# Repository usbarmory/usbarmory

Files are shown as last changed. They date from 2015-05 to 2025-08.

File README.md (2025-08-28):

Introduction
============

The USB armory is an open source hardware design, implementing a compact secure
computer.

This repository is aimed towards developers, if you wish to purchase a USB
armory board please see the [ordering information](https://github.com/usbarmory/usbarmory/wiki/Ordering-information).

Authors
=======

Andrea Barisani  
andrea@inversepath.com  

Andrej Rosano  
andrej@inversepath.com  

Daniele Bianco  
daniele@inversepath.com  

Documentation
=============

The main documentation can be found on the
[project wiki](https://github.com/usbarmory/usbarmory/wiki).

Board models
============

* [USB armory Mk II LAN](https://github.com/usbarmory/usbarmory/wiki/Mk-II-LAN)

Mk II LAN Top
Mk II LAN PoE

* [USB armory Mk II](https://github.com/usbarmory/usbarmory/wiki/Mk-II-Introduction)

Mk II Top
Mk II Bottom

* USB armory Mk I

USB armory Mk I

License
=======

USB armory | https://github.com/usbarmory/usbarmory  
Copyright (c) The USB armory authors

This is an open hardware design licensed under the terms of the CERN Open
Hardware Licence, see board revisions for applicable versions.

This source is distributed WITHOUT ANY EXPRESS OR IMPLIED WARRANTY, INCLUDING
OF MERCHANTABILITY, SATISFACTORY QUALITY AND FITNESS FOR A PARTICULAR PURPOSE.

Please see LICENSE files in each source subdirectory for applicable conditions.

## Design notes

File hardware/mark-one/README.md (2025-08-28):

Introduction
============

The USB armory is an open source hardware design, implementing a flash drive
sized computer.

This repository is aimed towards developers, if you wish to purchase a USB
armory board please see the [ordering information](https://github.com/usbarmory/usbarmory/wiki/Ordering-information).

Authors
=======

Andrea Barisani  
andrea@inversepath.com  

Andrej Rosano  
andrej@inversepath.com  

Daniele Bianco  
daniele@inversepath.com  

Revision information
====================

This directory contains the hardware design for the USB armory board, first
revision (Mark I).

Current schematics and layout files have been designed in KiCad (`release
2014-01-25 - 0.201403191418+4754~10~ubuntu12.04.1`)

PCB information
===============

Mk I Top
Mk I Bottom

6 layers, 2.00mm thickness  
Outer layers 0.5 oz base copper foil  
Inner layers   1 oz base copper foil  
width (X) 65.6 mm, height (Y) 19.5 mm  
Electroless Nickel Immersion Gold (ENIG) surface finish  
Selective hard gold (min 0.75um) plating for J2 (USB)  
Black resist, white component legend

Layers
------

Order and type of copper layers:  
  TOP:         signal, front components  
  SIGNAL 1:    signal  
  GND POWER 1: ground and power plane  
  GND POWER 2: ground and power plane  
  SIGNAL 2:    signal  
  BOTTOM:      signal, back components  

| Layer | Description |  Thickness (in um)  |
|:-----:|---|:---:|
| | LPI mask | 15 |
| | ENIG plating | 18 |
| 1 | copper | 17 |
| | prepreg, 3 x PP 1080 |  240 -> 220 |
| 2 | copper | 35 |
| | core, FR4  35/35 |  300 |
| 3 | copper | 35 |
| | prepreg, 4 x PP 7628 |  760 -> 720 |
| 4 | copper | 35 |
| | core, FR4  35/35 |  300 |
| 5 | copper | 35 |
| | prepreg, 3 x PP 1080 |  240 -> 220 |
| 6 | copper | 17 |
| | ENIG plating | 18 |
| | LPI mask | 15 |

Material: Isola PCL370-HR
Total thickness: 2.0 mm

DRC information
---------------

Minimum track width:            0.127 mm  
Minimum via diameter:           0.406 mm  
Outer layer track width:        0.127 mm  
Outer layer isolation distance: 0.127 mm  
Outer layer annular ring:       0.075 mm  
Inner layer track width:        0.127 mm  
Inner layer isolation distance: 0.127 mm  
Inner layer annular ring:       0.075 mm  
Smallest final hole (plated):   0.150 mm

Regulatory compliance & handling
================================

The USB armory board is intended for use as a development platform for hardware
or software. The board is an open system design, which does not include a
shielded enclosure. This may cause interference to other electrical or
electronic devices in close proximity. In a domestic environment, this product
may cause radio interference in which case the user may be required to take
adequate measures. In addition, this board should not be used near any medical
equipment or RF devices.

The board is sensitive to ESD. Hold the board only by its edges. After removing
the board from its box, place it on a grounded, static-free surface.

The board can become hot, like any fan-less design, during continuous high CPU
loads, mind its temperature while handling it.

License
=======

USB armory | https://github.com/usbarmory/usbarmory  
Copyright (c) The USB armory authors

This is an open hardware design licensed under the terms of the CERN Open
Hardware Licence (OHL) v1.2.

You may redistribute and modify this documentation under the terms of the CERN
OHL v.1.2 (http://ohwr.org/cernohl). This documentation is distributed WITHOUT
ANY EXPRESS OR IMPLIED WARRANTY, INCLUDING OF MERCHANTABILITY, SATISFACTORY
QUALITY AND FITNESS FOR A PARTICULAR PURPOSE. Please see the CERN OHL v.1.2 for
applicable conditions.

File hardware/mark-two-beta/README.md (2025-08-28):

Introduction
============

The USB armory is an open source hardware design, implementing a flash drive
sized computer.

This repository is aimed towards developers, if you wish to purchase a USB
armory board please see the [ordering information](https://github.com/usbarmory/usbarmory/wiki/Ordering-information).

Authors
=======

Andrea Barisani  
andrea@inversepath.com  

Andrej Rosano  
andrej@inversepath.com  

Daniele Bianco  
daniele@inversepath.com  

Documentation
=============

The main documentation can be found on the
[project wiki](https://github.com/usbarmory/usbarmory/wiki).

Revision information
====================

This directory contains the hardware design for the USB armory Mk II rev. β.

Current schematics and layout files have been designed in KiCad 5.1.4.

PCB Information
===============

Mk II Top
Mk II Bottom

6 layers, 0.8mm thickness  
Outer layers 0.5 oz base copper foil  
Inner layers   1 oz base copper foil  
width (X) 65.6 mm, height (Y) 19.5 mm  
Electroless Nickel Immersion Gold (ENIG) surface finish  
Black resist, white component legend

Layers
------

Order and type of copper layers:  
  TOP:         signal, front components  
  SIGNAL 1:    signal  
  GND POWER 1: ground and power plane  
  GND POWER 2: ground and power plane  
  SIGNAL 2:    signal  
  BOTTOM:      signal, back components  

| Layer | Description |  Thickness (in um)  |
|:-----:|---|:---:|
| | LPI mask | 15 |
| | ENIG plating | 18 |
| 1 | copper | 30 |
| | prepreg, 2 x PP 106 |  121 |
| 2 | copper | 17 |
| | core, FR4 17/17 |  125 |
| 3 | copper | 17 |
| | prepreg, 2 x PP 106 |  116 |
| 4 | copper | 17 |
| | core, FR4 17/17 |  125 |
| 5 | copper | 17 |
| | prepreg, 2 x PP 106 |  121 |
| 6 | copper | 30 |
| | ENIG plating | 18 |
| | LPI mask | 15 |

Material: Isola PCL370-HR
Total thickness: 0.8 mm

DRC information
---------------

Minimum track width:            0.100 mm  
Minimum via diameter:           0.406 mm  
Outer layer track width:        0.100 mm  
Outer layer isolation distance: 0.100 mm  
Outer layer annular ring:       0.075 mm  
Inner layer track width:        0.100 mm  
Inner layer isolation distance: 0.100 mm  
Inner layer annular ring:       0.075 mm  
Smallest final hole (plated):   0.150 mm

Regulatory compliance & handling
================================

The USB armory board is an open system design, which does not include a
shielded enclosure. This may cause interference to other electrical or
electronic devices in close proximity. In a domestic environment, this product
may cause radio interference in which case the user may be required to take
adequate measures. In addition, this board should not be used near any medical
equipment or RF devices.

The board is sensitive to Electrostatic discharge (ESD). Hold the board only by
its edges. After removing the board from its box, place it on a grounded,
static-free surface.

The board can become hot, like any fan-less design, during continuous high CPU
loads, mind its temperature while handling it.

* [Compliance information](https://github.com/usbarmory/usbarmory/wiki/Compliance-information)

License
=======

USB armory | https://github.com/usbarmory/usbarmory  
Copyright (c) The USB armory authors

This is an open hardware design licensed under the terms of the CERN Open
Hardware Licence (OHL) v1.2.

You may redistribute and modify this documentation under the terms of the CERN
OHL v.1.2 (http://ohwr.org/cernohl). This documentation is distributed WITHOUT
ANY EXPRESS OR IMPLIED WARRANTY, INCLUDING OF MERCHANTABILITY, SATISFACTORY
QUALITY AND FITNESS FOR A PARTICULAR PURPOSE. Please see the CERN OHL v.1.2 for
applicable conditions.

The following exceptions apply:

- `../lib.snapeda`: all files in this directory are imported or modified
  from SnapEDA symbols and footprints, therefore the license at
  https://www.snapeda.com/about/FAQ/#license applies.

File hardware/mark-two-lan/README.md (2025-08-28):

Introduction
============

The USB armory is an open source hardware design, implementing a compact secure
computer.

This repository is aimed towards developers, if you wish to purchase a USB
armory board please see the [ordering information](https://github.com/usbarmory/usbarmory/wiki/Ordering-information).

Authors
=======

Andrea Barisani  
andrea@inversepath.com  

Andrej Rosano  
andrej@inversepath.com  

Daniele Bianco  
daniele@inversepath.com  

Documentation
=============

The main documentation can be found on the
[project wiki](https://github.com/usbarmory/usbarmory/wiki).

Revision information
====================

This directory contains the hardware design for the USB armory Mk II LAN rev. β.

Current schematics and layout files have been designed in KiCad 7.0.3.

PCB Information
===============

 

6 layers, 0.8mm thickness  
Outer layers 0.5 oz base copper foil  
Inner layers   1 oz base copper foil  
width (X) 65.6 mm, height (Y) 19.5 mm  
Electroless Nickel Immersion Gold (ENIG) surface finish  
Black resist, white component legend

Layers
------

Order and type of copper layers:  
  TOP:         signal, front components  
  SIGNAL 1:    signal  
  GND POWER 1: ground and power plane  
  GND POWER 2: ground and power plane  
  SIGNAL 2:    signal  
  BOTTOM:      signal, back components  

| Layer | Description |  Thickness (in um)  |
|:-----:|---|:---:|
| | LPI mask | 15 |
| | ENIG plating | 18 |
| 1 | copper | 30 |
| | prepreg, 2 x PP 106 |  121 |
| 2 | copper | 17 |
| | core, FR4 17/17 |  125 |
| 3 | copper | 17 |
| | prepreg, 2 x PP 106 |  116 |
| 4 | copper | 17 |
| | core, FR4 17/17 |  125 |
| 5 | copper | 17 |
| | prepreg, 2 x PP 106 |  121 |
| 6 | copper | 30 |
| | ENIG plating | 18 |
| | LPI mask | 15 |

Material: Isola PCL370-HR
Total thickness: 0.8 mm

DRC information
---------------

Minimum track width:            0.100 mm  
Minimum via diameter:           0.406 mm  
Outer layer track width:        0.100 mm  
Outer layer isolation distance: 0.100 mm  
Outer layer annular ring:       0.050 mm  
Inner layer track width:        0.100 mm  
Inner layer isolation distance: 0.100 mm  
Inner layer annular ring:       0.050 mm  
Smallest final hole (plated):   0.127 mm

Regulatory compliance & handling
================================

The USB armory board is an open system design, which does not include a
shielded enclosure. This may cause interference to other electrical or
electronic devices in close proximity. In a domestic environment, this product
may cause radio interference in which case the user may be required to take
adequate measures. In addition, this board should not be used near any medical
equipment or RF devices.

The board is sensitive to Electrostatic discharge (ESD). Hold the board only by
its edges. After removing the board from its box, place it on a grounded,
static-free surface.

The board can become hot, like any fan-less design, during continuous high CPU
loads, mind its temperature while handling it.

* [Compliance information](https://github.com/usbarmory/usbarmory/wiki/Compliance-information)

License
=======

USB armory | https://github.com/usbarmory/usbarmory  
Copyright (c) The USB armory authors

This source describes Open Hardware and is licensed under the CERN-OHL-S v2.

You may redistribute and modify this source and make products using it under
the terms of the CERN-OHL-S v2 (https://ohwr.org/cern_ohl_s_v2.txt).

This source is distributed WITHOUT ANY EXPRESS OR IMPLIED WARRANTY, INCLUDING
OF MERCHANTABILITY, SATISFACTORY QUALITY AND FITNESS FOR A PARTICULAR PURPOSE.
Please see the CERN-OHL-S v2 for applicable conditions.

As per CERN-OHL-S v2 section 4, should You produce hardware based on this
source, You must where practicable maintain the Source Location visible on the
external case of the USB armory or other products you make using this source.

The following exceptions apply:

- `../lib.snapeda`: all files in this directory are imported or modified
  from SnapEDA symbols and footprints, therefore the license at
  https://www.snapeda.com/about/FAQ/#license applies.

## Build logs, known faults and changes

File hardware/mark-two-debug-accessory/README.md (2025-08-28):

USB armory Mk II debug accessory
================================

The USB armory is an open source hardware design, implementing a flash drive
sized computer.

The USB armory Mk II exposes a USB Type-C receptacle, which allows through the
so called USB-C 'debug accessory mode' to route analog/debug signals over its
connector, the USB armory Mk II design leverages on this to break out UART,
SPI, I²C, CAN (pre-transceiver), GPIOs connections to/from its application
processor.

The debug accessory board allows to access UART and GPIO signals through USB,
without requiring probes, through an FTDI FT4232H. This allows, for example,
access to the USB armory Mk II serial console without wires or probes, natively
using only USB cables. All other interfaces can be accessed through dedicated
breakout through holes.

This repository is aimed towards developers, if you wish to purchase a USB
armory board please see the [USB armory documentation](https://github.com/usbarmory/usbarmory/wiki).

Mk II debug accessory

PCB Information
===============

Mk II debug accessory

2 layers, 0.80mm thickness, top only components  
Outer layers 0.5 oz base copper foil  
Inner layers   1 oz base copper foil  
width (X) 45.65 mm, height (Y) 25.90 mm  
Red soldermask, white component legend

[Bill of materials](https://usbarmory.github.io/BOM/usbarmory-mark-two-debug-accessory.html)

DRC information
---------------

Minimum track width:            0.127 mm  
Minimum via diameter:           0.450 mm  
Outer layer track width:        0.127 mm  
Outer layer isolation distance: 0.127 mm  
Outer layer annular ring:       0.100 mm  
Smallest final hole (plated):   0.150 mm

Errata
------

The silkscreen labels for `3.3V` and `5V` are inverted on all rev v1 PCBs, see
this [issue](https://github.com/usbarmory/usbarmory/issues/68).

USB armory Mk II debug I/Os
===========================

*NOTE*: the connection between the debug accessory and the target is supported
only with the same orientation for both top layers (side with components for
the accessory, side with LEDs for the USB armory).

The following table summarizes the available configurations on the USB armory
Mk II through debug accessory mode, which are exposed on its Type-C receptacle
port.

|  USB-C pin | MUX mode ALT0 | MUX mode ALT8 | MUX mode ALT2 | MUX mode ALT5 |
|:---|---|---|---|---|
| SSTXp1 (A2)  | UART2_TX | ECSPI3_SSO¹ | I2C4_SCL¹ | GPIO1_IO20 |
| SSTXn1 (A3)  | UART2_RX | ECSPI3_SCLK¹  | I2C4_SDA¹ | GPIO1_IO21 |
| SSRXp1 (B11) | UART2_RTS_B | ECSPI3_MISO¹  | FLEXCAN2_RX¹  | GPIO1_IO23 |
| SSRXn1 (B10) | UART2_CTS_B | ECSPI3_MOSI¹  | FLEXCAN2_TX¹  | GPIO1_IO22 |
| SSRXp2 (A11) | UART4_TX | ECSPI2_SCLK | I2C1_SCL | GPIO1_IO28 |
| SSTXn2 (B3)  | UART4_RX | ECSPI2_SSO | I2C1_SDA | GPIO1_IO29 |
| SSRXn2 (A10) | UART5_TX~ | ECSPI2_MOSI | I2C2_SCL | GPIO1_IO30 |
| SSTXp2 (B2)  | UART5_RX~ | ECSPI2_MISO | I2C2_SDA | GPIO1_IO31 |

¹ Only on USB armory Mk II boards mounting i.MX6UL SoC, not available on
  versions mounting the i.MX6ULZ.

Serial console
--------------

When running the [USB armory Debian base image](https://github.com/usbarmory/usbarmory-debian-base_image/releases)
the serial console (UART2) can be accessed, with the debug accessory jumper set to UART
position, as follows (example on Linux host with picocom):

```
picocom -b 115200 -eb /dev/ttyUSB2 --imap lfcrlf
```

Debug accessory jumper settings
===============================

Power source
------------

The debug accessory always acts as a power source and is meant to be connected
exclusively to the USB armory Mk II Type-C receptacle port. The USB armory Mk
II Type-C can be safely plugged on a different receptacle as the board can
handle two power sources simultaneously.

It is not recommended to connect the debug accessory to anything other than the
USB armory Mk II, however in case this happens compliant Type-C receptacles
should handle the situation gracefully¹ without concerns.

¹ USB Type-C Cable and Connector Specification (1.3, 2017-07-14):
  "Legacy hosts/chargers that by default source VBUS when connected using any
  legacy USB connector (Standard-A, Micro-B, etc.) to USB Type-C cable or adapter
  are exempted from these two requirements."

I/O mode
--------

The GPIO and UART functions can be used directly using the FTDI FT4232H USB
interface accessible on the Micro USB Type-B connector, all other modes can be
accessed using the exposed breakout through holes.

The following table illustrates the required jumper positions and interfaces
for each available I/O mode.

| Mode  | GPIO¹ | Interface
|:---|---|---|
| GPIO  |  GPIO | FTDI MPSSE mode on [A,B]DBUS[4-7] |
| UART2 | !GPIO | FTDI RS232 mode on CDBUS[0-3] |
| UART4 | !GPIO | FTDI RS232 mode on BDBUS[0-1] |
| UART5 | !GPIO | FTDI RS232 mode on ADBUS[0-1] |
| SPI2  |  N/A² | through holes: A11, B3, A10, B2 |
| SPI3  |  N/A² | through holes: A2,  A3, B11, B10  |
| I2C1  |  N/A² | through holes: A11, B3 |
| I2C2  |  N/A² | through holes: A10, B2 |
| I2C4  |  N/A² | through holes: A2,  A3 |
| CAN2  |  N/A² | through holes: B11, B10 |

¹ The GPIO header position refers to termination either of the two pins facing
  the "GPIO" label (GPIO position, pins towards positions 3 and 2) or the
  opposite position (!GPIO position, pins towards positions 2 and 1).

² Any position can be used as the FTDI is not used in such mode.

Pin assignment: GPIO
====================

|  USB-C pin | i.MX6UL pin | FTDI pin | FTDI MPSSE |
|:---|---|---|---|
| SSTXp1 (A2)  | GPIO1_IO20  | BDBUS6 | #B GPIOL2  |
| SSTXn1 (A3)  | GPIO1_IO21  | BDBUS7 | #B GPIOL3  |
| SSRXp1 (B11) | GPIO1_IO23  | BDBUS5 | #B GPIOL1  |
| SSRXn1 (B10) | GPIO1_IO22  | BDBUS4 | #B GPIOL0  |
| SSRXp2 (A11) | GPIO1_IO28  | ADBUS4 | #A GPIOL0  |
| SSTXn2 (B3)  | GPIO1_IO29  | ADBUS7 | #A GPIOL3  |
| SSRXn2 (A10) | GPIO1_IO30  | ADBUS5 | #A GPIOL1  |
| SSTXp2 (B2)  | GPIO1_IO31  | ADBUS6 | #A GPIOL2  |

Pin assignment: UART2
=====================

|  USB-C pin | i.MX6UL pin  | FTDI pin | FTDI MPSSE |
|:---|---|---|---|
| SSTXp1 (A2)  | UART2_TX | CDBUS1 | #C RXD |
| SSTXn1 (A3)  | UART2_RX | CDBUS0 | #C TXD |
| SSRXp1 (B11) | UART2_RTS_B¹ | CDBUS3 | #C CTS |
| SSRXn1 (B10) | UART2_CTS_B¹ | CDBUS2 | #C RTS |

¹ On USB armory Mk II rev. β see the [related errata](https://github.com/usbarmory/usbarmory/wiki/Errata-(Mk-II)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).

Pin assignment: UART4
=====================

|  USB-C pin | i.MX6UL pin | FTDI pin | FTDI MPSSE |
|:---|---|---|---|
| SSRXp2 (A11) | UART4_TX | BDBUS1 | #B RXD |
| SSTXn2 (B3)  | UART4_RX | BDBUS0 | #B TXD |

Pin assignment: UART5
=====================

|  USB-C pin | i.MX6UL pin | FTDI pin | FTDI MPSSE |
|:---|---|---|---|
| SSRXn2 (A10) | UART5_TX | ADBUS1 | #A RXD |
| SSTXp2 (B2)  | UART5_RX | ADBUS0 | #A TXD |

Physical access: UART2
======================

When no debug accessory is available, the serial console (UART2) can be also
accessed with a USB-C plug breakout and a USB to 3.3 TTL serial cable with the
following configuration.

|  PIN | Config |
|:---|---|
| A4, A5 | 56 kOhm |
| B4, B5 | 56 kOhm |
| A2, A3 | 3.3V UART TX/RX |
| A4 | 5V |
| A1 | GND |

License
=======

USB armory | https://github.com/usbarmory/usbarmory  
Copyright (c) The USB armory authors

This is an open hardware design licensed under the terms of the CERN Open
Hardware Licence (OHL) v1.2.

You may redistribute and modify this documentation under the terms of the CERN
OHL v.1.2 (http://ohwr.org/cernohl). This documentation is distributed WITHOUT
ANY EXPRESS OR IMPLIED WARRANTY, INCLUDING OF MERCHANTABILITY, SATISFACTORY
QUALITY AND FITNESS FOR A PARTICULAR PURPOSE. Please see the CERN OHL v.1.2 for
applicable conditions.

The following exceptions apply:

- `../lib.snapeda`: all files in this directory are imported or modified
  from SnapEDA symbols and footprints, therefore the license at
  https://www.snapeda.com/about/FAQ/#license applies.

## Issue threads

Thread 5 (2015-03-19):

IP in your example images

pmpbar, 2015-03-19:
Hello,
Love the product. However, using the default IP that the device is hosted at causes problems when the external network passes out IP's in a weird fashion at my University(extended network with lots of routers). 10.0.0.1 is a hidden IP so when I connect (with internet sharing on) two either the internet or the armory then the other system the ssh connection hoses. If you changed the IP of the device to something other than a gateway address this might solve the problem. Maybe this is just a special case. I'm on a Macbook Pro using your mk1 board. Let me know if I am doing something wrong or if this is just a special case.

danbia, 2015-03-19:
Conflicts in IP addresses might always happen no matter which one we select, the right course of action is not for us to change the IP address on the default image, but rather for you to change it to something that suits your network environment.

Please connect to the USB armory, become administrator and change the default configuration in /etc/network/interfaces to an IP address compatible with your environment.

pmpbar, 2015-03-19:
Sounds good! Just thought I would bring it to your attention

pmpbar, 2015-03-19:
After testing on a different network, this is not because of the IP. It is because osx is switching the requests to a different interface I think. I cannot login as long as the computer is connected to a network. Even if I am ssh'd in, after I connect to a network the connection hoses

abarisani, 2015-03-19:
This still indicates some conflict in your network configuration, if the subnet of your Internet/LAN connection and the USB armory one are different then there is no conflict and you can use both connections at the same time.

In fact if you assign an IP address between the range 192.168.2.2-192.168.2.254 to the armory interface, and use 192.168.2.1 as default gateway, you can even share your Internet connection with the USB armory on MAC OS X.

Closed 2015-03-19.

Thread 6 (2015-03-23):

Getting Started page

rkt88edmo, 2015-03-23:
"MPORTANT: please note that the microSD slot is with "hinge" type insertion and not a pull-push slot. In order to open it gently ****lift**** the closed metal hinge towards the opposite direction of the little arrow engraved on it, a small "click" indicates successful opening."

Using "lift" is confusing, you need to "slide" the metal tab to unlock it prior to lifting.  Just a wording suggestion.

abarisani, 2015-03-23:
Fixed. Thanks.

Closed 2015-03-23.

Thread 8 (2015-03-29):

Connecting

darakian, 2015-03-29:
Hi guys. I downloaded the default image and dd'd it to my sdcard as the instructions state here
http://dev.inversepath.com/download/usbarmory/
When I connect my armory to my laptop (fedora 21) I get a new network device (enp0s26u1u2), but I sshing to 10.0.0.1 fails. I have no route to that address and I'm wondering if I need to set up the route manually. Any thoughts?

Edit:
Tried to add a route via
route add -net 10.0.0.0 netmask 255.255.255.0 gw 10.0.0.2 dev enp0s26u1u2
and I get back
SIOCADDRT: Network is unreachable

andrejro, 2015-03-29:
Hi,
did you assign the address to the network interface?

ifconfig enp0s26u1u2 10.0.0.2 netmask 255.255.255.0

darakian, 2015-03-30:
I had not. That got a response, but now ssh doesn't seem to connect. I get the key exchange, I accept the key, and then nothing. Web interface is also non-responsive.The SSH key comes up as ECDSA, is this maybe not supported by the fedora config of openssh?

abarisani, 2015-03-30:
On Sun, Mar 29, 2015 at 05:28:33PM -0700, Jon Moroney wrote:
> I had not. That got a response, but now ssh doesn't seem to connect. I get the key exchange, I accept the key, and then nothing. Web interface is also non-responsive.The SSH key comes up as ECDSA, is this maybe not supported by the fedora config of openssh?
>

Could you please cut & paste the output of the ssh exchange (including the
ssh command used) as well as the one from the following commands (executed
as root or with sudo):

ip addr
ip route

darakian, 2015-03-31:
@abarisani The issue was resolved. It turns out that network manager was overwriting the ip info that I had given to the interface. Adding the IP info via network manager solved this.

abarisani, 2015-03-31:
Excellent, thanks for the update.

Closed 2015-03-31.

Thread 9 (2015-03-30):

Some commentary on preparing bootable sd cards

ckuethe, 2015-03-30:
It is not necessary to install ia32 libraries on recent versions of ubuntu (and probably debian too) if the cross-compilers are new enough.

Ubuntu 15.04 development releases work as a cross-development platform.

In the instructions for preparing debian images you should add "fake-hwclock" to the list of packages to install. This will store a timestamp in the filesystem at reasonable intervals and restore it at boot, so that time isn't reset to the epoch at power loss... https://packages.debian.org/wheezy/admin/fake-hwclock

Additionally, it may be worth mentioning "mg" for people who like emacs... https://packages.debian.org/wheezy/editors/mg

Also, it would be more portable to use "printf" rather than "echo -e" in the instructions.

abarisani, 2015-04-01:
Installing ia32 doesn't hurt and ensures little more compatibility, I'd rather keep that.

I changed the FAQ to include fake-hwclock and I also added it to the preparation instructions.

Regarding "mg" I don't want to enter the rabbit hole of adding a lot of default packages, I think people that require some would be expert enough to add them during the installation procedure or afterwards ;).

As "printf" behaves different than "echo -e", and considering that the instructions are meant for Debian or Ubuntu anyway, meaning there would be other portability issues, I'd rather keep it as it is.

Thanks!

Closed 2015-04-01.

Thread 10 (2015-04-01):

Instructions to connect via serial

keichi, 2015-04-01:
Could you provide me instructions on how to connect to the USB Armory via serial over USB? I read [this](https://github.com/inversepath/usbarmory/wiki/Host-communication) wiki page, but it does not mention about USB serial.

abarisani, 2015-04-01:
The Arch Linux USB armory images uses serial + ethernet emulated over USB, this is accomplished using the g_cdc module instead of g_ether. When switching to g_cdc just remember that the use_eem option is not available and that it is untested if the driver would be correctly detected by Linux/OSX hosts as well.

If you just want serial then the module g_serial should work.

abarisani, 2015-04-01:
I think such questions are better suited for the discussion group (https://groups.google.com/d/forum/usbarmory) rather than issues. If you have further troubles kindly follow up there. Thanks!

Closed 2015-04-01.

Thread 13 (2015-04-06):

Modprobing cpufreq-dt crashes machine

bgamari, 2015-04-06:
I built a 3.19 kernel using the defconfig provided in the repository hoping to enable CPU frequency modulation to reduce the idle temperature of the device. The resulting kernel booted perfectly but `modprobe cpufreq-dt` caused the device to reboot, I believe due to the watchdog timer. I haven't yet had an opportunity to check for output on the serial console.

abarisani, 2015-04-06:
I think the dtb might not be configured correctly for this, we'll take a look and get back to you.

abarisani, 2015-04-08:
I just compiled kernel 3.19.3 using the configuration at https://github.com/inversepath/usbarmory/blob/master/software/kernel_conf/usbarmory_linux-3.19.config and by adding CONFIG_PM_DEVFREQ=y (which I am not sure it makes a difference).

The module cpufreq-dt loads fine, I do see the following error message:

cpu cpu0: dev_pm_opp_get_opp_count: device OPP not found (-19)

which according to http://lists.infradead.org/pipermail/linux-arm-kernel/2014-June/266751.html seems harmless, however I am currently investigating this.

abarisani, 2015-04-08:
Sorry the OPP error was due to me not updating the dtb. Not only I have cpufreq-dt running just fine but, since it sets maximum clock at 1.2 GHz, now I also get better performance.

Here's what happens with cpufreq-dt and governor_powersave loaded:

Idle:
# cat /sys/devices/system/cpu/cpu0/cpufreq/cpuinfo_cur_freq
166665

During 'openssl speed -elapsed -evp aes-128-cbc':
# cat /sys/devices/system/cpu/cpu0/cpufreq/cpuinfo_cur_freq
1200000

abarisani, 2015-04-08:
We are currently testing if 1.2 GHz is safe with the specific i.MX53 model that we mount on the USB armory (probably not), we will cap it to 1.0 GHz were necessary.

abarisani, 2015-04-08:
The default Linux dts allows for 1.2 GHz frequency on all i.MX53 models, this is not a safe speed for the SoC part number mounted on the USB armory and in fact it leads to segmentation faults while compiling.

1.0 GHz is possible on the specific model mounted in the USB armory production batch (in fact I have been using 1.0 GHz speed set by u-boot for several months without any issue), however this frequency is not the one officially advertised by Freescale for the part number.

(The clock without cpufreq-dt is forced to 800 MHz so currently these are not issues that apply)

While the maximum allowed frequency can be set via sysfs commands there is always a time window, between cpufreq-dt loading and sysfs configuration, where on heavy load the clock might hit 1.2 GHz and cause issues. For this reason we will modify the default dts with 800 MHz as the maximum operating clock to be used when cpufreq-dt is loaded.

We are going to update our default base images with the dts and updated kernel configuration and include the "ondemand" governor active by default. I will close the issue once the image is up.

abarisani, 2015-04-09:
Our updated image has been uploaded and is available at http://dev.inversepath.com/download/usbarmory.

It includes working cpufreq-dt as described.

Cheers

Closed 2015-04-09.

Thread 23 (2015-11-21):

can not connect over ssh

jmartiuk5, 2015-11-21:
O.k so I'm running ubuntu 15.10 I just obtained my mk 1 today I flashed the base image myself I did not order one with it. I currently have a kernel heartbeat. Here is my dmesg output.

cdc_ether 2-2:1.0 enx1a5589a26942: unregister 'cdc_ether' usb-0000:00:1d.7-2, CDC Ethernet Device
[90108.136127] usb 2-2: new high-speed USB device number 6 using ehci-pci
[90108.283163] usb 2-2: New USB device found, idVendor=0525, idProduct=a4a2
[90108.283170] usb 2-2: New USB device strings: Mfr=1, Product=2, SerialNumber=0
[90108.283175] usb 2-2: Product: RNDIS/Ethernet Gadget
[90108.283179] usb 2-2: Manufacturer: Linux 4.2.1 with 53f80000.usb
[90108.298210] cdc_ether 2-2:1.0 usb0: register 'cdc_ether' at usb-0000:00:1d.7-2, CDC Ethernet Device, 1a:55:89:a2:69:42
[90108.333967] cdc_ether 2-2:1.0 enx1a5589a26942: renamed from usb0
[90108.412743] IPv6: ADDRCONF(NETDEV_UP): enx1a5589a26942: link is not ready
[90108.412995] cdc_ether 2-2:1.0 enx1a5589a26942: kevent 12 may have been dropped
[90108.427031] IPv6: ADDRCONF(NETDEV_UP): enx1a5589a26942: link is not ready
[90111.650316] IPv6: ADDRCONF(NETDEV_CHANGE): enx1a5589a26942: link becomes ready
[90111.650334] cdc_ether 2-2:1.0 enx1a5589a26942: kevent 12 may have been dropped
[90157.041116] cdc_ether 2-2:1.0 enx1a5589a26942: kevent 12 may have been dropped
[90157.041126] cdc_ether 2-2:1.0 enx1a5589a26942: kevent 12 may have been dropped
[90157.041629] cdc_ether 2-2:1.0 enx1a5589a26942: kevent 12 may have been dropped

ubuntu also does not name this usb0 as you can see. I followed all steps.
I couldn't find an incident like mine listed. Thank you in advance for any help.

jmartiuk5, 2015-11-21:
Ok so I officially confused, ok so I shut down my network-manager followed the steps once again and then restarted my network manager, after that I tried to ssh into 10.0.0.2 and it still did not work. I then for reasons unknown try to ssh into 10.0.0.1 and was successful and with an ifconfig command it clearly shows it as 10.0.0.2. I am confused but I'm in either way. Thanks again for this great product.

abarisani, 2015-11-21:
Glad you sorted it out, also keep in mind that you can prevent renaming via udev rules, usually with something like this in /etc/udev/rules.d/10-network.rules:

SUBSYSTEM=="net", ACTION=="add", ATTR{address}=="aa:bb:cc:dd:ee:ff", NAME="usb0"

Where "aa:bb:cc:dd:ee:ff" must be changed with your USB armory MAC address, if using the default Debian image the MAC is 1a:55:89:a2:69:42.

Cheers

jmartiuk5, 2015-11-21:
Thanks for that I'm obviously not a linux ninja yet. That actually helps a lot I couldn't stand to type or paste that name again.

-James

Closed 2015-11-21.

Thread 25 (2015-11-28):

Typo in wiki "brigthness"

luke-jr, 2015-11-28:
https://github.com/inversepath/usbarmory/wiki/GPIOs#led-control seems to misspell brightness?

abarisani, 2015-11-29:
Thanks for spotting this! Fixed now.

Closed 2015-11-29.

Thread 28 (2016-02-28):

usbarmory bill of materials

limpkin, 2016-02-28:
Hello everyone,

It seems the BoM can't be found anywhere?

andrejro, 2016-02-28:
You can export the BoM directly from the KiCad project.
From Eeschema: Tools-> Generate Bill of Materials

Closed 2016-02-28.

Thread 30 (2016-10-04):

usb gadget g_ether on windows 10 (kali-linux)

wolfff, 2016-10-04:
Windows 10 tends to detect the g_ether as remote NDIS device with some serial driver.
As a workaround, instead of using g_ether in /etc/modules, use the script
[ev3-usb.sh]( https://raw.githubusercontent.com/ev3dev/ev3-systemd/ev3dev-jessie/scripts/ev3-usb.sh )
and change the first lines into:

```
g=/sys/kernel/config/usb_gadget/g1
device="ci_hdrc.0"
```

and than call this script from e.g. rc.local as
```
# Load USB Ethernet Gadget
/usr/local/sbin/usb-gadget_eth up
```

before starting dhcpd or doing other (nasty?) things...

Maybe this could be added to your wiki.

Cheers,

Florian.

wolfff, 2016-10-07:
You are right, the referred script needs a cleanup. If I'll find some time, I might provide an update.
However on some systems, the usage of g_ether lead to usbser.sys (as usbser.inf binds a very generic USB\Class_02&SubClass_02), which is obviously wrong. Installing the mentioned driver from Acer helps, but in some use cases manual installation of additional drivers is not appropriate/possible.

abarisani, 2016-10-10:
Thanks!

I am closing this issue for now, please re-open if/when you have a script to test.

Closed 2016-10-10.

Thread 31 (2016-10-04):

Preparing a bootable microSD image - chroot commands dont work

jgriffiths, 2016-10-04:
Hi,

Building an image on Sid here.

The chroot commands listed don't work due to the ABI difference between host and chroot. Perhaps something is missing from the instructions: the command `sudo rm ${TARGET_MNT}/usr/bin/qemu-arm-static` does nothing as that file doesn't exist. Were the chroot commands meant to run under emulation? Regardless, the commands aren't needed as they can be done from the host:

`sudo chroot $TARGET_MNT systemctl mask getty-static.service` etc can be replaced with `ln -sf` of the service files to `/dev/null`, although all services were already masked in my case.

`sudo chroot $TARGET_MNT /usr/sbin/useradd -s /bin/bash -p $(sudo chroot $TARGET_MNT mkpasswd -m sha-512 usbarmory) -m usbarmory` can be replaced with the hosts useradd command by passing `-R $TARGET_MNT` to alter files in the chroot.

andrejro, 2016-10-05:
Hi,
yes, the chroot is run under emulation and that is why the "/usr/bin/qemu-arm-static" should be present
in the target root file system and removed only when everything is set up. It should be created by
qemu-bootstrap command, I wonder why you do not have it. I just tested the procedure with no troubles under Debian/sid.

Can you please retry?
Thanks

Closed 2016-10-14.

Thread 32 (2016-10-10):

Connecting to the device on OSX

dhruvasagar, 2016-10-10:
Hi,

I am observing a strange problem where, every time I connect the device I need to reconfigure the network settings (as per https://github.com/inversepath/usbarmory/wiki/Host-communication).

It works the first time I set it up, but if I reboot the device / remove and insert the device in the usb again it stops working, the only solution I have found so far is to switch the network configuration to DHCP once and then back to manual and apply the settings. But I am having to do this everytime I insert the device into my usb and it's annoying.

Anybody else faced this issue ? Any permanent fix for this ? How can I troubleshoot / identify the source of the problem ?

Edit: I am running Kali Linux on the device.

abarisani, 2016-10-10:
We don't provide support for Kali, but one possibility could be that it is configured to generate a random MAC address each time.

Please ensure that Kali loads the Ethernet emulation driver by forcing a specific MAC address each time.

You can check this on your OS X with 'sudo ifconfig -a'.

We set a fixed MAC in our Debian image with the following line in /etc/modprobe.d/usbarmory.conf (Kali related file location might differ):

options g_ether use_eem=0 dev_addr=1a:55:89:a2:69:41 host_addr=1a:55:89:a2:69:42

dhruvasagar, 2016-10-10:
Sadly I am not able to connect to the device after I added the above mentioned changes.

dhruvasagar, 2016-10-10:
Is it possible to mount the usb armory as a usb device and read the sd card directly ?

abarisani, 2016-10-10:
Which change did you make? Did you verify Kali Linux existing configuration to understand if they were already forcing a MAC?

Looking at https://github.com/offensive-security/kali-arm-build-scripts/blob/master/usbarmory.sh suggests that they were doing so already.

You can easily mount the microSD card partition on a Linux box (with an SD card reader) and revert your changes or you can re-image your microSD card.

I'd recommend using our default Debian image and see if the behavior is identical on your OS X install.

dhruvasagar, 2016-10-10:
I hadn't looked at that, thanks for the link.

I will fix the sd card later at home, right now I don't have the card reader handy.
Although it isn't still clear as to why I had to reconfigure network configuration everytime.

abarisani, 2016-10-10:
Please test with Debian, if it happens as well email directly our support email (you can find it in our wiki default page).

Thanks

dhruvasagar, 2016-10-10:
Ok.

Closed 2016-10-10.

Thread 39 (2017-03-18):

CDC Ethernet and host modes simultaneously?

anatoli26, 2017-03-18:
Hi,

Is it possible to run Armory in CDC Ethernet and host modes _simultaneously_?

My use-case ("firewall/router") would be to make Armory appear to an attached notebook as a USB modem (CDC Ethernet) via which the notebook would connect to internet, and Armory at the same time having some USB WiFi or USB 3G/4G modems connected to have access to internet, so all traffic goes via Armory, no way for the notebook to connect to internet directly.

Is it possible with the current configuration? If I understand it correctly, Armory can work in either mode separately. Could the GPIOs be somehow used to connect the host USB adapter? If not, do you have plans on manufacturing an Armory version that could be used in both modes simultaneously (i.e. connect it to a notebook and attach to it a USB modem)?

andrejro, 2017-03-20:
No, it is not possible.
There is only one USB interface on the USB armory, which can act either as USB host or USB device. There are no USB interfaces exposed on the GPIO header.
There are no plans for now for a new USB armory version.

Closed 2017-03-20.

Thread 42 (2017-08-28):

I can't find the RNDIS adapter in windows

johnreese2017, 2017-08-28:

johnreese2017, 2017-08-28:
In windows 10 the usb armory is always reading as a COM4 AND CAN NOT INSTALL THE RNDIS DRIVER

abarisani, 2017-08-28:
Please follow instructions at:

https://github.com/inversepath/usbarmory/wiki/Host-communication#setup--connection-sharing-windows-7-8-10

Another guide here:

https://docs.google.com/document/d/1tmpF_vVfgff41xGpI9LbVjaIdsEKqzNjau78SuSiIxc/edit

In general such questions are not appropriate for github issues, please use the discussion forum or email our support address directly.

Thanks

szwesleyzhao, 2017-08-29:
Nice to meet you,
Are you outsourcing your CM for project to tooling and production ?
We have been help many projects cutdown production cost and ship on time.
HW is a professional PCB Assembly & EMS factory located in Shenzhen.
We could offer one stop turnkey service

Closed 2017-08-28.

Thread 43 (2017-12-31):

Cannot seem to forward internet on Ubuntu 16.04

onetwopunch, 2017-12-31:
Specs:

- Armory ISO: `usbarmory-debian_jessie-base_image-20170518.raw`
- Host OS: Ubuntu 16.04 using NetworkManager

<hr>

I've been having no end of troubles getting the USB armory to access the internet via my iptables masquerade and wifi. I can ssh into the device just fine, but cannot seem to do things like install tor from apt while connected to the device.

I think my problem is with NetworkManager on the host, so I found [this issue](https://github.com/inversepath/usbarmory/issues/23) and tried to replicate the steps here with NetworkManager stopped then restarted afterward:

```
# bring the USB virtual Ethernet interface up
/sbin/ip link set usb0 up

# set the host IP address
/sbin/ip addr add 10.0.0.2/24 dev usb0

# enable masquerading for outgoing connections towards wireless interface
/sbin/iptables -t nat -A POSTROUTING -s 10.0.0.1/32 -o wlan0 -j MASQUERADE

# enable IP forwarding
echo 1 > /proc/sys/net/ipv4/ip_forward
```
And no luck. I've also tried doing internet sharing directly in the NetworkManager GUI per [this post](https://askubuntu.com/questions/169473/sharing-connection-to-other-pcs-via-wired-ethernet) but also no luck there. I've validated that I can get a ping response from the gateway but nothing else on the device. Any help getting internet forwarding to work would be helpful.

abarisani, 2018-01-08:
Do you maybe have other iptables rules that can prevent this configuration from working?

Can you try disabling any existing firewall rules?

onetwopunch, 2018-01-09:
No I don’t have any other rules in the nat table that would conflict with it. I think it might have something to do with NetworkManager overriding some up forwarding functionality but I have no idea where to look

abarisani, 2018-01-09:
I suggest we take this over email, please email me the output of `iptables -L -n -v -t nat` and `iptables -L -n -v` as well as `ip route` and `ip addr` once the USB armory is connected. Thanks.

elenaf9, 2020-12-11:
@onetwopunch @abarisani
Did you resolve this issue?
I ran into the same problem on Ubuntu 20.04 with the `usbarmory-mark-two-usd-debian_buster-base_image-20201211` image, SSH works but I don't get any internet access.
I tried using the Network Manager GUI as well as the steps described above, but neither worked for me.

elenaf9, 2020-12-13:
Ok so in my case, the Ubuntu firewall was blocking it, I managed to solve it with running the [host-communication instructions](https://github.com/f-secure-foundry/usbarmory/wiki/Host-communication) and then allowing that traffic:
```
iptables -A FORWARD -s 10.0.0.1 -j ACCEPT
```
and restarting the network-manager:
```
service network-manager restart
```

Closed 2018-01-09.

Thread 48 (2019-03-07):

Use of i2c

Yalman, 2019-03-07:
Hi,

if i link "imx53-usbarmory-i2c-4.14.97-0.dtb" instead "imx53-usbarmory.dtb -> imx53-usbarmory-default-4.14.97-0.dtb" the usbarmory wont boot.

With default dtb i try:
root@usbarmory:/home/usbarmory# modprobe i2c-dev
root@usbarmory:/home/usbarmory# i2cdetect -y 0

,-------
|      0  1  2  3  4  5  6  7  8  9  a  b  c  d  e  f
| 00:          -- -- -- -- -- -- -- -- -- -- -- -- --
| 10: -- -- -- -- -- -- -- -- -- -- -- -- -- -- -- --
| 20: -- -- -- -- -- -- -- -- -- -- -- -- -- -- -- --
| 30: -- -- -- -- UU -- -- -- -- -- -- -- -- -- -- --
| 40: -- -- -- -- -- -- -- -- -- -- -- -- -- -- -- --
| 50: -- -- -- -- -- -- -- -- -- -- -- -- -- -- -- --
| 60: -- -- -- -- -- -- -- -- -- -- -- -- -- -- -- --
| 70: -- -- -- -- -- -- -- --
`-------
root@usbarmory:/home/usbarmory# ls -l /dev/i2c*

,-------
| crw-rw---- 1 root i2c 89, 0 Mar  7 17:32 /dev/i2c-0
`-------
root@usbarmory:/home/usbarmory# dmesg

,-------
| [    5.151631] i2c i2c-0: IMX I2C adapter registered
| [    5.155055] i2c i2c-0: can't use DMA, using PIO instead.
| ...
| [  269.543762] i2c /dev entries driver
`-------
root@usbarmory:/home/usbarmory# i2cdetect -l

,-------
| i2c-0	i2c       	63fc8000.i2c                    	I2C adapter
`-------

please help

Regards

andrejro, 2019-03-19:
Please try the updated release containing the fixed I2C dtb:
https://github.com/inversepath/usbarmory-debian-base_image/releases/tag/20190319

The I2C interface was not tested though, so let us now if the issue is solved.

Thanks!

Yalman, 2019-03-19:
nope it does not work

ls -l /boot/imx53-usbarmory.dtb
,-------
| lrwxrwxrwx 1 root root 34 Mar 19 20:57 /boot/imx53-usbarmory.dtb -> imx53-usbarmory-i2c-4.14.107-0.dtb
`-------
modprobe i2c-dev
ls -l /dev/i2c*
,-------
| ls: cannot access '/dev/i2c*': No such file or directory
`-------
dmesg | grep i2c
,-------
| [    3.634941] imx-i2c: probe of 63fc8000.i2c failed with error -22
| [   51.296261] i2c /dev entries driver
| [  173.087100] i2c /dev entries driver
`-------
cat /proc/interrupts
,-------
|            CPU0
|  17:       5009      tzic   1 Edge      mmc0
|  22:          0         tzic   6 Edge      sdma
|  34:       4223      tzic  18 Edge      53f80000.usb
|  55:      10124     tzic  39 Edge      i.MX Timer Tick
|  74:          0         tzic  58 Edge      53f98000.wdog
| Err:          0
`-------
tail /proc/device-tree/aliases/i2c*
,-------
| ==> /proc/device-tree/aliases/i2c0 <==
| /soc/aips@60000000/i2c@63fc8000
| ==> /proc/device-tree/aliases/i2c1 <==
| /soc/aips@60000000/i2c@63fc4000
| ==> /proc/device-tree/aliases/i2c2 <==
`-------

Yalman, 2019-04-02:
bump

andrejro, 2019-04-03:
Fixed and tested in the last release: 20190403.

Closed 2019-04-12.

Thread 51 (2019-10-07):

Wiki: Mk I / Host adapter: Fix link to example device tree source file (dts)

eduncan911, 2019-10-07:
On this wiki page:

https://github.com/inversepath/usbarmory/wiki/Host-adapter

There's a broken link for the example device tree source file (dts):

> The official USB armory repository provides an example here.

The correct link should be:

https://github.com/inversepath/usbarmory/blob/master/software/kernel_conf/mark-one/imx53-usbarmory-host.dts

andrejro, 2019-10-07:
Fixed. Thanks!

Closed 2019-10-07.

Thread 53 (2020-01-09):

Armory MK I not booting up after switching to g_multi

ioncodes, 2020-01-09:
I was trying to switch to g_multi mode, I did so by replacing g_ether with this line:

```
g_multi use_eem=0 dev_addr=1a:55:89:a2:69:41 host_addr=1a:55:89:a2:69:42 file=/dev/mmcblk0p2
```

I made sure the device actually exists, I formatted it as FAT32 beforehand as well. Any idea why this is not working? I can see the LED blinking but neither the network connection works nor is a mass storage device recognized.

On another note: How would I go about changing vendor ID and product ID? I read in the wiki that you can set idVendor and idProduct, but previous tests showed me that this didn't work. Additionally, is there a way to set the manufacturer name as well?

abarisani, 2020-01-10:
The LED blinking means that the USB armory is booting correctly, to change the vendorID and productID you need to use [configfs](https://www.kernel.org/doc/Documentation/usb/gadget_configfs.txt).

This is taken from an example to enable the second RNIDS (usb1) on the USB armory Mk II:

```
#!/bin/sh
cd /tmp
mkdir cfg
mount -t configfs none cfg
cd cfg
cd usb_gadget
mkdir g
cd g
echo 0x0525 > idVendor
echo 0xa4a2 > idProduct
echo 0x0419 > bcdDevice
echo 0x0200 > bcdUSB
echo 0x02 > bDeviceClass
mkdir -p strings/0x409
echo "Linux 4.19.50 with 2184200.usb" > strings/0x409/manufacturer
echo "RNDIS/Ethernet Gadget"          > strings/0x409/product
mkdir -p functions/rndis.usb1
mkdir -p configs/c.1
echo 250 > configs/c.1/MaxPower
ln -s functions/rndis.usb1 configs/c.1
echo ci_hdrc.1 > UDC
ip addr add 10.1.0.1/24 dev usb1
ip link set usb1 up
```

The `g_multi` driver is known to have issues with certain hosts, please [search the google group](https://groups.google.com/forum/#!searchin/usbarmory/g_multi%7Csort:date) for some related discussion.

As this is not a USB armory specific issue, but rather a generic Linux gadgetfs configuration question, I am closing this issue for now.

Thanks!

Yalman, 2021-11-24:
Hello,
excuse me for reopening the thread. However, I have a quick question.
is there a known solution in which g_multi works for the USBArmory MK1?
Regards

abarisani, 2021-11-24:
We don't have a recipe for the Mk I and `g_multi`, as mentioned in the previous comment this is not something specific to the armory but rather a generic Linux gadgetfs configuration question. I cannot provide more information than my earlier comment.

lizeren, 2024-10-20:
when I tried to assign the USB gadget to UDC I had the following issue:
usbarmory@usbarmory:/tmp/cfg/usb_gadget/g$ echo "ci_hdrc.1" | sudo tee UDC
UDC core: g: couldn't find an available UDC or it's busy
ci_hdrc.1
tee: UDC: Device or resource busy

Closed 2020-01-10.

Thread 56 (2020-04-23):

Add GlobaLeaks to the list of user contributed images

evilaliv3, 2020-04-23:
As [GlobaLeaks](https://github.com/globaleaks/GlobaLeaks) we just released a first image for the USBArmory MKII where we have packaged our latest software version (4.0.16) on top of the Debian Buster: [release 4.0.16-20200423](https://github.com/globaleaks/globaleaks-usbarmory-image/releases/tag/4.0.16-20200423)

The experimentation has been performed thanks to the support by @abarisani that offered us the possibility to test it on the MKII board.

We created a [fork repository](https://github.com/globaleaks/globaleaks-usbarmory-image) to keep track of any development and improvement, and as well implemented a release procedure in the same fashion your official Debian image release procedure.

We issued a first beta release that is actually fully functional making it possible to run Globaleaks exposing it publicly via a Tor Onion Service; the image is currently declared as beta for obvious security precaution.

This ticket is for asking for the possibility to add GlobaLeaks to the list of the user contributed images that we consider important for both the USBArmory and GlobaLeaks as users may learn how to package a software for the USBArmory  board with very minimal work and with a procedure well experimented. In fact we have been able to implement it all with very minimal changes documented in a very minimal self-contained commit: https://github.com/globaleaks/globaleaks-usbarmory-image/commit/48b9ead5eca72188d86adda5e719483a9ba045ff

We will further send you minimal patches that we suggest to apply to make this process even more straightforward.

Thank you!

abarisani, 2020-04-23:
This has been now added to the following pages:

* https://github.com/f-secure-foundry/usbarmory/wiki/Available-images

* https://github.com/f-secure-foundry/usbarmory/wiki/External-resources#projects

evilaliv3, 2020-04-24:
Thank you @abarisani ! We are really happy of this.

Closed 2020-04-23.

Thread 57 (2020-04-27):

Driver developer documentation

DemiMarie-parity, 2020-04-27:
Where can I find documentation for interacting with the hardware onboard the USB Armory Mark II?

abarisani, 2020-04-27:
I'd advise the following resources:

* SoC reference manual, linked early in [this page](https://github.com/f-secure-foundry/usbarmory/wiki/External-resources) (they unfortunately require registration)

* Our own [armoryctl tool](https://github.com/f-secure-foundry/armoryctl) provides interfacing with some of its peripherals, this might be a good start as well.

* Our Go bare metal framework [TamaGo](https://github.com/f-secure-foundry/tamago) includes several drivers written in a high level language and the source code base contains pointers to the relevant manuals and specifications. I think this is possibly the best resource.

If this helps please close the issue.

Cheers

DemiMarie-parity, 2020-04-28:
Are there peripheral description files that can be used?

abarisani, 2020-04-29:
There are some SVD files for i.MX6 series [published in this NXP thread](https://community.nxp.com/thread/306995), however they don't match our P/N (though some peripherals are identical).

Are you interested in a specific peripheral?

DemiMarie-parity, 2020-04-29:
I would up using different hardware for my project, but thanks!

Closed 2020-04-29.

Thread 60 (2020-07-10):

Can't boot from emmc

bazuchan, 2020-07-10:
Documentation doesn't cover how to boot from emmc. I tried to flash raw disk image to emmc, but it still boots from sdcard with both positions of the switch.

andrejro, 2020-07-10:
What image is flashed on eMMC?
Does it boot from eMMC when microSD is removed?

bazuchan, 2020-07-10:
What I did:
1. Flashed usbarmory-mark-two-debian_buster-base_image-20200505.raw to sdcard, resized partition, copied usbarmory-mark-two-debian_buster-base_image-20200505.raw to scard.
2. Boot from sdcard and run ```dd if=/usbarmory-mark-two-debian_buster-base_image-20200505.raw of=/dev/mmcblk1 bs=1M```
3. Shutdown. Remove sdcard. Replug usbarmory.

Now blue and white leds constantly on and usbarmory not detected on usb. If I put sdcard back, it will boot from sdcard.

andrejro, 2020-07-10:
In 3. you should also move the boot switch to eMMC boot mode.

bazuchan, 2020-07-10:
I have tried both positions of switch

andrejro, 2020-07-10:
The pre-build `usbarmory-mark-two-debian_buster-base_image-20200505.raw` is meant to be flashed on microSD only.
There are no pre-build images for eMMC. You can built an eMMC image by following the instruction on:
https://github.com/f-secure-foundry/usbarmory-debian-base_image#building

andrejro, 2020-07-10:
In the next release we will provide the binary version for both, microSD and eMMC.

bazuchan, 2020-07-12:
I have build image with ```make all V=mark-two IMX=imx6ulz BOOT=eMMC```. Flashed it. Still can't boot from emmc, but now it detected as empty freeascale device (SE Blank 6ULL) on usb.

bazuchan, 2020-07-13:
Had no luck with image that was build by usbarmory-debian-base_image. But finally was able to boot from emmc with following steps:
1. Flash usbarmory-mark-two-debian_buster-base_image-20200505.raw
2. Compile u-boot with flags to boot from emmc (just like in image makefile). Run ```dd if=u-boot-dtb.imx of=/dev/mmcblk1 bs=512 seek=2 conv=fsync conv=notrunc```
3. Run ```mmc bootpart enable 0 0 /dev/mmcblk1```.

andrejro, 2020-07-14:
Re-closing the issue as we have just confirmed that compiling the USB armory Debian image with
`make all V=mark-two IMX=imx6ulz BOOT=eMMC` and flashing to the eMMC with `sudo dd if=usbarmory-*-debian_buster-base_image-YYYYMMDD.raw of=/dev/mmcblk1 bs=1M conv=fsync` works as expected.

andrejro, 2020-07-15:
The following release contains the binary images for both, uSD and [eMMC.]
https://github.com/f-secure-foundry/usbarmory-debian-base_image/releases/tag/20200714

Closed 2020-07-14.

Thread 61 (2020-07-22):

[Suggestion]: Hardware Rev. Ɣ / Add NFC antenna

nekrondev, 2020-07-22:
The ANNA-B112 supports NFC tag TX which can be used as an additional outbound communication instead of BLE.
However there are no patch antennas for NFC found on the board so reading tags via NFC does not work currently.

Would it be possible to include a patch antenna in the next hardware revision?

abarisani, 2020-07-22:
Unfortunately we are not interested in allowing NFC use and it would be also difficult to find room for an antenna given the size of the board. Sorry.

Closed 2020-07-22.

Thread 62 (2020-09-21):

Flash bootable image to eMMC

huntergregal, 2020-09-21:
As the title suggests -

How do I flash a bootable image to the eMMC (no SDCARD). As far as I can tell the docs do not say how to flash the eMMC without first using an sdcard to boot and copy/ ssh into the device.

I'd assume it would be over the USB/Serial protocol like the imx images -- but the documentation does not address bootable images like the debian pre-built.

Perhaps I am just missing the instructions>

Thanks!

abarisani, 2020-09-21:
Please see [this page](https://github.com/f-secure-foundry/usbarmory/wiki/Boot-Modes-(Mk-II)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).

Specifically this section:

"The USB armory Mk II itself can be used as a microSD/eMMC reader using [armory-ums](https://github.com/f-secure-foundry/armory-ums)."

Some instructions in [this thread](https://groups.google.com/g/usbarmory/c/Wt_YXTQkI_Q/m/HGTsFPLZAwAJ).

huntergregal, 2020-09-21:
@abarisani  -- perfect. thanks for the prompt response. those instructions are exactly what i was looking for -- cheers

Closed 2020-09-21.

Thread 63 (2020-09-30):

OSX Cable Unplugged

vonProteus, 2020-09-30:
i have similar issue to #32
but with Mk II and debian image

1. i write debian image to my µSD
2. i put µSD in usbarmory (µSD boot mode)
3. i plug usbarmory to my mac (10.15.7)
4. i get new network adapter

```
RNDIS/Ethernet Gadget:

  Product ID:	0xa4a2
  Vendor ID:	0x0525  (PLX Technology, Inc.)
  Version:	5.04
  Speed:	Up to 480 Mb/s
  Manufacturer:	Linux 5.4.66-0 with 2184000.usb
  Location ID:	0x14700000 / 20
  Current Available (mA):	500
  Current Required (mA):	500
  Extra Operating Current (mA):	0
```

white light is flashing
but i dont get connected status

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

when i try it on ubuntu it works fine

maybe not so similar

andrejro, 2020-10-05:
Probably you have the Internet sharing enabled for the RNDIS interface.
Check: https://groups.google.com/g/usbarmory/c/zyRECP54-qQ/m/T_EyxaohCAAJ

abarisani, 2020-10-05:
Our instructions have been [updated accordingly](https://github.com/f-secure-foundry/usbarmory/wiki/Host-communication#setup--connection-sharing-macos). Please close the issue if this resolves the problem.

vonProteus, 2020-10-09:
thank you for your patience
i don't know what i did but it is working now
for sure i didn't have enabled internet sharing on mac

vonProteus, 2020-10-10:
my close was premature
i don't have enable internet sharing
and the problem is in system preferences i have status cable unplugged
```
$ ifconfig en5
en5: flags=8822<BROADCAST,SMART,SIMPLEX,MULTICAST> mtu 1500
        options=6407<RXCSUM,TXCSUM,VLAN_MTU,CHANNEL_IO,PARTIAL_CSUM,ZEROINVERT_CSUM>
        ether 1a:55:89:a2:69:42
        media: autoselect (none)
        status: inactive
```
regardless of whether I set ip address manually or via dhcp, the same effect

abarisani, 2020-10-12:
Assuming you have the vanilla Debian image configuration on the USB armory, can you try to manually set it up from the command line with something like:

```
sudo ifconfig set en5 down
sudo ipconfig set en5 MANUAL 10.0.0.2 255.255.255.0
sudo ifconfig set en5 up
```

And see if this allow you to SSH to 10.0.0.1 ?

vonProteus, 2020-10-13:
again i did nothing and it seems to work
and eilier i tried to set ip address in system preferences to 10.0.0.2/24 and it didn't help
i'm on mac to be cleare
this is how it looks when it is working
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

abarisani, 2020-10-13:
Please re-open if necessary, if it happens again please try to apply the instructions in my earlier message to see if it makes a difference (e.g. changing the IP address not from system preferences but from the command line).

Thanks

vonProteus, 2020-10-18:
ok so i connected USBArmory to my mac
```
$ ifconfig en5
en5: flags=8822<BROADCAST,SMART,SIMPLEX,MULTICAST> mtu 1500
	options=6407<RXCSUM,TXCSUM,VLAN_MTU,CHANNEL_IO,PARTIAL_CSUM,ZEROINVERT_CSUM>
	ether 1a:55:89:a2:69:42
	media: autoselect (none)
	status: inactive
```

then i did
```
$ sudo ifconfig en5 down
$ sudo ipconfig set en5 MANUAL 10.0.0.2 255.255.255.0
$ sudo ifconfig en5 up
```

and get
```
$ ifconfig en5
en5: flags=8863<UP,BROADCAST,SMART,RUNNING,SIMPLEX,MULTICAST> mtu 1500
	options=6407<RXCSUM,TXCSUM,VLAN_MTU,CHANNEL_IO,PARTIAL_CSUM,ZEROINVERT_CSUM>
	ether 1a:55:89:a2:69:42
	inet6 fe80::4e3:54a1:1a7:889d%en5 prefixlen 64 secured scopeid 0x12
	nd6 options=201<PERFORMNUD,DAD>
	media: autoselect (100baseTX <full-duplex>)
	status: active
```

and in system preferences status is not connected

abarisani, 2020-10-18:
@andrejro can you check if my IP address setting command is correct? It seems that the interface is up just fine but the address was not assigned.

When configuring the interface manually it's expected for system preferences status not to be in sync. What I am trying to understand is if manual configuration works in your case.

In the past I noted some odd quirks with macOS in relation to interface caching, you might also want to try changing the USB armory MAC address as that might give you a fresh start on the macOS side.

You can do so by replacing values in `/etc/modprobe.d/usbarmory.conf` on the USB armory installation, for instance try changing both `1a:55` with `1b:55` and see what happens. That might just solve some invalid state that got triggered on your macOS.

We are able to always successfully connect on macOS and, given that with a Linux host it works fine for you, I'd exclude any hardware issue.

abarisani, 2020-10-21:
In case it helps, here's a corrected version of my earlier command:

```
sudo ifconfig en5 down
sudo ifconfig en5 10.0.0.2 netmask 255.255.255.0
sudo ifconfig en5 up
```

Closed 2020-10-13.

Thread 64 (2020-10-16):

Secure Boot (HAB) vulnerability seemingly never fixed

willbicks, 2020-10-16:
In reviewing the details of the USB Armory I discovered the previously disclosed vulnerability in NXP's implementation of their secure boot system called HAB, which was [announced by them in 2017.](https://community.nxp.com/t5/i-MX-Processors-Knowledge-Base/i-MX-Vybrid-Security-Vulnerability-Errata-ERR010872-ERR010873/ta-p/1120527) In summary, even when secure boot was enabled, it is possible to load untrusted code, which for those hoping to make use of the secure boot functionality essentially renders it completely ineffective.

F-Secure detailed this issue and how it applies to USB Armory devices in [this advisory,](https://github.com/f-secure-foundry/usbarmory/blob/master/software/secure_boot/Security_Advisory-Ref_QBVR2017-0001.txt) which states:

> However the USB armory Mk II is produced with i.MX6UL parts with Silicon Revision 1.2 or greater, implemented on Part Numbers (P/N) with revision "AB" or greater, which address both issues.

The issue I see is that the materials on NXP's website seem to suggest the i.MX6UL parts used in the Mark II have not been patched for this vulnerability, and none of the changes that occurred with silicon revision 1.2 affected such functionality.

[The most recent chip errata published by NXP](https://www.nxp.com/docs/en/errata/IMX6ULCE.pdf) outlines all the revisions that have been made to the i.MX6UL, including the fixes that were made in revision 1.1 and revision 1.2. However, none of them address the security issues with HAB or Secure Boot, which are tracked as [ERR010872 and ERR010873](https://community.nxp.com/t5/i-MX-Processors-Knowledge-Base/i-MX-Vybrid-Security-Vulnerability-Errata-ERR010872-ERR010873/ta-p/1120527)

It's entirely possible I'm missing something, but it seems as if according to NXP the MKII is still vulnerable to the above mentioned attacks, and F-Secure's documentation should likely be updated according.

mark-stopka, 2020-10-17:
Interesting, I kind a hope that f-secure is right, anyway, can't wait for some more performant open-source RISC-V chips that could help us mitigate these risks in the future...

andrejro, 2020-10-17:
The information you are missing were specified in [AN4581](https://www.nxp.com/docs/en/application-note/AN4581.pdf) under Appendix A "HAB Versions and differences". Unfortunately, this section was redacted in revision 4, as you can see from the Revision history section.

The revision 2 of such document can be found [here](https://pdfslide.net/documents/secure-boot-on-imx-50-imx-53-imx-6-and-imx-7-trusted-and-authentic-code-srk.html). Check the table and the second note in Appendix A.

Thank you for spotting out that the official NXP documentation does not contain such information anymore.

abarisani, 2020-10-17:
I can also confirm that the P/N we are using underwent internal as well as third party auditing (which F-Secure commissioned) to ensure that the errata have been addressed successfully as well as understanding if more issues were present.

This review is what lead to CVE-2018-18439 and CVE-2018-18439 in the first place, and the reason we now don't rely on U-Boot, but rather [armory-boot](https://github.com/f-secure-foundry/armory-boot) to maintain the chain of trust.

A while ago we complained with NXP about not giving enough exposure on ERR010872 and ERR010873 which as of today still do not appear in the affected P/Ns relevant errata documents.

It's disappointing to see that not only things are not improving, but worsening. But rest assured that we have been on top of this.

Thanks!

willbicks, 2020-10-17:
I'm very glad to be wrong! Thanks for your thoughtful response.
I too am frustrated by NXPs redaction of their fixes, but greatly appreciate the effort you put into ensuring things are secure!

Closed 2020-10-17.

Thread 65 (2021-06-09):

Best practices for secure boot key generation?

t-anon, 2021-06-09:
In the instructions for enabling Secure Boot, the wiki [says](https://github.com/f-secure-foundry/usbarmory/wiki/Secure-boot-(Mk-II)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):

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

and proceeds to detail how to create these six public/private key pairs.

I understand that anchoring trust is a difficult problem that permeates every aspect of the cybersecurity universe, but I was wondering if you had any thoughts on best practices.

In the past, when I've had to generate such key pairs I've had my YubiKey generate them, but in this case, the private key itself must be exported for use with `habtool`, so that doesn't seem to be an option, as YubiKeys prohibit such exports.  Is integration with YubiKeys even possible here? I've been looking at:
- https://developers.yubico.com/yubico-piv-tool/Actions/key_generation.html
- https://developers.yubico.com/yubico-piv-tool/Actions/signing.html

It seems like using a YubiKey to generate those six key pairs would be possible, but changes to `habtool` would be in order?

I must admit I've had thoughts revolving around using a [Precursor](https://www.crowdsupply.com/sutajio-kosagi/precursor) to create these keys and anchor trust. But, using a $600 unreleased device is not accessible to most people.

TL;DR: What are some hardware/software stacks recommended to create a secure environment to securely create these six key pairs and sign bootloader images?

abarisani, 2021-06-09:
The USB armory could potentially be used (with an extension to [GoKey](https://github.com/f-secure-foundry/GoKey)) for this purpose, however this would be a classic "chicken and the egg" problem as that units itself would require to be secure booted.

Additionally it is important to differentiate the technologies and make USB armory secure boot key management not depending on its same tech, therefore I think this would be a useful feature.

I think it might be possible and definitely worth exploring, we have some Yubikeys around so I will do some testing and see if I can patch habtool and its libraries accordingly.

abarisani, 2024-02-23:
As an update to this Google Cloud support for CloudHSM storage is now available in our signing tool: https://github.com/usbarmory/crucible?tab=readme-ov-file#google-cloud-support

abarisani, 2024-11-08:
This blog post covers [i.MX Code Signing using a YubiHSM](https://www.thegoodpenguin.co.uk/blog/i-mx-code-signing-using-a-yubihsm-2-hardware-token-from-yubico/).

And [GoKey](https://github.com/usbarmory/GoKey) now supports [PKCS#11 interface for signing](https://github.com/usbarmory/GoKey?tab=readme-ov-file#pkcs11-token).

I think the combination of all such options can provide ways to implement hardware backed practices for secure boot key generation and signing.

Closed 2024-11-08.

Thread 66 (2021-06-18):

Wireguard on USB Armory with Tamago unikernel?

t-anon, 2021-06-18:
Is it possible to run wireguard-go on the USB Armory on the Tamago unikernel? Or, would it be possible, with some minor changes to the Wireguard project? I think this might be promising for usage as a particularly secure VPN.

abarisani, 2021-06-21:
Because of [this](https://twitter.com/hugelgupf/status/1349837585342894081?s=20) I think it might be possible.

It would basically be an effort to bridge our [network driver](https://github.com/f-secure-foundry/imx-usbnet) (which uses gVisor) with it.

We have no current plans of doing this but I think it could be feasible.

Please note that [imx-usbnet](https://github.com/f-secure-foundry/imx-usbnet) is currently only supported on Linux hosts, so that is a limitation.

Cheers

Closed 2021-06-21.

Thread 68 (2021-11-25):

Power headers silkscreen is inverted

gsora, 2021-11-25:
While poking at the power headers on the debug accessory, I noticed that while the silkscreen labels 3.3V and 5V, the resulting voltages are inverted.

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

This is also reflected on the PCB schema:

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

abarisani, 2021-11-26:
Thanks for spotting this.

I added an errata [here](https://github.com/f-secure-foundry/usbarmory/wiki/Errata-(Mk-II)#errata-incorrect-silkscreen-labels) as well as [here](https://github.com/f-secure-foundry/usbarmory/tree/master/hardware/mark-two-debug-accessory#errata).

I've also bumped the PCB version to 1.1 with the silkscreen fix in [this commit](https://github.com/f-secure-foundry/usbarmory/commit/6653674982c8120f59a49e8f7c9ea5695207171a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).

We've also warned the current adapter manufacturer to pick up the new PCB revision for next production batches.

Closed 2021-11-26.

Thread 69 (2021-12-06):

Can not boot from SD Card (Mk II)

xjaztek, 2021-12-06:
We can not get the MKII to boot from the SD card. Have installed Kali on the SD have Debian on the eMMC and can finally get it to boot into the eMMc. But even switching the manual switch to primary boot to the SD card it does nothing for the boot sequence and will not boot. How an we get it to boot to the SD?

abarisani, 2021-12-07:
Unfortunately we don't provide support for Kali, you would have to ask to their support resources.

We can only support our Debian image [release](https://github.com/f-secure-foundry/usbarmory-debian-base_image/releases/tag/20211129), so I can suggest to try that on an SD card. When doing so please keep a note of the `dd` command you will use so that, in case it doesn't boot, we can debug what went wrong.

xjaztek, 2021-12-07:
We don't think it is a distro issue , we literally can not get it to attempt boot from the SD card. If the switch is turned to SD primary boot. What issues are there that might prevent the SD reader to fail? Are there limit sizes on the SD card size?

The SD card loaded with Kali will boot from a regular USB card reader on F12 boot on a laptop or desktop using the USB/SD card boot. What could be causing conflict from booting from the SD on the Mrk I?

abarisani, 2021-12-07:
A Kali image booted from a regular USB card reader on a laptop is an entirely different OS from the one supported on the USB armory given that they are completely separate architecture.

Without knowing the exact image and procedure used to image the SD card we cannot rule out errors in the image itself or imaging procedure.

Please follow the instructions to flash our Debian image release on an SD card and try that so that we can rule out hardware issues.

You  mention Mk II in the first comment but "Mrk I" in the second one, please also confirm which version we are talking about.

Thanks.

xjaztek, 2021-12-07:
I am talking about the Mrk II. I corrected the typo. We will see if we can load the Debian image and try and get it ti boot! Thanks!

abarisani, 2021-12-14:
Closing for now, re-open if necessary.

Closed 2021-12-14.

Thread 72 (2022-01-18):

External I2C slaves over debug accessory

gsora, 2022-01-18:
Hi,
I'm trying to gain access to external I2C slaves over the debug accessory on a Armory Mk.II device, with Tamago - in particular, I'm interested in using `I2C2`.

Following [docs](https://github.com/f-secure-foundry/usbarmory/tree/master/hardware/mark-two-debug-accessory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) on the debug accessory page, `I2C2` is accessible over A10 and B2.

I wrote the following function to configure the IOMUX according to the i.MX6UL reference manual:

```go
const (
	MUX_I2C2_SCL = 0x020e00BC
	PAD_I2C2_SCL = 0x020e0348

	MUX_I2C2_SDA = 0x020E00C0
	PAD_I2C2_SDA = 0x020E034C
)

func setupI2C() *imx6.I2C {
	p, err := imx6.NewPad(MUX_I2C2_SCL, PAD_I2C2_SCL, 0)
	if err != nil {
		panic(err)
	}

	p.Mode(2)
	p.SoftwareInput(true)
	p.Ctl(0x4001b8b0)

	p, err = imx6.NewPad(MUX_I2C2_SDA, PAD_I2C2_SDA, 0)
	if err != nil {
		panic(err)
	}

	p.Mode(2)
	p.Ctl(0x4001b8b0)
	p.SoftwareInput(true)

	imx6.I2C2.Init()

	return imx6.I2C2
}
```

The CTL value has been taken from the Armory Mk.II Linux [device tree](https://github.com/f-secure-foundry/usbarmory/blob/master/software/kernel_conf/mark-two/imx6ulz-usbarmory.dts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).

`p.SoftwareInput` is because the reference manual says (page 832):

```
Inputs of I2Cn_SCL and I2Cn_SDA also need to be manually enabled by setting the
SION bit in the IOMUX after the corresponding PADs are selected as I2C function.
```

No `panic()` or fatal error encountered up until this point.

When I try to read/write to a device address, the following errors pop up:

```
read: [] timeout waiting bus to be busy
write: timeout waiting bus to be busy
```

Am I configuring/using the IOMUX pads/control correctly?

gsora, 2022-01-20:
Update!
Apparently I completely forgot about daisy registers.

The following function setups I2C2 work through the debug accessory.

```go
func setupI2C() *imx6.I2C {
	p, err := imx6.NewPad(MUX_I2C2_SCL, PAD_I2C2_SCL, 0x020E05AC)
	if err != nil {
		panic(err)
	}

	p.Mode(2)
	p.Select(0b10)
	p.Ctl(0x4001b8b0)
	p.SoftwareInput(true)
	p, err = imx6.NewPad(MUX_I2C2_SDA, PAD_I2C2_SDA, 0x020E05B0)
	if err != nil {
		panic(err)
	}

	p.Mode(2)
	p.Select(0b10)
	p.Ctl(0x4001b8b0)
	p.SoftwareInput(true)

	imx6.I2C2.Init()
	return imx6.I2C2
}
```

Closed 2022-01-20.

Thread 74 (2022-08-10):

No boot from SD card with Debian image

abra-mixabra, 2022-08-10:
I'm experiencing problems with booting my Armory from SD card.
I've build a Debian image using the instructions from https://github.com/usbarmory/usbarmory-debian-base_image repo.
This image has booted sucessfully several times but after that things started going south.

Using my debug accessory I've tried to get boot logs from armory.
50% of the time I get radio silence. Both blue and white leds a dimly lighted but nothing outputs in debug terminal.
50% of the time I get an initial message from booting process after which it's stuck and never continued:
``` 0
switch to partitions #0, OK
mmc0 is current device
Scanning mmc 0:1...
No EFI system partition
BootOrder not defined
EFI boot manager: Cannot load any image
7591600 bytes read in 335 ms (21.6 MiB/s)
21290 bytes read in 10 ms (2 MiB/s)
Kernel image @ 0x80800000 [ 0x000000 - 0x73d6b0 ]
## Flattened Device Tree blob at 82000000
   Booting using the fdt blob at 0x82000000
   Loading Device Tree to 9f578000, end 9f580329 ... OK

Starting kernel ...
```
Rarely (once in 20-25 tries) it successfully boots (the white led starts blinking) for a minute or so, after which the led turns off and the armory freezes.

I've also tried booting from eMMC with similar result: after several successful boots the Armory stopped working.
I've tried dd-ing the eMMC memory with zeroes after that (using armory-boot application to expose the eMMC memory to my computer) and most of the time the dd exited before reaching 16 GB limit.

Is this a bad flash memory problem?
Is this a power problem (I'm using a standard USB 3.0 port)?

Is there any way to fix this?

abra-mixabra, 2022-08-11:
Managed to get a kernel panic log from one of the boots.
This one was booted from eMMC with the same Debian sid image as before.
```
8<--- cut here ---
Unable to handle kernel paging request at virtual address 5fb74aa4
pgd = 4a7d4364
[5fb74aa4] *pgd=00000000
Internal error: Oops: 5 [#1] PREEMPT ARM
Modules linked in: nvmem_imx_ocotp mxs_dcp(O) i2c_imx imx_sdma firmware_class virt_dma leds_gpio led_class imx6q_cpufreq i2c_dev i2c_core usb_f_ecm g_ether usb_f_rndis u_ether libcomposite ci_hdrc_imx usbmisc_imx ci_hdrc ulpi ro
les udc_core ehci_hcd usbcore usb_common ledtrig_heartbeat fuse ip_tables x_tables ipv6
CPU: 0 PID: 0 Comm: swapper Tainted: G           O      5.15.59-0 #1
Hardware name: Freescale i.MX6 Ultralite (Device Tree)
PC is at __queue_work+0x13c/0x490
LR is at 0xc1800ab0
pc : [<c013c648>]    lr : [<c1800ab0>]    psr: 600001d3
sp : c0d01d38  ip : 00000000  fp : 200001d3
r10: 00000020  r9 : 00000000  r8 : ffe42240
r7 : c3c91434  r6 : c0d00000  r5 : dfbe4200  r4 : c3c91430
r3 : c3c91434  r2 : 5fb74a90  r1 : 00000000  r0 : c0d0bfe8
Flags: nZCv  IRQs off  FIQs off  Mode SVC_32  ISA ARM  Segment none
Control: 10c53c7d  Table: 83cec059  DAC: 00000051
Register r0 information: non-slab/vmalloc memory
Register r1 information: NULL pointer
Register r2 information: non-paged memory
Register r3 information: slab kmalloc-128 start c3c91400 pointer offset 52 size 128
Register r4 information: slab kmalloc-128 start c3c91400 pointer offset 48 size 128
Register r5 information: non-slab/vmalloc memory
Register r6 information: non-slab/vmalloc memory
Register r7 information: slab kmalloc-128 start c3c91400 pointer offset 52 size 128
Register r8 information: non-paged memory
Register r9 information: NULL pointer
Register r10 information: non-paged memory
Register r11 information: non-paged memory
Register r12 information: NULL pointer
Process swapper (pid: 0, stack limit = 0x2ce3f952)
Stack: (0xc0d01d38 to 0xc0d02000)
1d20:                                                       c22c8000 c054979c
1d40: a00001d3 00000001 00000022 c0d01ee0 c0d1b594 c7dc9fdf 00000016 c013c9d8
1d60: c3c91424 00000023 00000022 c01bbb14 00000000 c0d1a3e0 c7dcca31 c01bbb84
1d80: 00000000 c01bbbd4 00000000 c017c19c c0d1bec0 00000016 c7dcca31 c018d124
1da0: c0d00000 c013ca78 ffffe000 c0d1bec0 c0d1b580 c0d1b540 c0d00000 c0d1b594
1dc0: c7dc9fdf c017c5e0 c0d1a400 c0d1b540 00000002 c0d1b540 c7dc9fdf 00000016
1de0: c0d1a414 c0d1b540 c0d00000 200001d3 00000003 c7dc9fdf 200001d3 c0d1b690
1e00: c0d1b670 c017d738 c1089e00 00000000 c7dc9fdf 00000016 ffffe000 ab9a2580
1e20: 0002625a c100ab40 c0d09688 00000000 c0d01e88 00000011 c100ad00 c0d36f54
1e40: c0b28c40 c0573214 c1023980 c01612a4 40000001 c0101330 600001d3 c0b28c68
1e60: 00989680 c100ad00 c0d09688 00000057 00000000 c0d25704 c0d00000 00000001
1e80: 00000016 c016147c 00000000 ab9a2580 00000016 c100ad00 c0d09688 c01656f8
1ea0: c0d25638 00000000 00000057 c0160c30 c0d03604 c0d01ee0 e0812000 e081200c
1ec0: c0d25704 c046de94 c054a260 20000153 ffffffff c0d01f14 c0d2f768 c0100b7c
1ee0: 00000000 00000016 d5debd3e 00000022 c7ac4377 c0d092a8 00000002 00000002
1f00: c0d2f768 00000016 00000001 00000016 003e4c2a c0d01f30 c054a254 c054a260
1f20: 20000153 ffffffff 00000051 c054a228 00001ca9 c840100d c0d092a8 c0d2f768
1f40: c0d092a8 00000002 c0d032b0 c7b7ec00 00000016 10c53c7d 00000000 c054a4a0
1f60: c0d2f768 c0d00000 c0d092a8 00000002 00000000 c014ed78 00beddc0 ab9a2580
1f80: 00000000 c0d44040 00000037 c0d03240 dfbeddc0 ffffffff 00000000 c014f164
1fa0: c0d44040 c0c010d8 ffffffff ffffffff 00000000 c0c0070c 00000000 00000000
1fc0: 00000000 c0c2da54 ab9f2abb 00000000 00000000 c0c004b0 00000051 10c03c7d
1fe0: 00000000 9f578000 410fc075 10c53c7d 00000000 00000000 00000000 00000000
[<c013c648>] (__queue_work) from [<c013c9d8>] (queue_work_on+0x3c/0x48)
[<c013c9d8>] (queue_work_on) from [<c01bbb14>] (irq_work_single+0x1c/0x44)
[<c01bbb14>] (irq_work_single) from [<c01bbb84>] (irq_work_run_list+0x48/0x58)
[<c01bbb84>] (irq_work_run_list) from [<c01bbbd4>] (irq_work_tick+0x20/0x3c)
[<c01bbbd4>] (irq_work_tick) from [<c017c19c>] (update_process_times+0xb8/0xc4)
[<c017c19c>] (update_process_times) from [<c018d124>] (tick_sched_timer+0x6c/0x120)
[<c018d124>] (tick_sched_timer) from [<c017c5e0>] (__hrtimer_run_queues.constprop.0+0xa4/0x224)
[<c017c5e0>] (__hrtimer_run_queues.constprop.0) from [<c017d738>] (hrtimer_interrupt+0x114/0x2fc)
[<c017d738>] (hrtimer_interrupt) from [<c0573214>] (mxc_timer_interrupt+0x34/0x3c)
[<c0573214>] (mxc_timer_interrupt) from [<c01612a4>] (__handle_irq_event_percpu+0x50/0x13c)
[<c01612a4>] (__handle_irq_event_percpu) from [<c016147c>] (handle_irq_event+0x6c/0xfc)
[<c016147c>] (handle_irq_event) from [<c01656f8>] (handle_fasteoi_irq+0x9c/0x210)
[<c01656f8>] (handle_fasteoi_irq) from [<c0160c30>] (handle_domain_irq+0x54/0x6c)
[<c0160c30>] (handle_domain_irq) from [<c046de94>] (gic_handle_irq+0x60/0x74)
[<c046de94>] (gic_handle_irq) from [<c0100b7c>] (__irq_svc+0x5c/0x90)
Exception stack(0xc0d01ee0 to 0xc0d01f28)
1ee0: 00000000 00000016 d5debd3e 00000022 c7ac4377 c0d092a8 00000002 00000002
1f00: c0d2f768 00000016 00000001 00000016 003e4c2a c0d01f30 c054a254 c054a260
1f20: 20000153 ffffffff
[<c0100b7c>] (__irq_svc) from [<c054a260>] (cpuidle_enter_state+0x178/0x374)
[<c054a260>] (cpuidle_enter_state) from [<c054a4a0>] (cpuidle_enter+0x30/0x40)
[<c054a4a0>] (cpuidle_enter) from [<c014ed78>] (do_idle+0x1a4/0x240)
[<c014ed78>] (do_idle) from [<c014f164>] (cpu_startup_entry+0xc/0x10)
[<c014f164>] (cpu_startup_entry) from [<c0c010d8>] (start_kernel+0x5d0/0x614)
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
abra-mixabra, 2022-08-11:
Also I've noticed a strange behaviour when I try to mount eMMC memory.
I connect Armory to a computer with the switch in the uSD position and launch `./armory-boot-usb -i 20201102_armory-ums.imx`.
The two leds are still dim insteam of the blue getting bright. But I still get the normal output:
```
found device 15a2:0080 Freescale SemiConductor Inc  SE Blank 6ULL
parsing 20201102_armory-ums.imx
loading DCD at 0x00910000 (952 bytes)
loading imx to 0x8000f400 (1547264 bytes)
jumping to 0x8000f400
serial download complete
```

The needed partition isn't shown and mounted but the raw device is, so I have to mount it using `mount -o loop,offset=5242880 -t ext4 /dev/sdb /mnt/` command.

After that I can access the internal flash memory as usual, but it's stil not the intended way, is it?

abra-mixabra, 2022-08-15:
I think my device is faulty or I've broken it somehow with several reimaging attemps.
No successfull boots for several last days. The only thing I can do is mount eMMC as described in my previous comment.

Is there anything can be done here to restore the functionality?

andrejro, 2022-08-16:
The described behavior is quite strange. Can you please retry using the pre-build Debian image: https://github.com/usbarmory/usbarmory-debian-base_image/releases/tag/20220706

abra-mixabra, 2022-08-16:
Here's the recording of my attempts:
```
$ ls -1
usbarmory-mark-two-emmc-debian_bullseye-base_image-20220706.raw.xz
usbarmory-mark-two-emmc-debian_bullseye-base_image-20220706.raw.xz.sha256
usbarmory-mark-two-usd-debian_bullseye-base_image-20220706.raw.xz
usbarmory-mark-two-usd-debian_bullseye-base_image-20220706.raw.xz.sha256
$ sha256sum -c usbarmory-mark-two-emmc-debian_bullseye-base_image-20220706.raw.xz.sha256
usbarmory-mark-two-emmc-debian_bullseye-base_image-20220706.raw.xz: OK
$ sha256sum -c usbarmory-mark-two-usd-debian_bullseye-base_image-20220706.raw.xz.sha256
usbarmory-mark-two-usd-debian_bullseye-base_image-20220706.raw.xz: OK
$ lsblk
NAME                    MAJ:MIN RM    SIZE RO TYPE  MOUNTPOINTS
mmcblk0                 179:0    0    3.7G  0 disk
└─mmcblk0p1             179:1    0    3.4G  0 part
$ xzcat usbarmory-mark-two-usd-debian_bullseye-base_image-20220706.raw.xz | dd of=/dev/mmcblk0 conv=fsync conv=notrunc bs=1M status=progress
3667689472 bytes (3.7 GB, 3.4 GiB) copied, 168 s, 21.8 MB/s
0+370548 records in
0+370548 records out
3670016000 bytes (3.7 GB, 3.4 GiB) copied, 336.181 s, 10.9 MB/s

Armory switch to uSD
boot 1 w/o debug: two dim leds, nothing in dmesg
$ picocom -b 115200 -eb /dev/ttyUSB2 --imap lfcrlf
boot 2   w debug: two dim leds, nothing in dmesg, nothing in terminal
boot 3   w debug: two dim leds, nothing in dmesg, nothing in terminal
...
boot 5   w debug: two dim leds, nothing in dmesg, terminal output:    # boot failed?
 0
0�X��qX��qX�= 0xf8d94602
sp start    = 0x9f587560
Early malloc usage: 508 / 2000
...
boot 12 (debug insert first, usb insert 2nd):                         # boot started, then froze
 0
switch to partitions #0, OK
mmc0 is current device
Scanning mmc 0:1...
libfdt fdt_check_header(): FDT_ERR_BADMAGIC
Scanning disk usdhc@2190000.blk...
Scanning disk usdhc@2194000.blk...
Found 3 disks
No EFI system partition
BootOrder not defined
EFI boot manager: Cannot load any image
7603096 bytes read in 335 ms (21.6 MiB/s)
21290 bytes read in 10 ms (2 MiB/s)
Kernel image @ 0x80800000 [ 0x000000 - 0x740398 ]
## Flattened Device Tree blob at 82000000
   Booting using the fdt blob at 0x82000000
   Loading Device Tree to 9f57a000, end 9f582329 ... OK

Starting kernel ...
...

$ cd ../armory-boot/
$ ./armory-boot-usb -i 20201102_armory-ums.imx
found device 15a2:0080 Freescale SemiConductor Inc  SE Blank 6ULL
parsing 20201102_armory-ums.imx
loading DCD at 0x00910000 (952 bytes)
loading imx to 0x8000f400 (1547264 bytes)
jumping to 0x8000f400
serial download complete
$ ls -la /dev/sdb
-rw-r--r-- 1 root root 5.0M Aug 12 02:31 /dev/sdb                     # strange size!
$ xzcat usbarmory-mark-two-emmc-debian_bullseye-base_image-20220706.raw.xz | dd of=/dev/sdb conv=fsync conv=notrunc bs=1M status=progress
3606355968 bytes (3.6 GB, 3.4 GiB) copied, 18 s, 200 MB/s
0+446851 records in
0+446851 records out
3670016000 bytes (3.7 GB, 3.4 GiB) copied, 18.949 s, 194 MB/s

Armory switch to eMMC, uSD ejected
boot 1 w/o debug: two dim leds, nothing in dmesg
$ picocom -b 115200 -eb /dev/ttyUSB2 --imap lfcrlf
boot 2   w debug: two dim leds, nothing in dmesg, nothing in terminal
...
boot 20  w debug: two dim leds, nothing in dmesg, nothing in terminal
```

No successfull boots occured.

andrejro, 2022-08-18:
It looks like a hardware issue. Please contact us at usbarmory@withsecure.com.

Closed 2022-08-18.

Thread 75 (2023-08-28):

u-boot: Please update the board to use CONFIG_DM_I2C/CONFIG_DM_SERIAL before the v2022.04/v2023.04 release

iam-TJ, 2023-08-28:
Whilst building I see these messages and having reviewed `u-boot/doc/develop/driver-model/migration.rst` it seems like there has been a long lead-in to these changes. Is there a plan to modify to suit the Driver Model ?
```
===================== WARNING ======================
This board does not use CONFIG_DM_I2C (Driver Model
for I2C drivers). Please update the board to use
CONFIG_DM_I2C before the v2022.04 release. Failure to
update by the deadline may result in board removal.
See doc/develop/driver-model/migration.rst for more info.
====================================================
===================== WARNING ======================
This board does not use CONFIG_DM_SERIAL (Driver Model
for Serial drivers). Please update the board to use
CONFIG_DM_SERIAL before the v2023.04 release. Failure to
update by the deadline may result in board removal.
See doc/develop/driver-model/migration.rst for more info.
====================================================
  OFCHK   .config
  ```

abarisani, 2023-08-28:
Thanks, we'll take a look.

andrejro, 2023-09-21:
The patch has been sent upstream:
https://lists.denx.de/pipermail/u-boot/2023-September/531144.html

Closed 2023-09-21.

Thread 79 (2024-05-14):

Cannot connect to the host (macOS) internet through MkII

hoonsubin, 2024-05-14:
I'm using Kali Linux image for the MkII and macOS as the host.
I followed the instructions on the wiki, but I could not connect the MkII to the Internet through the Mac's Internet sharing feature.

Here is my config:

```
source-directory /etc/network/interfaces.d

auto lo
  iface lo inet loopback

auto usb0
iface usb0 inet static
  address 192.168.2.2
  netmask 255.255.255.0
  gateway 192.168.2.1
```

Output for `status networking.service`:
```
× networking.service - Raise network interfaces
     Loaded: loaded (/usr/lib/systemd/system/networking.service; enabled; preset: enabled)
     Active: failed (Result: exit-code) since Mon 2024-01-29 11:54:05 UTC; 21s ago
       Docs: man:interfaces(5)
    Process: 898 ExecStart=/sbin/ifup -a --read-environment (code=exited, status=1/FAILURE)
    Process: 983 ExecStopPost=/usr/bin/touch /run/network/restart-hotplug (code=exited, status=0/SUCCESS)
   Main PID: 898 (code=exited, status=1/FAILURE)
        CPU: 603ms

Jan 29 11:54:05 kali-usb-armory-mkii dhclient[933]: before submitting a bug.  These pages explain the proper
Jan 29 11:54:05 kali-usb-armory-mkii dhclient[933]: process and the information we find helpful for debugging.
Jan 29 11:54:05 kali-usb-armory-mkii dhclient[933]:
Jan 29 11:54:05 kali-usb-armory-mkii dhclient[933]: exiting.
Jan 29 11:54:05 kali-usb-armory-mkii ifup[898]: ifup: failed to bring up eth0
Jan 29 11:54:05 kali-usb-armory-mkii ifup[955]: RTNETLINK answers: File exists
Jan 29 11:54:05 kali-usb-armory-mkii ifup[898]: ifup: failed to bring up usb0
Jan 29 11:54:05 kali-usb-armory-mkii systemd[1]: networking.service: Main process exited, code=exited, status=1/FAILURE
Jan 29 11:54:05 kali-usb-armory-mkii systemd[1]: networking.service: Failed with result 'exit-code'.
Jan 29 11:54:05 kali-usb-armory-mkii systemd[1]: Failed to start networking.service - Raise network interfaces.
```
Output for `journalctl -xeu networking.service`:
```
░░ The job identifier is 1481.
Jan 29 11:55:04 kali-usb-armory-mkii dhclient[1052]: Internet Systems Consortium DHCP Client 4.4.3-P1
Jan 29 11:55:04 kali-usb-armory-mkii ifup[1052]: Internet Systems Consortium DHCP Client 4.4.3-P1
Jan 29 11:55:04 kali-usb-armory-mkii ifup[1052]: Copyright 2004-2022 Internet Systems Consortium.
Jan 29 11:55:04 kali-usb-armory-mkii ifup[1052]: All rights reserved.
Jan 29 11:55:04 kali-usb-armory-mkii ifup[1052]: For info, please visit https://www.isc.org/software/dhcp/
Jan 29 11:55:04 kali-usb-armory-mkii dhclient[1052]: Copyright 2004-2022 Internet Systems Consortium.
Jan 29 11:55:04 kali-usb-armory-mkii dhclient[1052]: All rights reserved.
Jan 29 11:55:04 kali-usb-armory-mkii dhclient[1052]: For info, please visit https://www.isc.org/software/dhcp/
Jan 29 11:55:04 kali-usb-armory-mkii dhclient[1052]:
Jan 29 11:55:04 kali-usb-armory-mkii ifup[1055]: Cannot find device "eth0"
Jan 29 11:55:04 kali-usb-armory-mkii dhclient[1052]: Failed to get interface index: No such device
Jan 29 11:55:04 kali-usb-armory-mkii ifup[1052]: Failed to get interface index: No such device
Jan 29 11:55:04 kali-usb-armory-mkii ifup[1052]: If you think you have received this message due to a bug rather
Jan 29 11:55:04 kali-usb-armory-mkii ifup[1052]: than a configuration issue please read the section on submitting
Jan 29 11:55:04 kali-usb-armory-mkii ifup[1052]: bugs on either our web page at www.isc.org or in the README file
Jan 29 11:55:04 kali-usb-armory-mkii ifup[1052]: before submitting a bug.  These pages explain the proper
Jan 29 11:55:04 kali-usb-armory-mkii ifup[1052]: process and the information we find helpful for debugging.
Jan 29 11:55:04 kali-usb-armory-mkii ifup[1052]: exiting.
Jan 29 11:55:04 kali-usb-armory-mkii dhclient[1052]:
Jan 29 11:55:04 kali-usb-armory-mkii dhclient[1052]: If you think you have received this message due to a bug rather
Jan 29 11:55:04 kali-usb-armory-mkii dhclient[1052]: than a configuration issue please read the section on submitting
Jan 29 11:55:04 kali-usb-armory-mkii dhclient[1052]: bugs on either our web page at www.isc.org or in the README file
Jan 29 11:55:04 kali-usb-armory-mkii dhclient[1052]: before submitting a bug.  These pages explain the proper
Jan 29 11:55:04 kali-usb-armory-mkii dhclient[1052]: process and the information we find helpful for debugging.
Jan 29 11:55:04 kali-usb-armory-mkii dhclient[1052]:
Jan 29 11:55:04 kali-usb-armory-mkii dhclient[1052]: exiting.
Jan 29 11:55:04 kali-usb-armory-mkii ifup[1017]: ifup: failed to bring up eth0
Jan 29 11:55:04 kali-usb-armory-mkii ifup[1074]: RTNETLINK answers: File exists
Jan 29 11:55:04 kali-usb-armory-mkii ifup[1017]: ifup: failed to bring up usb0
Jan 29 11:55:05 kali-usb-armory-mkii systemd[1]: networking.service: Main process exited, code=exited, status=1/FAILURE
```

This is the device interface
```
lo: flags=73<UP,LOOPBACK,RUNNING>  mtu 65536
        inet 127.0.0.1  netmask 255.0.0.0
        inet6 ::1  prefixlen 128  scopeid 0x10<host>
        loop  txqueuelen 1000  (Local Loopback)
        RX packets 232  bytes 21952 (21.4 KiB)
        RX errors 0  dropped 0  overruns 0  frame 0
        TX packets 232  bytes 21952 (21.4 KiB)
        TX errors 0  dropped 0 overruns 0  carrier 0  collisions 0

usb0: flags=4163<UP,BROADCAST,RUNNING,MULTICAST>  mtu 1500
        inet 10.0.0.1  netmask 255.255.255.0  broadcast 10.0.0.255
        inet6 fe80::a8bb:ccff:fedd:eef1  prefixlen 64  scopeid 0x20<link>
        ether aa:bb:cc:dd:ee:f1  txqueuelen 1000  (Ethernet)
        RX packets 4445  bytes 365287 (356.7 KiB)
        RX errors 0  dropped 0  overruns 0  frame 0
        TX packets 2666  bytes 276892 (270.4 KiB)
        TX errors 0  dropped 0 overruns 0  carrier 0  collisions 0
```

This is my `/etc/resolv.conf` file:

```
nameserver 8.8.8.8
nameserver 8.8.4.4
```

This is my mac's network settings:

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

I see the `ifup: failed to bring up eth0` error, but I do not know why. Since the main interface should be `usb0` and there is no `eth0`, it won't connect to the internet. Any help would be much appreciated.

abarisani, 2024-05-15:
Kali is not configuring `usb0` correctly for some reason, I am also unsure on why `eth0` is being looked up, probably there is a configuration directive for this non-existent interface? We don't provide support for Kali so I'd suggest you bring the question to our [discussion forum](https://groups.google.com/g/usbarmory) where other Kali users might help you.

You might also want to set up the network interface manually and disable Kali automatic configuration.

hoonsubin, 2024-05-15:
After some hacking around, I discovered this was for a simple reason. I'll add the solution here for future reference.

Apparently, I had to edit both `/etc/network/interfaces/` and the content of `/etc/network/interfaces.d/`. Specifically, I had to remove `/etc/network/interfaces.d/eth0` and update the contents of `/etc/network/interfaces.d/usb0` to use the right IP address. This solved the issue for me.

abarisani, 2024-05-15:
Thank you! I appreciate you giving feedback to the issue so that it could be helpful to others.

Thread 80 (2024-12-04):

Schematic for USB Armory Mk II

Kailasamraju, 2024-12-04:
Hi,

We would like to request for PDF of the total schematics for USB Armory Mk II. The schematics available on the Git are pertaining to individual components and this is not very helpful for our research.

Request you to kindly assist us with the total schematics (PDF) and design files at the earliest please.

Regards.

abarisani, 2024-12-04:
In case you have commercial requests please contact us at usbarmory@withsecure.com

Closed 2024-12-04.

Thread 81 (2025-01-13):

Any plans for LAN version as standard order ?

udf2457, 2025-01-13:
Any plans to make the LAN version available for standard order with a case ?  Currently you're showing it as bulk-order only. :(

Thanks !

abarisani, 2025-01-13:
Thanks for your interest, unfortunately we cannot provide insights on our future plans. The documentation reflects the current state of things and it will be changed accordingly if there will be availability for non bulk orders for the LAN version. Kind regards.

Closed 2025-01-13.

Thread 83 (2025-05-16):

Serial console access without debug accessory

jonasjelonek, 2025-05-16:
Hi,

not really sure where to post this very technical question.

I'm trying to access the serial console of the USB Armory Mark II without using the debug accessory (DA), since it seems like the DA is nowhere available anymore. The readme in hardware/mark-two-debug-accessory states that UART2_TX and UART2_RX are exposed on the downstream USB-C port on pins A2 and A3. I was also able to retrace that on the PCB file of the Mark two provided in this repo.

I built the supported debian image which runs fine on the device, since I'm able to log into debian with ssh via the USB Ethernet gadget functionality that just pops up on my PC.

However, I'm not able to get any output. I used different USB-C breakout ports to get access to the pins of the USB-C port. Neither on the A2/A3 ports, nor on any other port I get any kind of output.
I properly connected USB-TTL adapters (various, based on FTDI232X, CP210x, CHA34X chipsets) and booted up the stick getting no reaction on the serial port, neither from U-Boot nor Debian.

At last, I monitored all pins of the downstream USB-C with a Logic Analyzer. Nearly all signal lines appear to be 'dead', giving no signal. Except for a single line, which I traced back as USB_CC2 on the port and PCB. On this line, I see a synchronous alternating signal, like a clock signal, with ~14.7 Hz.

So is there anything I miss here? From the documentation I had the impression I could easily hook up to the pins and use the serial console.
Is the debug accessory doing some kind of USB handshake on the CC2 line which needs to be done before I can access all of that or should that work out of the box as I tried?

abarisani, 2025-05-16:
@andrejro can help here

Closed 2025-05-19.

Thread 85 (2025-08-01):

Need debian OS image and flashing procedure for eMMC using SD card

hassan-xy, 2025-08-01:
Hi @andrejro
Thanks for the response in #84
Actually I am using arm linux, and debian might not be compatible. It would be really helpful of you if you can share debian image for usb armory and procedure to burn it to emmc using SD card.
Eagerly expecting a reply from you soon.

Thanks.

andrejro, 2025-08-01:
You can find all the instructions at the following link:
https://github.com/usbarmory/usbarmory-debian-base_image/releases/tag/20250410

For such requests please use the USB armory group (https://groups.google.com/g/usbarmory) as those are not issues.

Closed 2025-08-01.

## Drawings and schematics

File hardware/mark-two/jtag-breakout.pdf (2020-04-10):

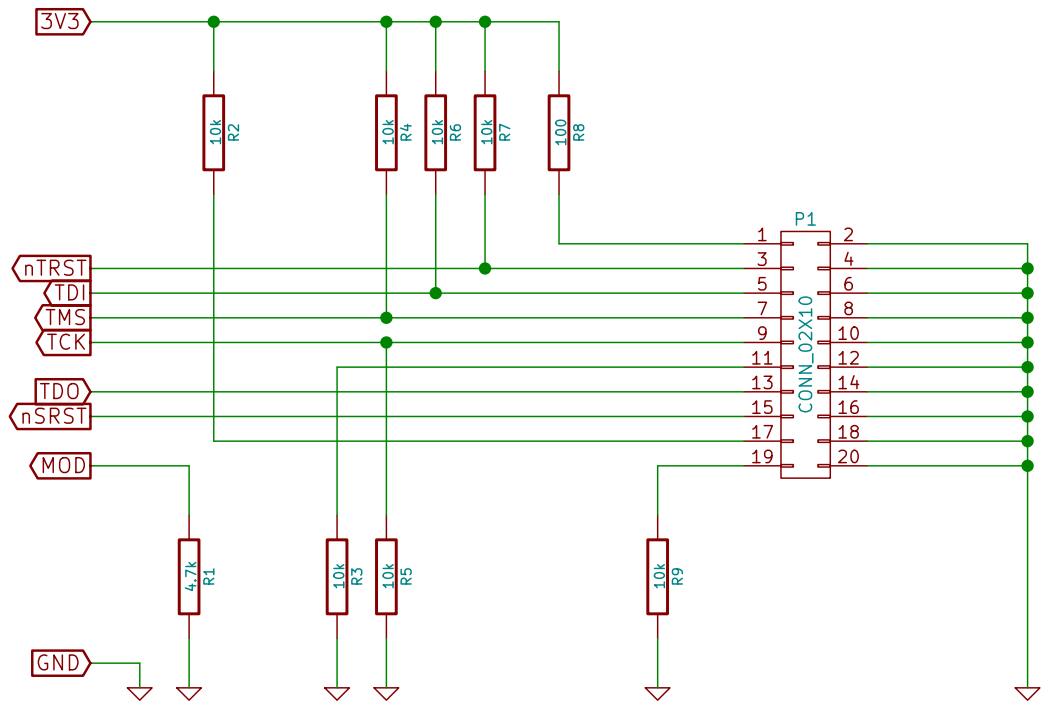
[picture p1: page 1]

9 | | | | 10
11 | | | 12
13 | | 14
15 | | 16
17 | | 18

File: jtag-breakout.sch Sheet: / F-Secure Copyright © 2020 F-Secure

Id: 1/1 Title: USB armory Mk II JTAG adapter

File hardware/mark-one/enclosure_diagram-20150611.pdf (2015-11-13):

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

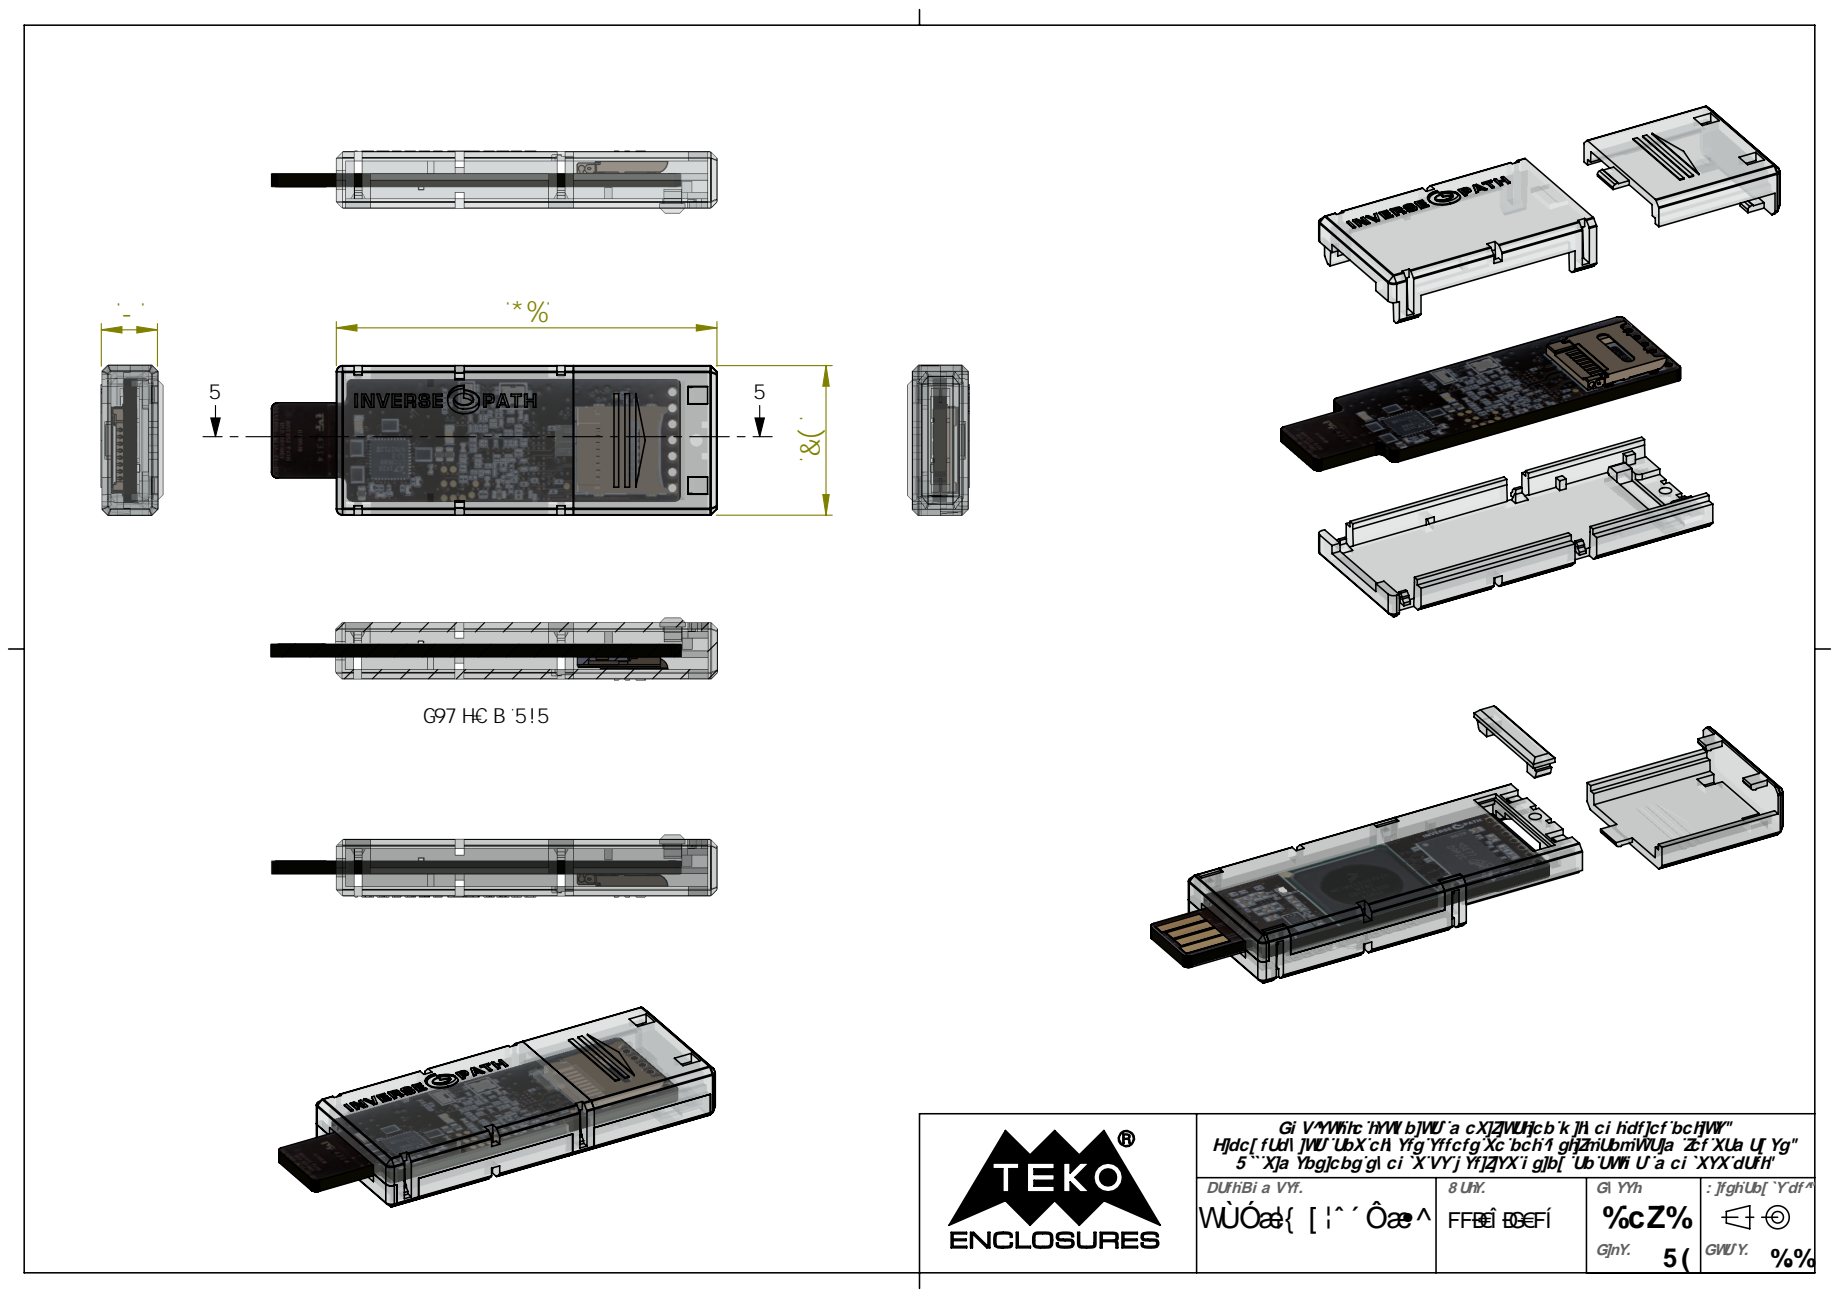
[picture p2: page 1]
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

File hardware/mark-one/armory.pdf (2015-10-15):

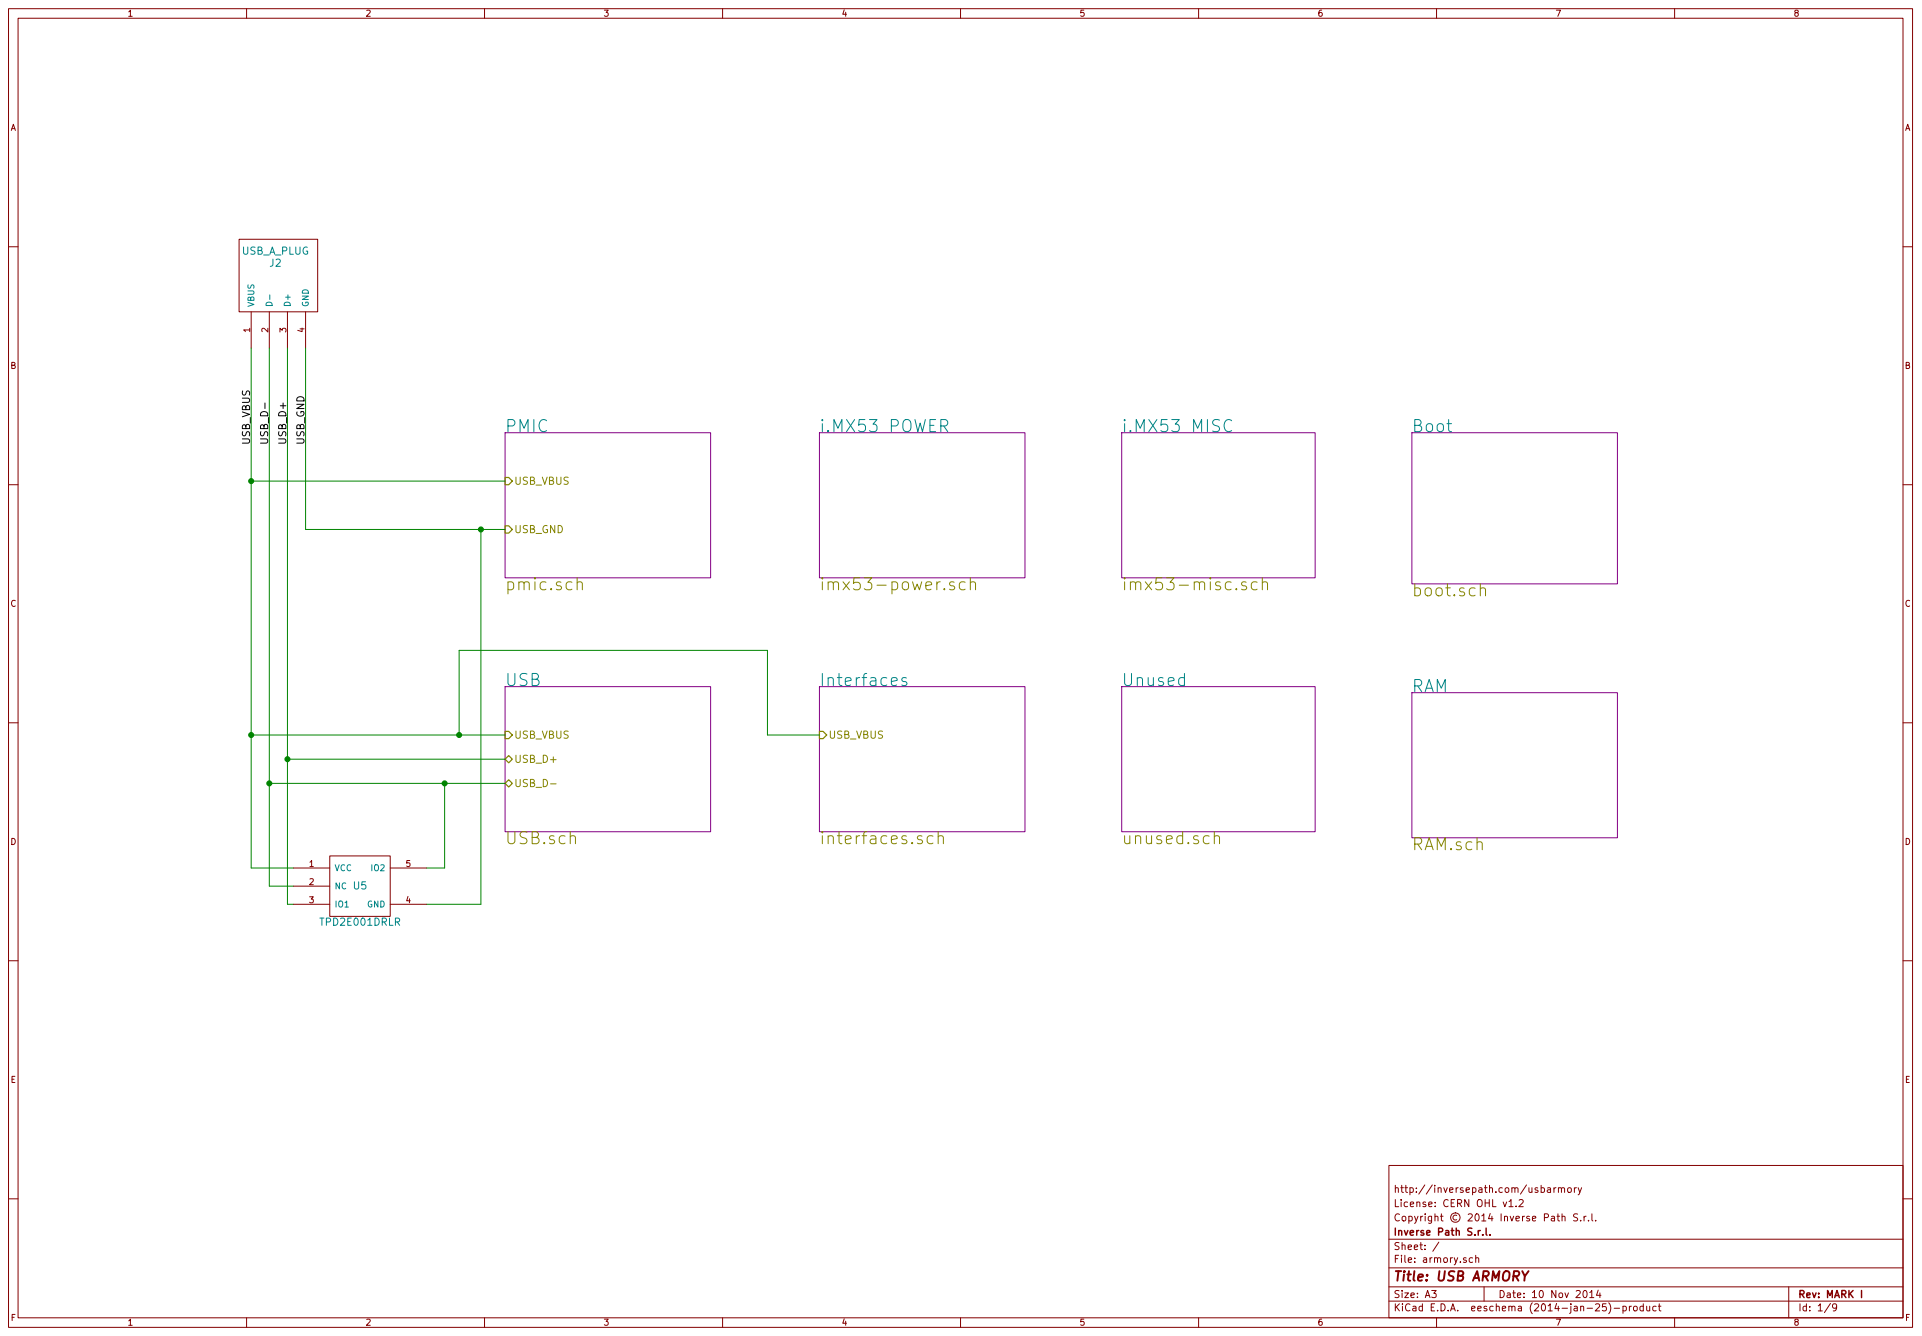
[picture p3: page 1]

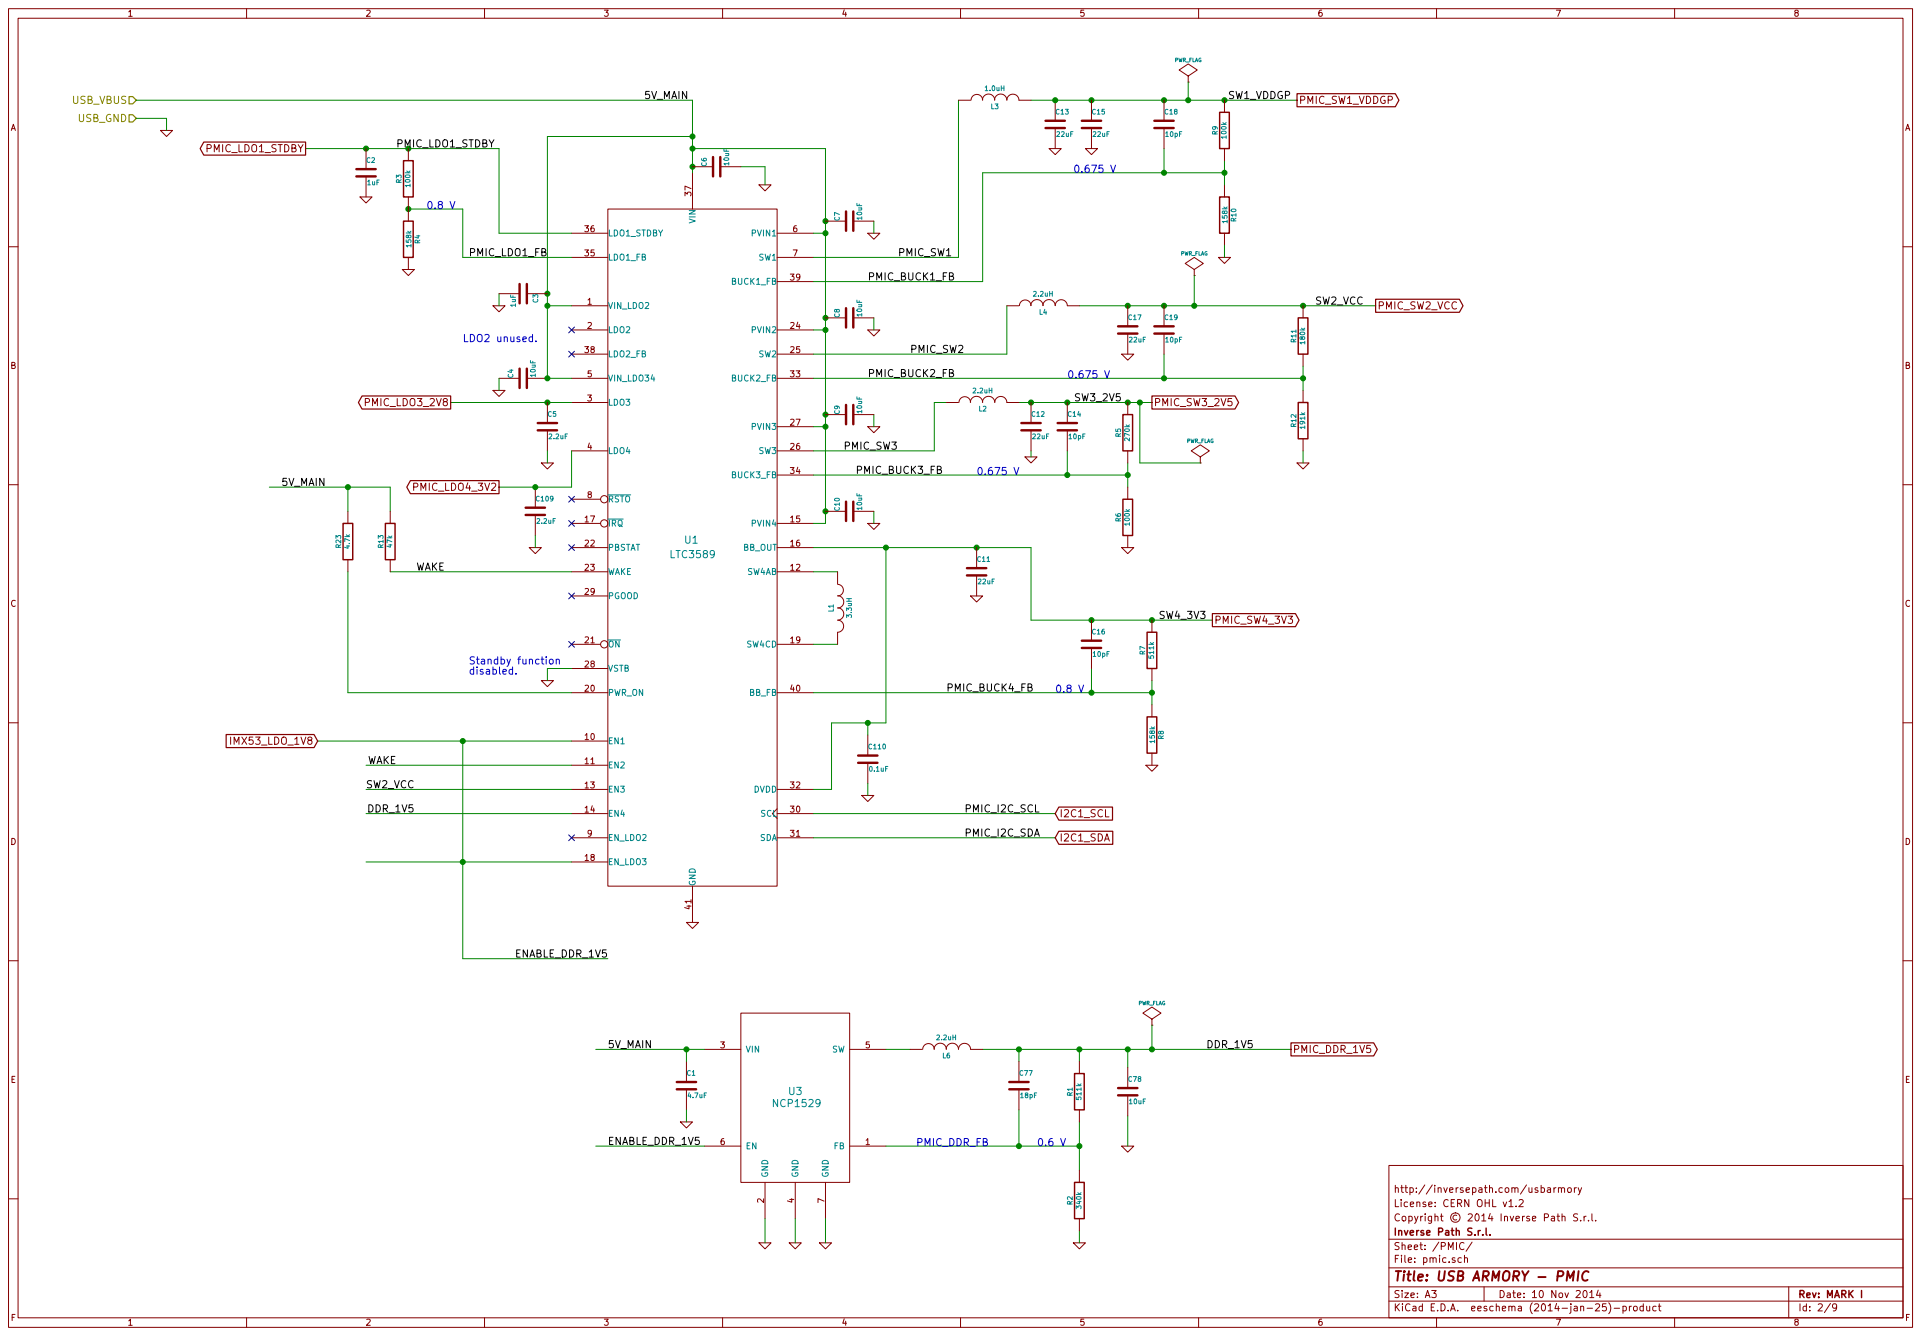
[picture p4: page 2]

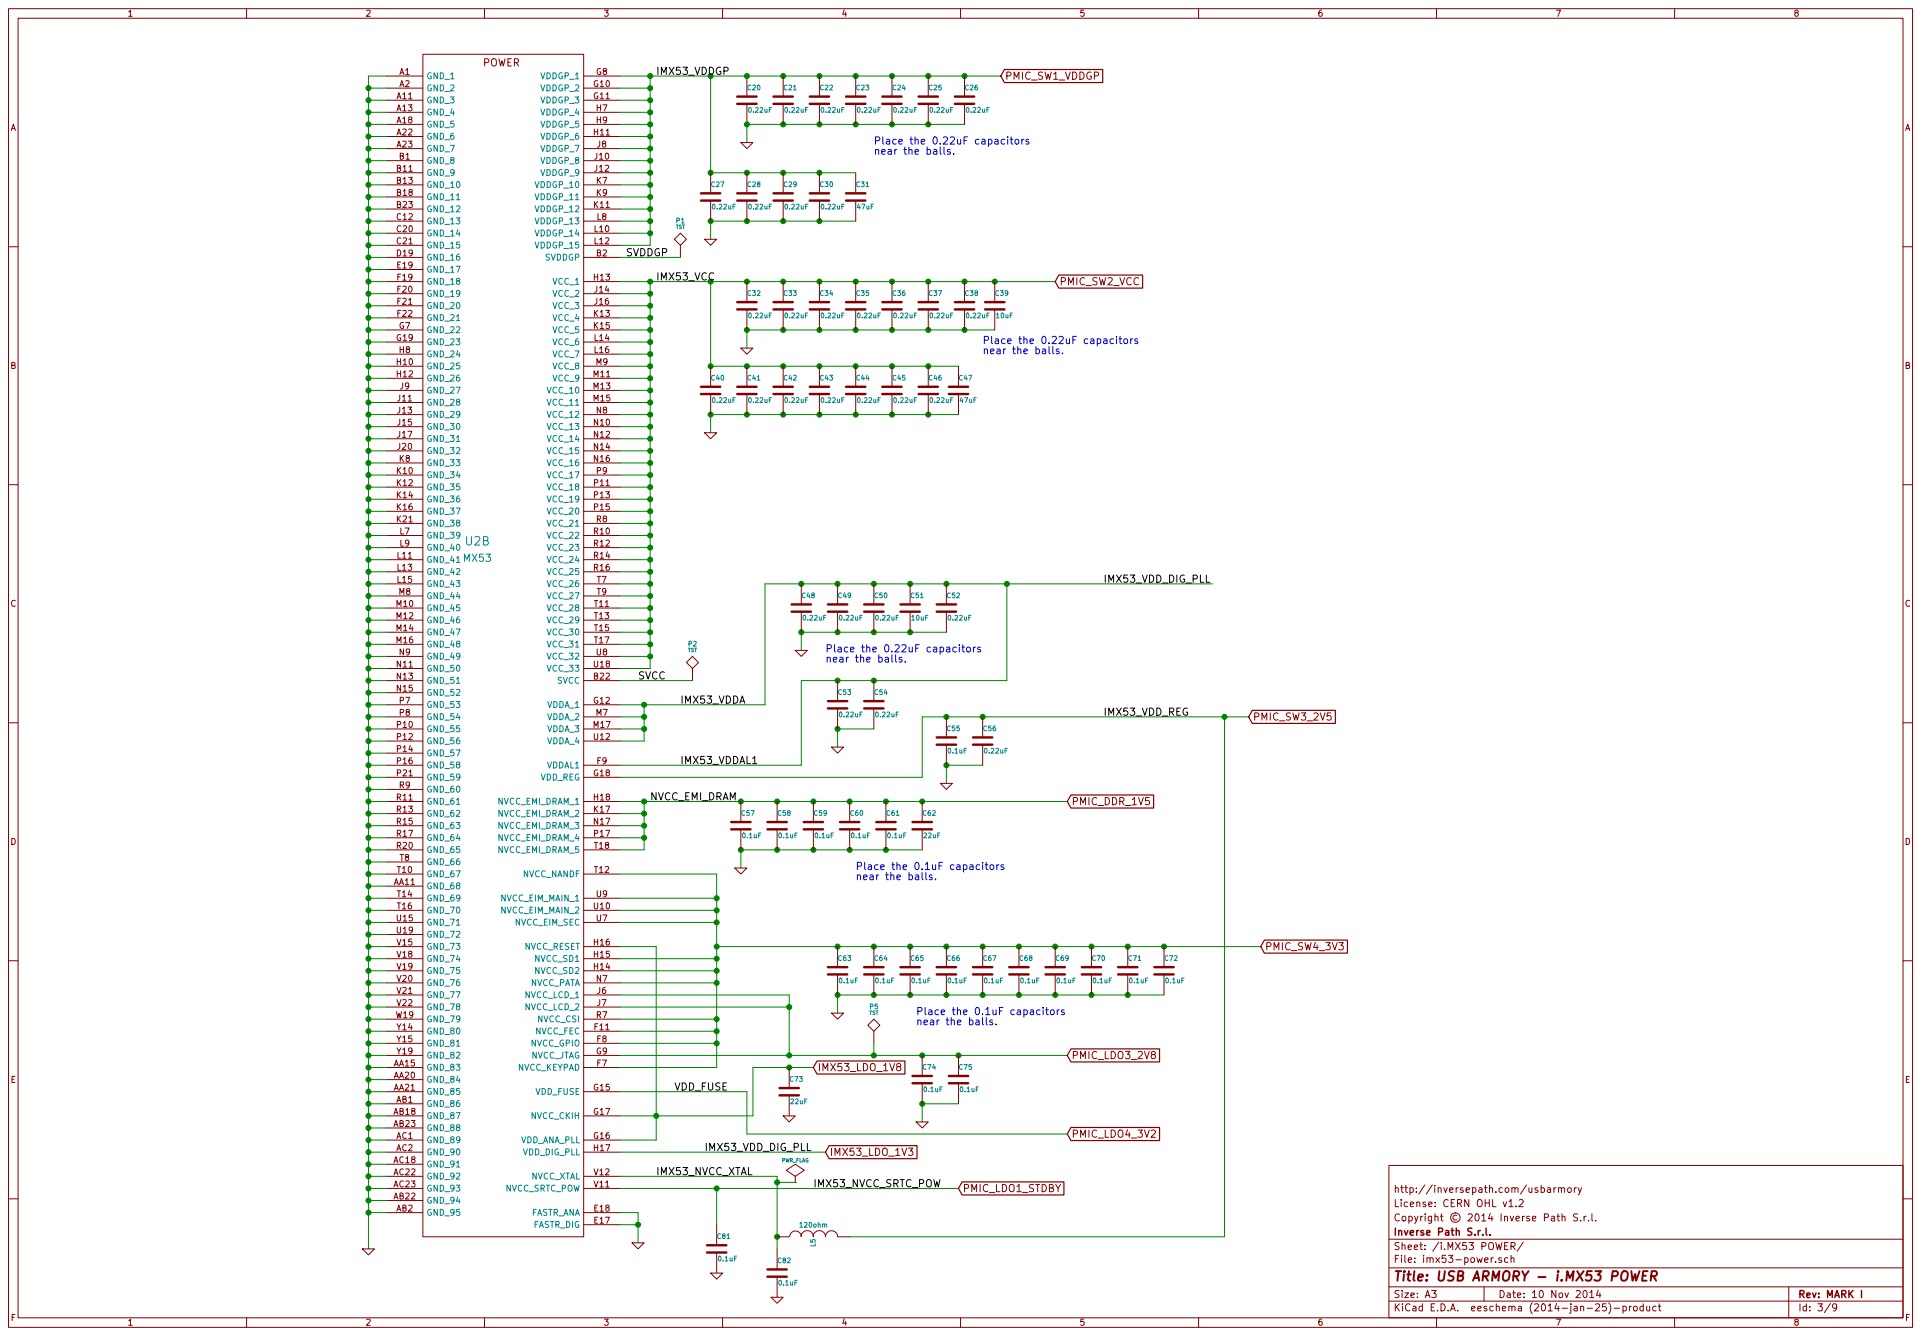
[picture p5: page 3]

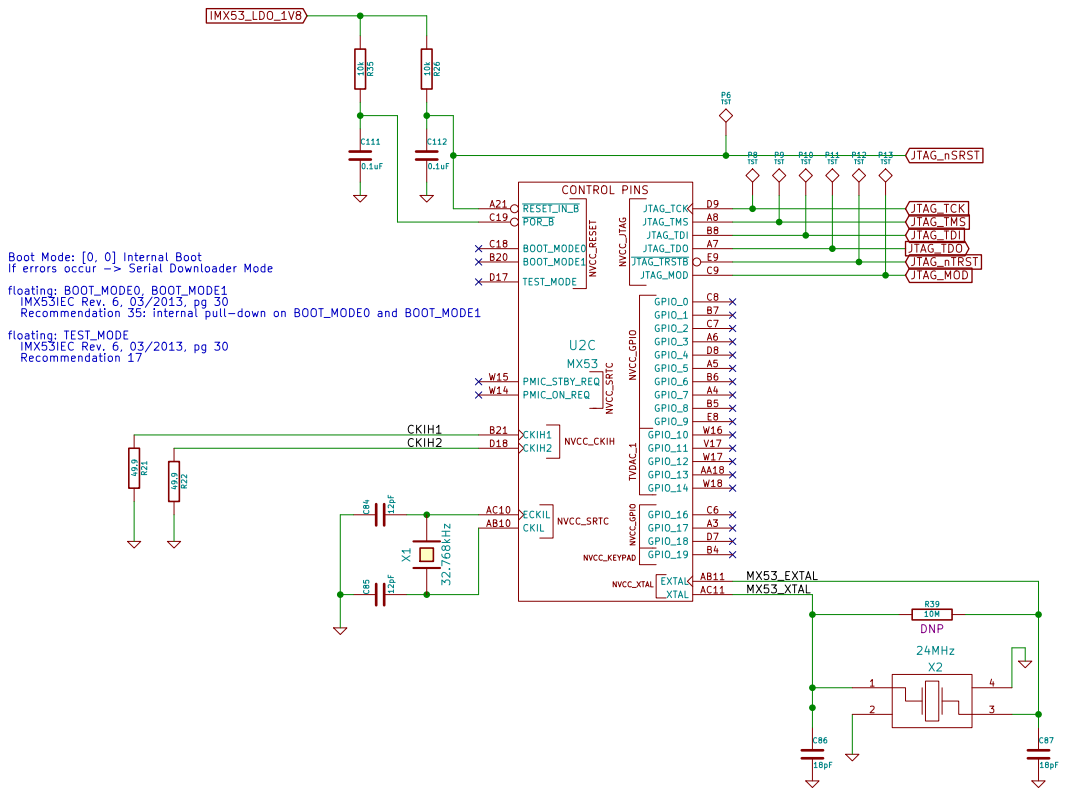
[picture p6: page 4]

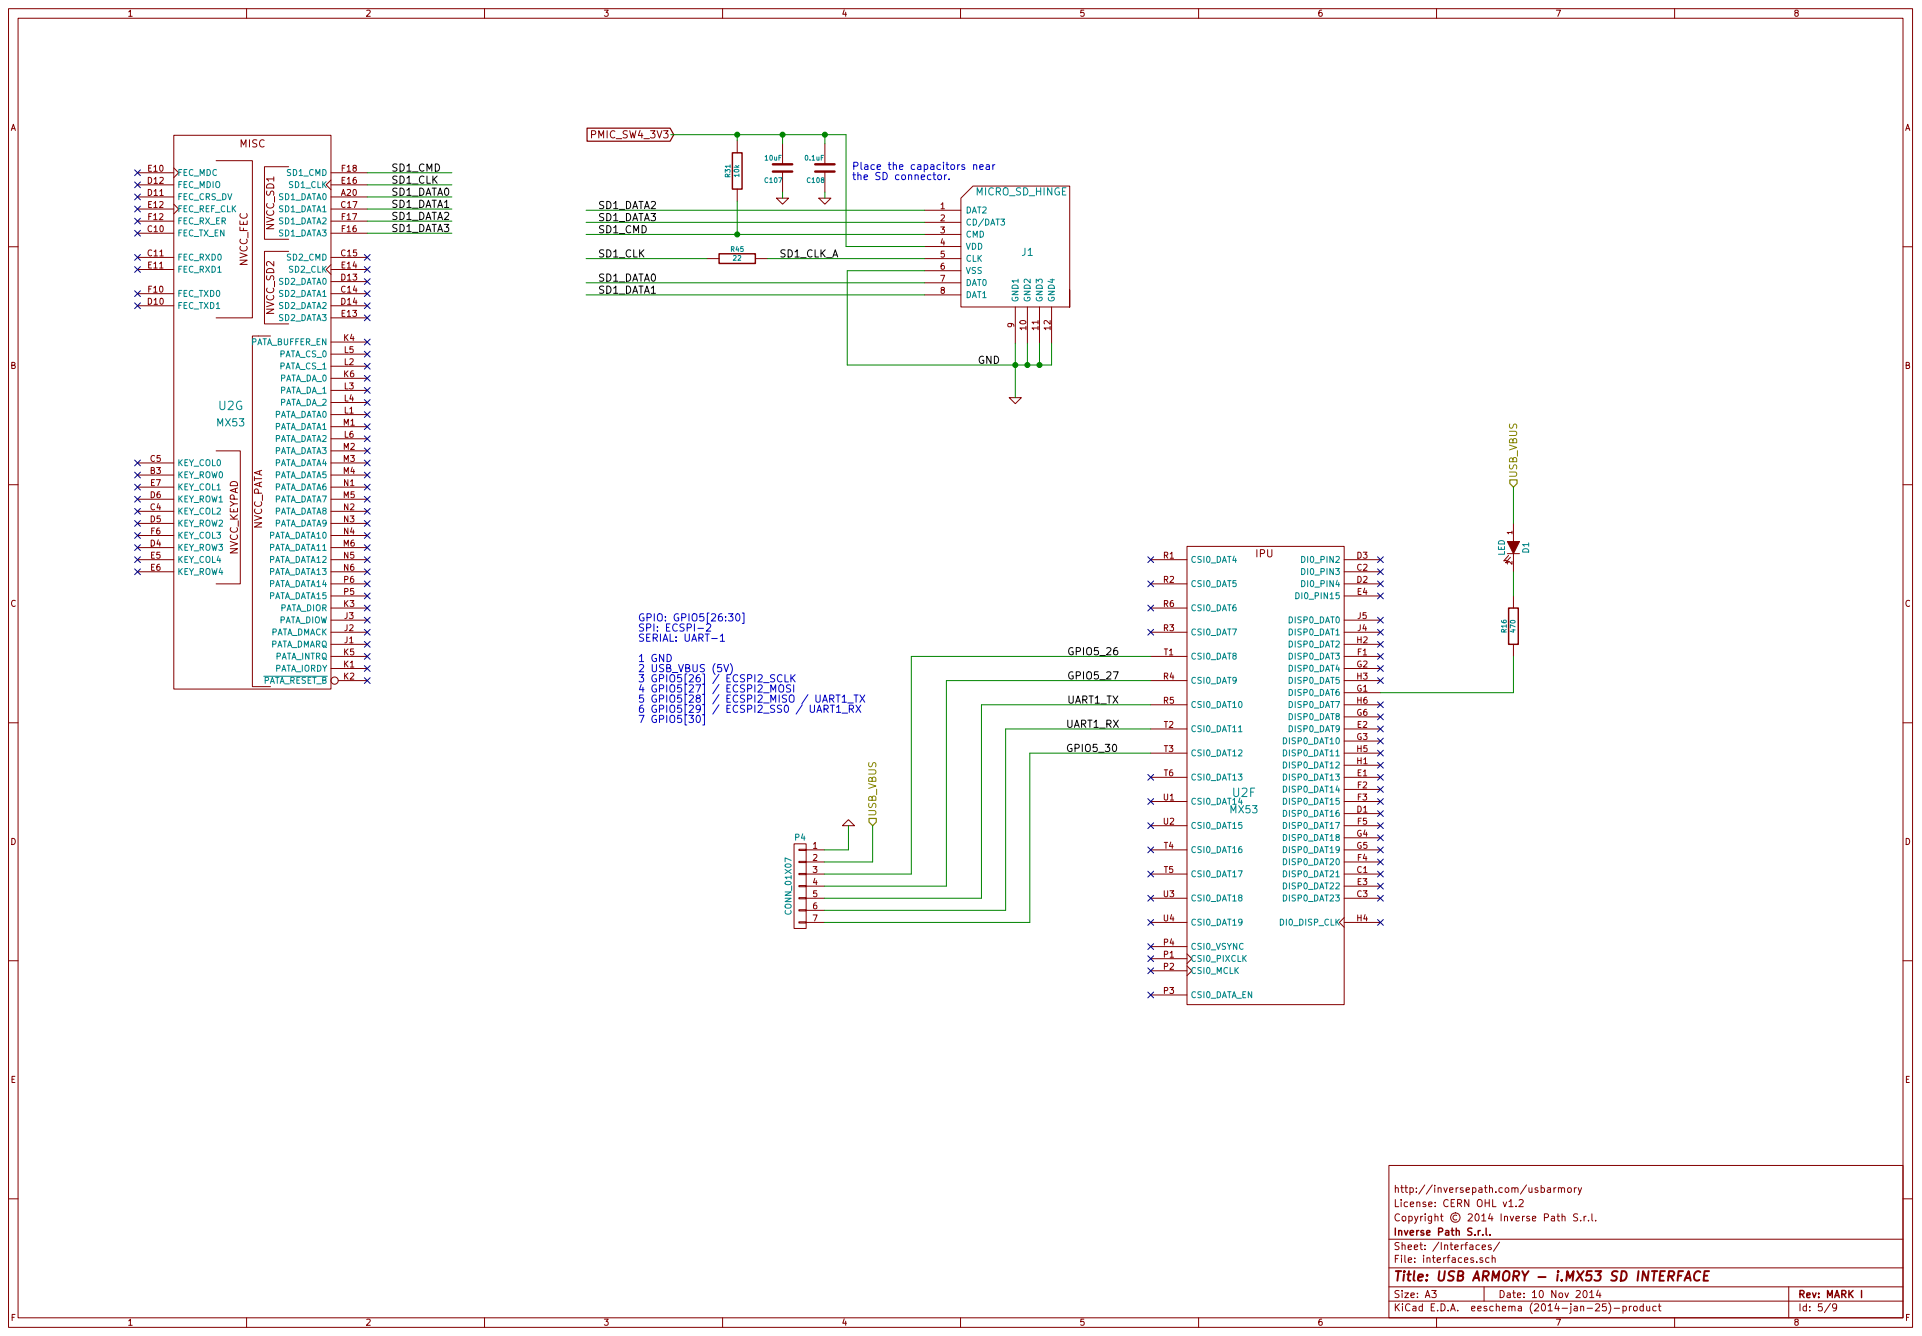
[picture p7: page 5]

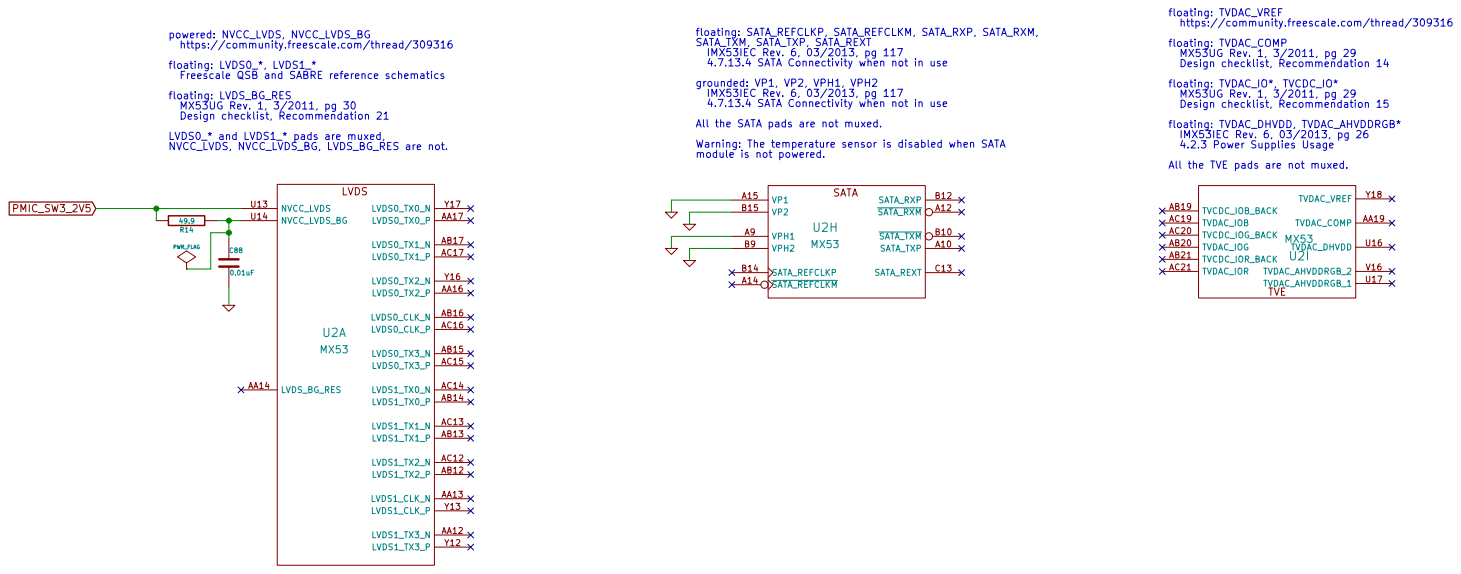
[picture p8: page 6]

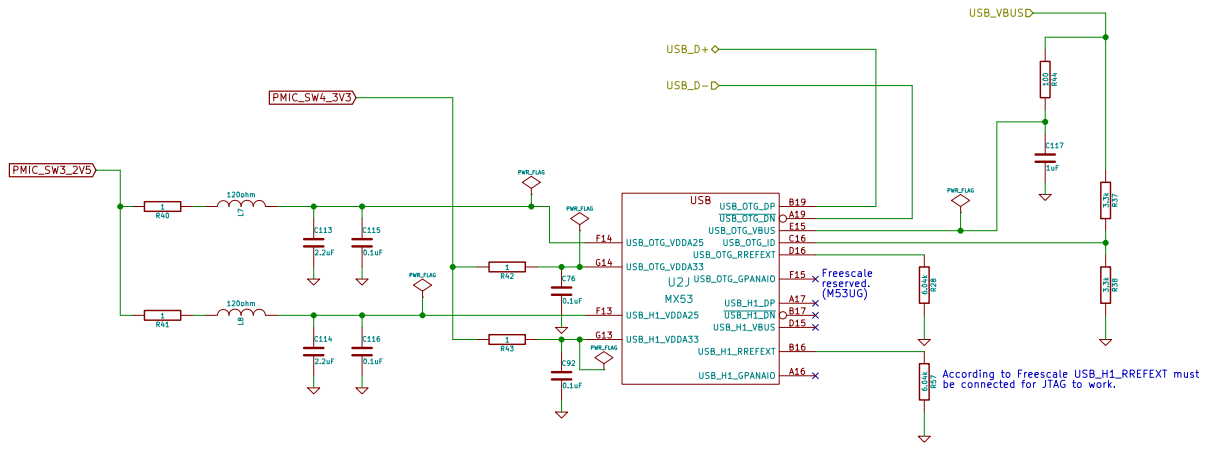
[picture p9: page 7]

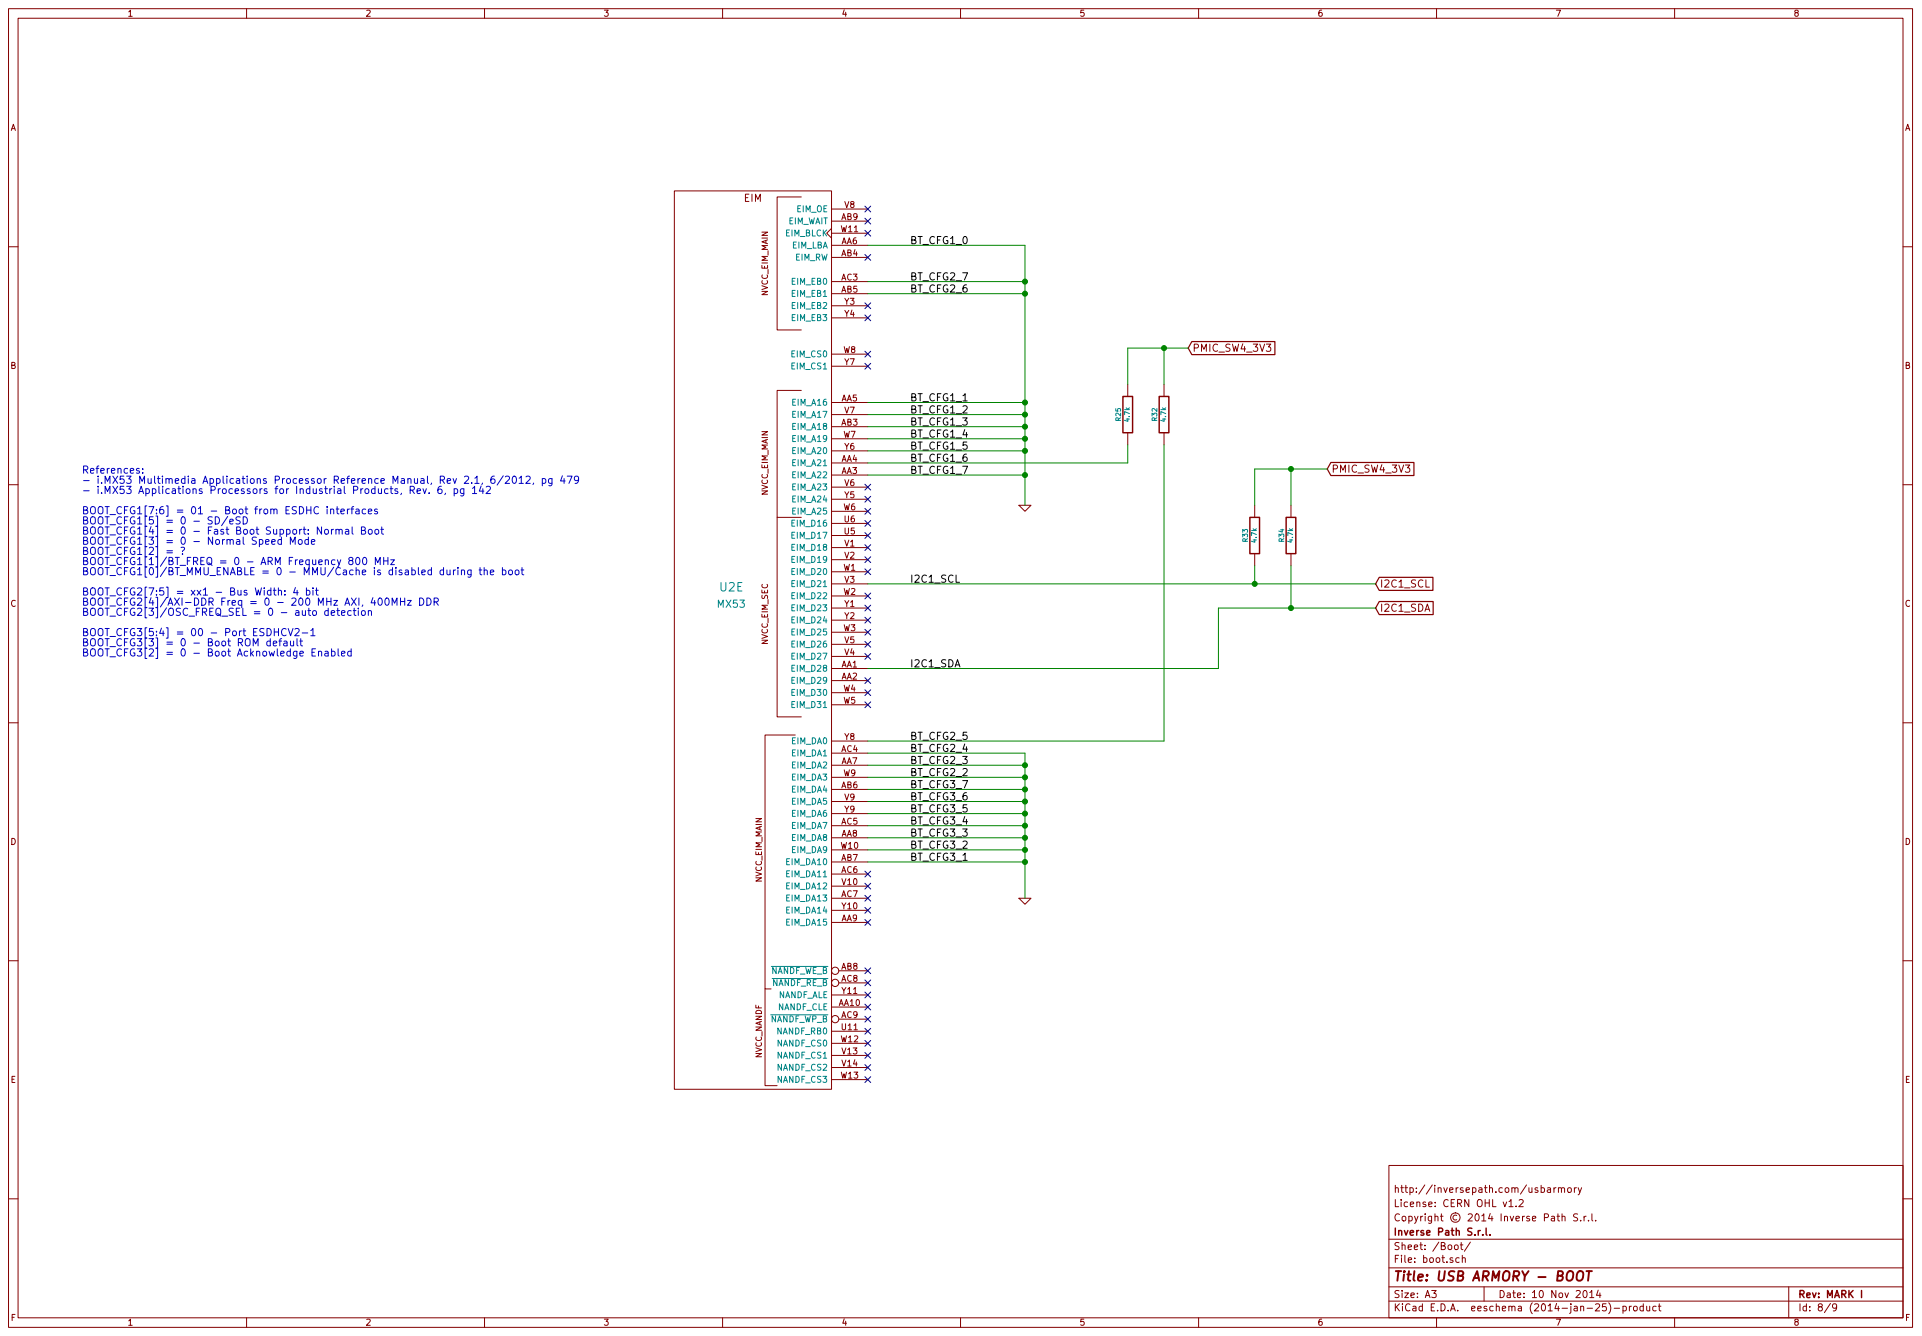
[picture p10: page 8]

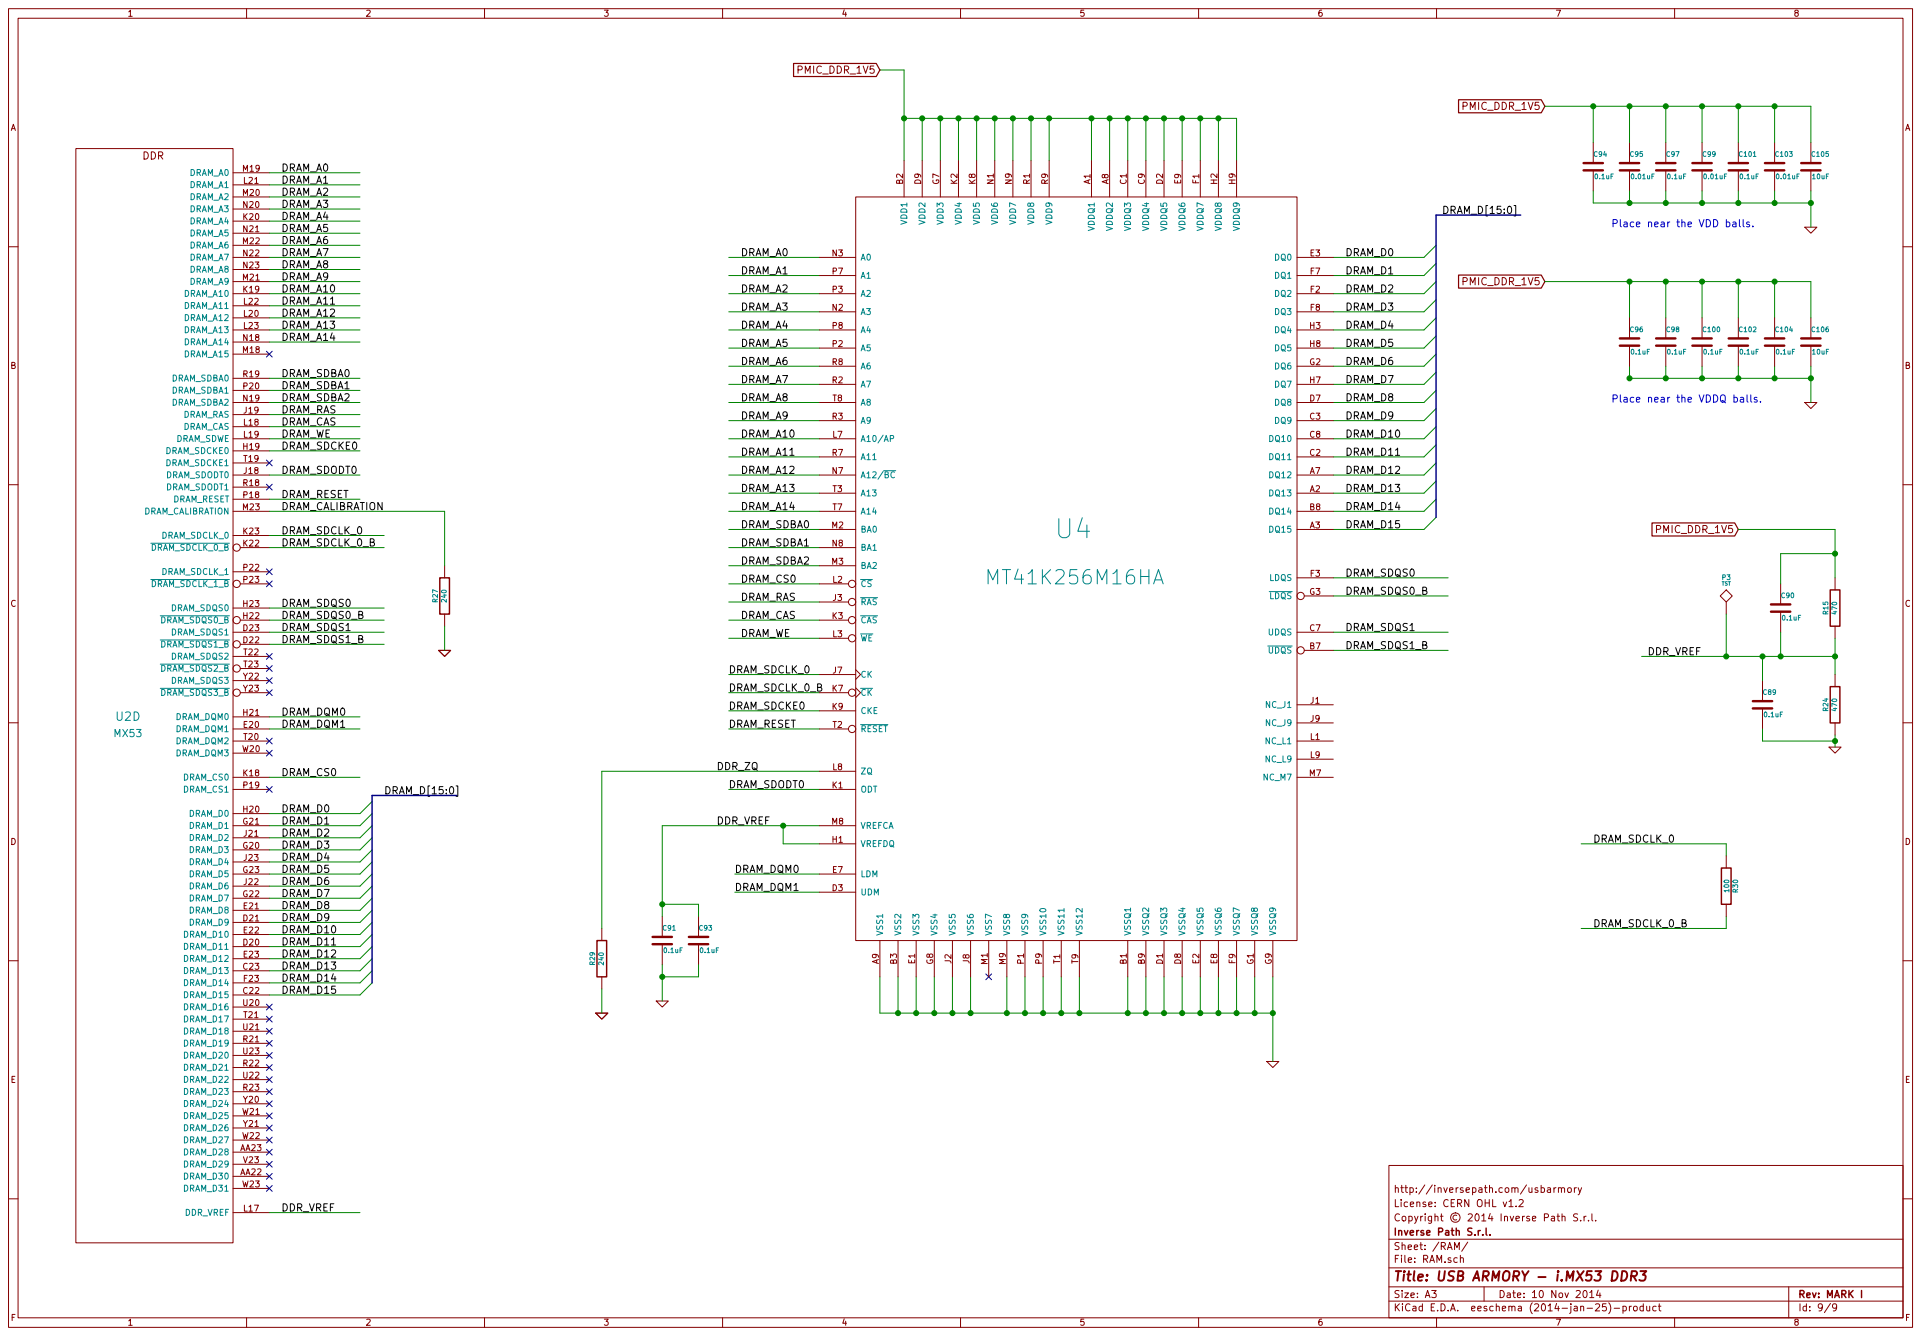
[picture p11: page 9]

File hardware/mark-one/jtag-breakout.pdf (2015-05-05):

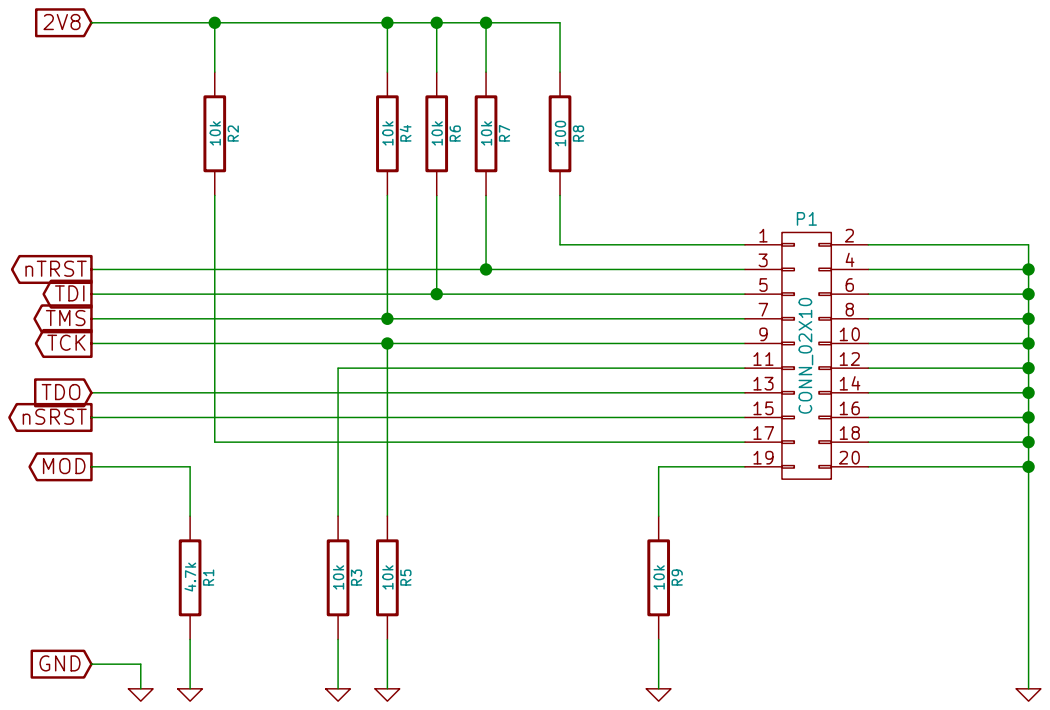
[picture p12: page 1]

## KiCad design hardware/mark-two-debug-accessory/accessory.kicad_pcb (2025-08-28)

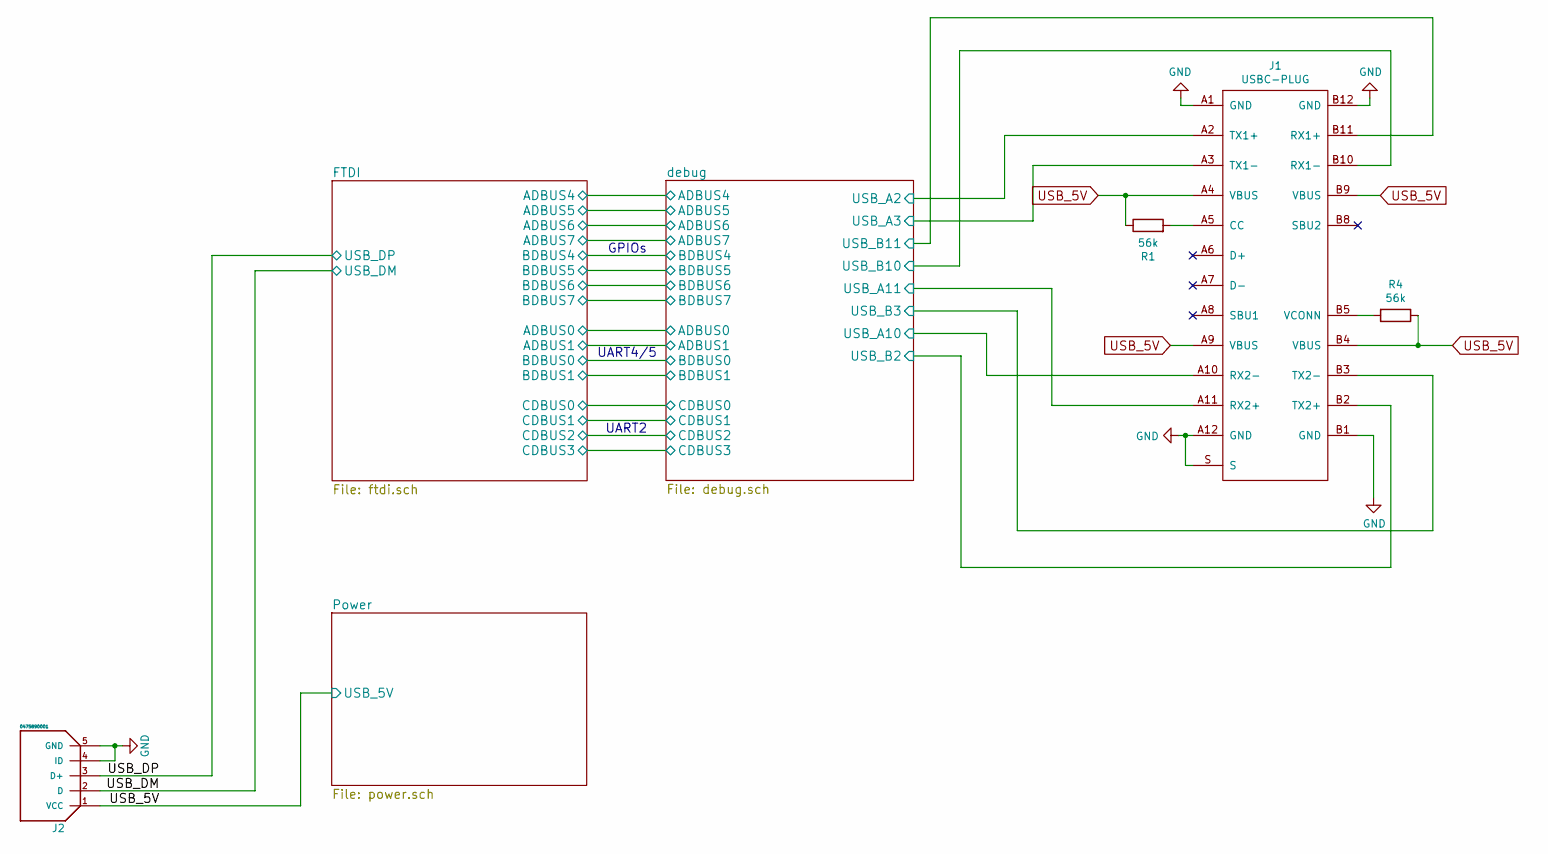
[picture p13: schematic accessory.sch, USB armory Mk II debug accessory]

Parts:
J1: USBC-PLUG; WURTH_632712000011; Mfg PN 632712000011
J2: 0475890001; MOLEX_0475890001; Mfg PN 0475890001
R1, R4: 56k; SM0603; Mfg PN MCT06030C5602FP500

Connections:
/USB_DM: J2.2 (D); also elsewhere on the board
/USB_DP: J2.3 (D+); also elsewhere on the board
/debug/USB_A2: J1.A2 (TX1+); also elsewhere on the board
/debug/USB_A3: J1.A3 (TX1-); also elsewhere on the board
/debug/USB_A10: J1.A10 (RX2-); also elsewhere on the board
/debug/USB_A11: J1.A11 (RX2+); also elsewhere on the board
/debug/USB_B2: J1.B2 (TX2+); also elsewhere on the board
/debug/USB_B3: J1.B3 (TX2-); also elsewhere on the board
/debug/USB_B10: J1.B10 (RX1-); also elsewhere on the board
/debug/USB_B11: J1.B11 (RX1+); also elsewhere on the board
GND: J1.A1 (GND), J1.A12 (GND), J1.B1 (GND), J1.B12 (GND), J1.S, J2.4 (ID), J2.5 (GND); also elsewhere on the board
unnamed: J1.A5 (CC), R1.2
unnamed: J1.B5 (VCONN), R4.2
USB_5V: J1.A4 (VBUS), J1.A9 (VBUS), J1.B4 (VBUS), J1.B9 (VBUS), J2.1 (VCC), R1.1, R4.1; also elsewhere on the board

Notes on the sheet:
GPIOs
UART4/5
UART2

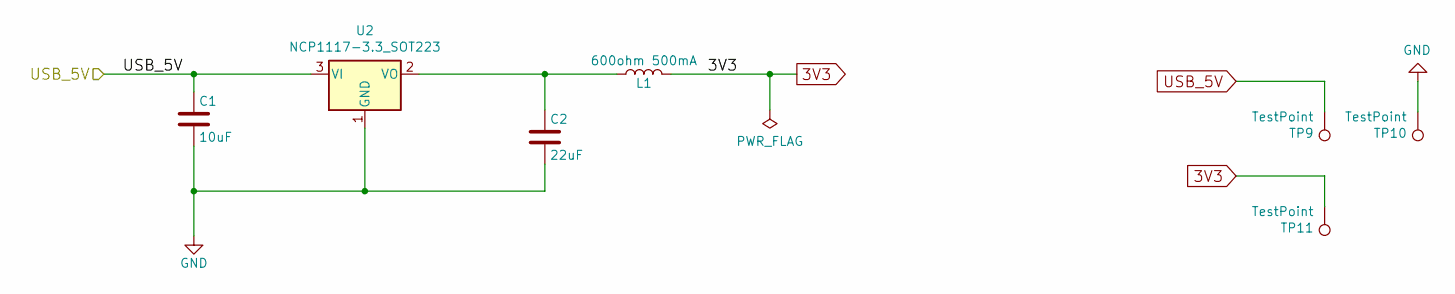
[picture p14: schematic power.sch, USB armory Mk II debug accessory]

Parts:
C1: 10uF; SM0603; Mfg PN C1608X5R1A106M080AC
C2: 22uF; SM0603; Mfg PN C1608X5R1A226M080AC
L1: 600ohm 500mA; SM0603; Mfg PN BLM18AG601SN1D
TP9, TP10, TP11: TestPoint; CONN_1
U2: NCP1117-3.3_SOT223; SOT-223; Mfg PN NCP1117ST33T3G

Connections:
3V3: L1.2, TP11.1; also elsewhere on the board
GND: C1.2, C2.2, TP10.1, U2.1 (GND); also elsewhere on the board
unnamed: C2.1, L1.1, U2.2 (VO)
USB_5V: C1.1, TP9.1, U2.3 (VI); also elsewhere on the board

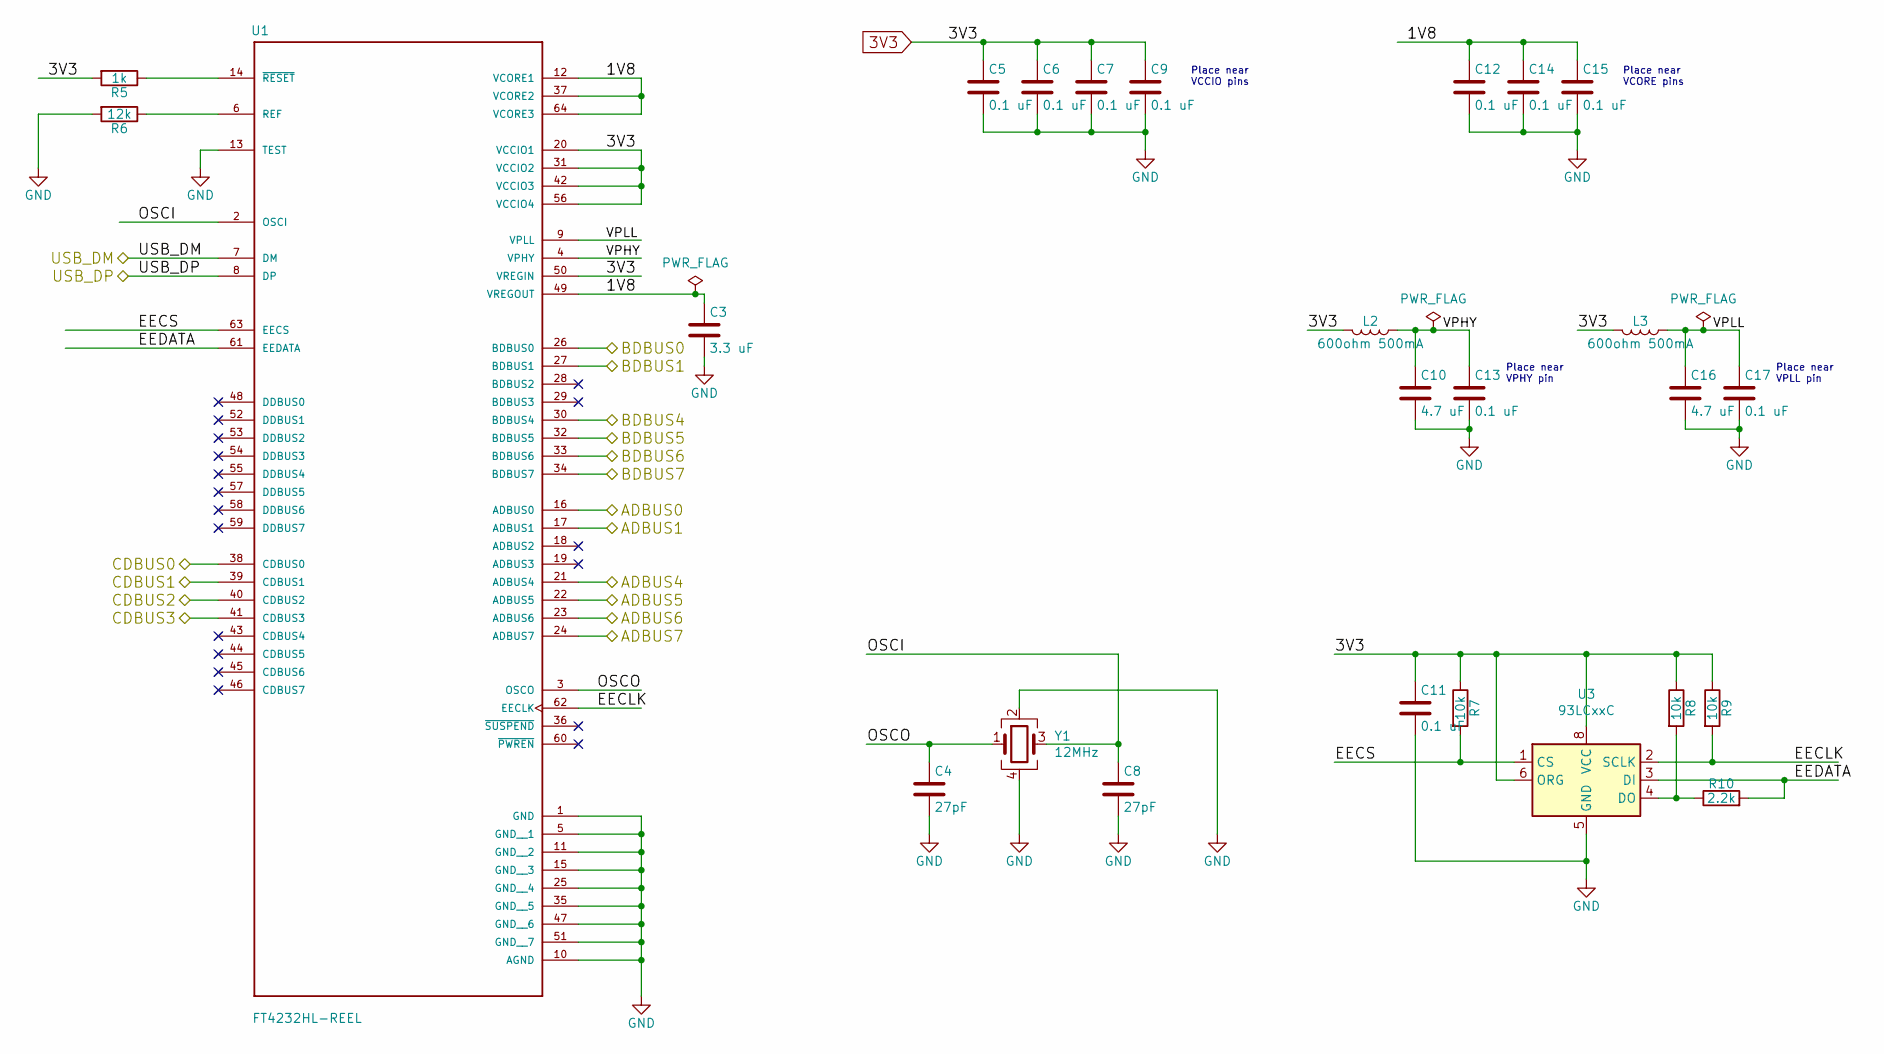
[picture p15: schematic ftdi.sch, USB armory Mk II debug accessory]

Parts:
C3: 3.3 uF; SM0603; Mfg PN C1608X5R1C335K080AC
C4, C8: 27pF; SM0603; Mfg PN GRM1885C1H270FA01D
C5, C6, C7, C9, C11, C12, C13, C14, C15, C17: 0.1 uF; SM0603; Mfg PN C1608X7R1E104K080AA
C10, C16: 4.7 uF; SM0603; Mfg PN CGB3B1X5R1A475M055AC
L2, L3: 600ohm 500mA; SM0603; Mfg PN BLM18AG601SN1D
R5: 1k; SM0603; Mfg PN RCA06031K00FKEAHP
R6: 12k; SM0603; Mfg PN CRCW060312K0FKEAC
R7, R8, R9: 10k; SM0603; Mfg PN CRCW060310K0FKEA
R10: 2.2k; SM0603; Mfg PN RCS06032K20JNEA
U1: FT4232HL-REEL; QFP50P1200X1200X160-64N; Mfg PN FT4232HL-REEL
U3: 93LCxxC; 8L_SOIC_Narrow_3_90_SN_C04-057C; Mfg PN 93LC56C-I/SN
Y1: 12MHz; TXC-3.2x2.5; Mfg PN 7M-12.000MAAJ-T

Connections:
3V3: C5.1, C6.1, C7.1, C9.1, C11.1, L2.1, L3.1, R5.2, R7.1, R8.1, R9.1, U1.20 (VCCIO1), U1.31 (VCCIO2), U1.42 (VCCIO3), U1.50 (VREGIN), U1.56 (VCCIO4), U3.6 (ORG), U3.8 (VCC); also elsewhere on the board
/FTDI/1V8: C3.1, C12.1, C14.1, C15.1, U1.12 (VCORE1), U1.37 (VCORE2), U1.49 (VREGOUT), U1.64 (VCORE3)
/FTDI/ADBUS0: U1.16 (ADBUS0); also elsewhere on the board
/FTDI/ADBUS1: U1.17 (ADBUS1); also elsewhere on the board
/FTDI/ADBUS4: U1.21 (ADBUS4); also elsewhere on the board
/FTDI/ADBUS5: U1.22 (ADBUS5); also elsewhere on the board
/FTDI/ADBUS6: U1.23 (ADBUS6); also elsewhere on the board
/FTDI/ADBUS7: U1.24 (ADBUS7); also elsewhere on the board
/FTDI/BDBUS0: U1.26 (BDBUS0); also elsewhere on the board
/FTDI/BDBUS1: U1.27 (BDBUS1); also elsewhere on the board
/FTDI/BDBUS4: U1.30 (BDBUS4); also elsewhere on the board
/FTDI/BDBUS5: U1.32 (BDBUS5); also elsewhere on the board
/FTDI/BDBUS6: U1.33 (BDBUS6); also elsewhere on the board
/FTDI/BDBUS7: U1.34 (BDBUS7); also elsewhere on the board
/FTDI/CDBUS0: U1.38 (CDBUS0); also elsewhere on the board
/FTDI/CDBUS1: U1.39 (CDBUS1); also elsewhere on the board
/FTDI/CDBUS2: U1.40 (CDBUS2); also elsewhere on the board
/FTDI/CDBUS3: U1.41 (CDBUS3); also elsewhere on the board
/FTDI/EECLK: R9.2, U1.62 (EECLK), U3.2 (SCLK)
/FTDI/EECS: R7.2, U1.63 (EECS), U3.1 (CS)
/FTDI/EEDATA: R10.2, U1.61 (EEDATA), U3.3 (DI)
/FTDI/OSCI: C8.1, U1.2 (OSCI), Y1.3
/FTDI/OSCO: C4.1, U1.3 (OSCO), Y1.1
/FTDI/VPHY: C10.1, C13.1, L2.2, U1.4 (VPHY)
/FTDI/VPLL: C16.1, C17.1, L3.2, U1.9 (VPLL)
/USB_DM: U1.7 (DM); also elsewhere on the board
/USB_DP: U1.8 (DP); also elsewhere on the board
GND: C3.2, C4.2, C5.2, C6.2, C7.2, C8.2, C9.2, C10.2, C11.2, C12.2, C13.2, C14.2, C15.2, C16.2, C17.2, R6.2, U1.1 (GND), U1.5 (GND__1), U1.10 (AGND), U1.11 (GND__2), U1.13 (TEST), U1.15 (GND__3), U1.25 (GND__4), U1.35 (GND__5), U1.47 (GND__6), U1.51 (GND__7), U3.5 (GND), Y1.2, Y1.4; also elsewhere on the board
unnamed: R5.1, U1.14 (~RESET~)
unnamed: R6.1, U1.6 (REF)
unnamed: R8.2, R10.1, U3.4 (DO)

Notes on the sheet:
Place near VCORE pins
Place near VCCIO pins
Place near VPLL pin
Place near VPHY pin

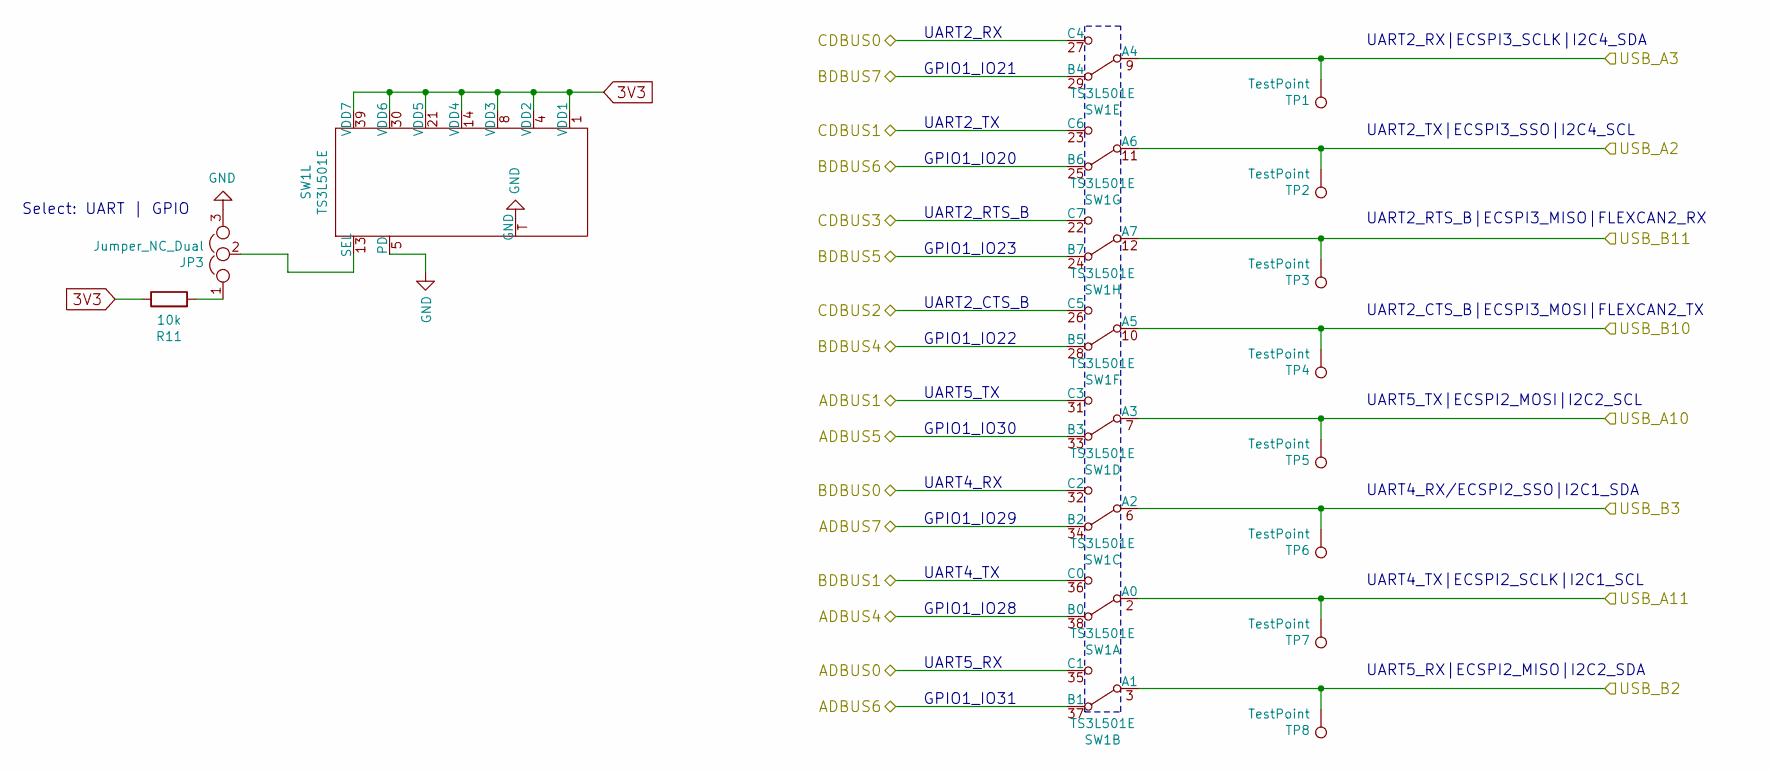
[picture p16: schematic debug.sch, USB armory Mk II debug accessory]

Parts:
JP3: Jumper_NC_Dual; SIL-3; Mfg PN 68000-103HLF
R11: 10k; SM0603; Mfg PN CRCW060310K0FKEA
SW1: TS3L501E; R-PWQFN-N42
TP1, TP2, TP3, TP4, TP5, TP6, TP7, TP8: TestPoint; CONN_1

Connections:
3V3: R11.1, SW1.1 (VDD1), SW1.4 (VDD2), SW1.8 (VDD3), SW1.14 (VDD4), SW1.21 (VDD5), SW1.30 (VDD6), SW1.39 (VDD7); also elsewhere on the board
/FTDI/ADBUS0: SW1.35 (C1); also elsewhere on the board
/FTDI/ADBUS1: SW1.31 (C3); also elsewhere on the board
/FTDI/ADBUS4: SW1.38 (B0); also elsewhere on the board
/FTDI/ADBUS5: SW1.33 (B3); also elsewhere on the board
/FTDI/ADBUS6: SW1.37 (B1); also elsewhere on the board
/FTDI/ADBUS7: SW1.34 (B2); also elsewhere on the board
/FTDI/BDBUS0: SW1.32 (C2); also elsewhere on the board
/FTDI/BDBUS1: SW1.36 (C0); also elsewhere on the board
/FTDI/BDBUS4: SW1.28 (B5); also elsewhere on the board
/FTDI/BDBUS5: SW1.24 (B7); also elsewhere on the board
/FTDI/BDBUS6: SW1.25 (B6); also elsewhere on the board
/FTDI/BDBUS7: SW1.29 (B4); also elsewhere on the board
/FTDI/CDBUS0: SW1.27 (C4); also elsewhere on the board
/FTDI/CDBUS1: SW1.23 (C6); also elsewhere on the board
/FTDI/CDBUS2: SW1.26 (C5); also elsewhere on the board
/FTDI/CDBUS3: SW1.22 (C7); also elsewhere on the board
/debug/USB_A2: SW1.11 (A6), TP2.1; also elsewhere on the board
/debug/USB_A3: SW1.9 (A4), TP1.1; also elsewhere on the board
/debug/USB_A10: SW1.7 (A3), TP5.1; also elsewhere on the board
/debug/USB_A11: SW1.2 (A0), TP7.1; also elsewhere on the board
/debug/USB_B2: SW1.3 (A1), TP8.1; also elsewhere on the board
/debug/USB_B3: SW1.6 (A2), TP6.1; also elsewhere on the board
/debug/USB_B10: SW1.10 (A5), TP4.1; also elsewhere on the board
/debug/USB_B11: SW1.12 (A7), TP3.1; also elsewhere on the board
GND: JP3.3, SW1.5 (PD), SW1.T (GND); also elsewhere on the board
unnamed: JP3.1, R11.2
unnamed: JP3.2, SW1.13 (SEL)

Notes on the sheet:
UART2_CTS_B|ECSPI3_MOSI|FLEXCAN2_TX
UART5_TX|ECSPI2_MOSI|I2C2_SCL
UART4_RX/ECSPI2_SSO|I2C1_SDA
UART4_TX|ECSPI2_SCLK|I2C1_SCL
UART5_RX|ECSPI2_MISO|I2C2_SDA
UART2_RTS_B|ECSPI3_MISO|FLEXCAN2_RX
UART2_TX|ECSPI3_SSO|I2C4_SCL
UART2_RX|ECSPI3_SCLK|I2C4_SDA
GPIO1_IO20
GPIO1_IO21
UART2_RX
UART2_TX
UART2_RTS_B
UART2_CTS_B
UART5_TX
UART4_RX
Select: UART | GPIO
UART4_TX
UART5_RX
GPIO1_IO23
GPIO1_IO22
GPIO1_IO30
GPIO1_IO29
GPIO1_IO28
GPIO1_IO31

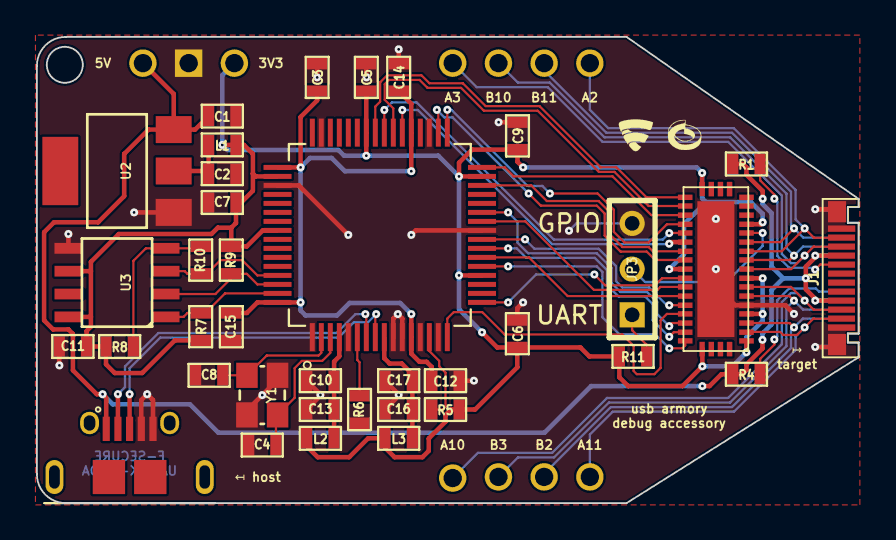
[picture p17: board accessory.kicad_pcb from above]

Board: 2 copper layers, 45.7 x 25.9 mm, 50 parts (0 on the bottom side), 45 nets.

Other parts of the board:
FSC_LOGO_NO_TEXT_SMALL: G***; FSC_LOGO_NO_TEXT_SMALL
Ref**: Val**; IP_LOGO_NO_TEXT_SMALL

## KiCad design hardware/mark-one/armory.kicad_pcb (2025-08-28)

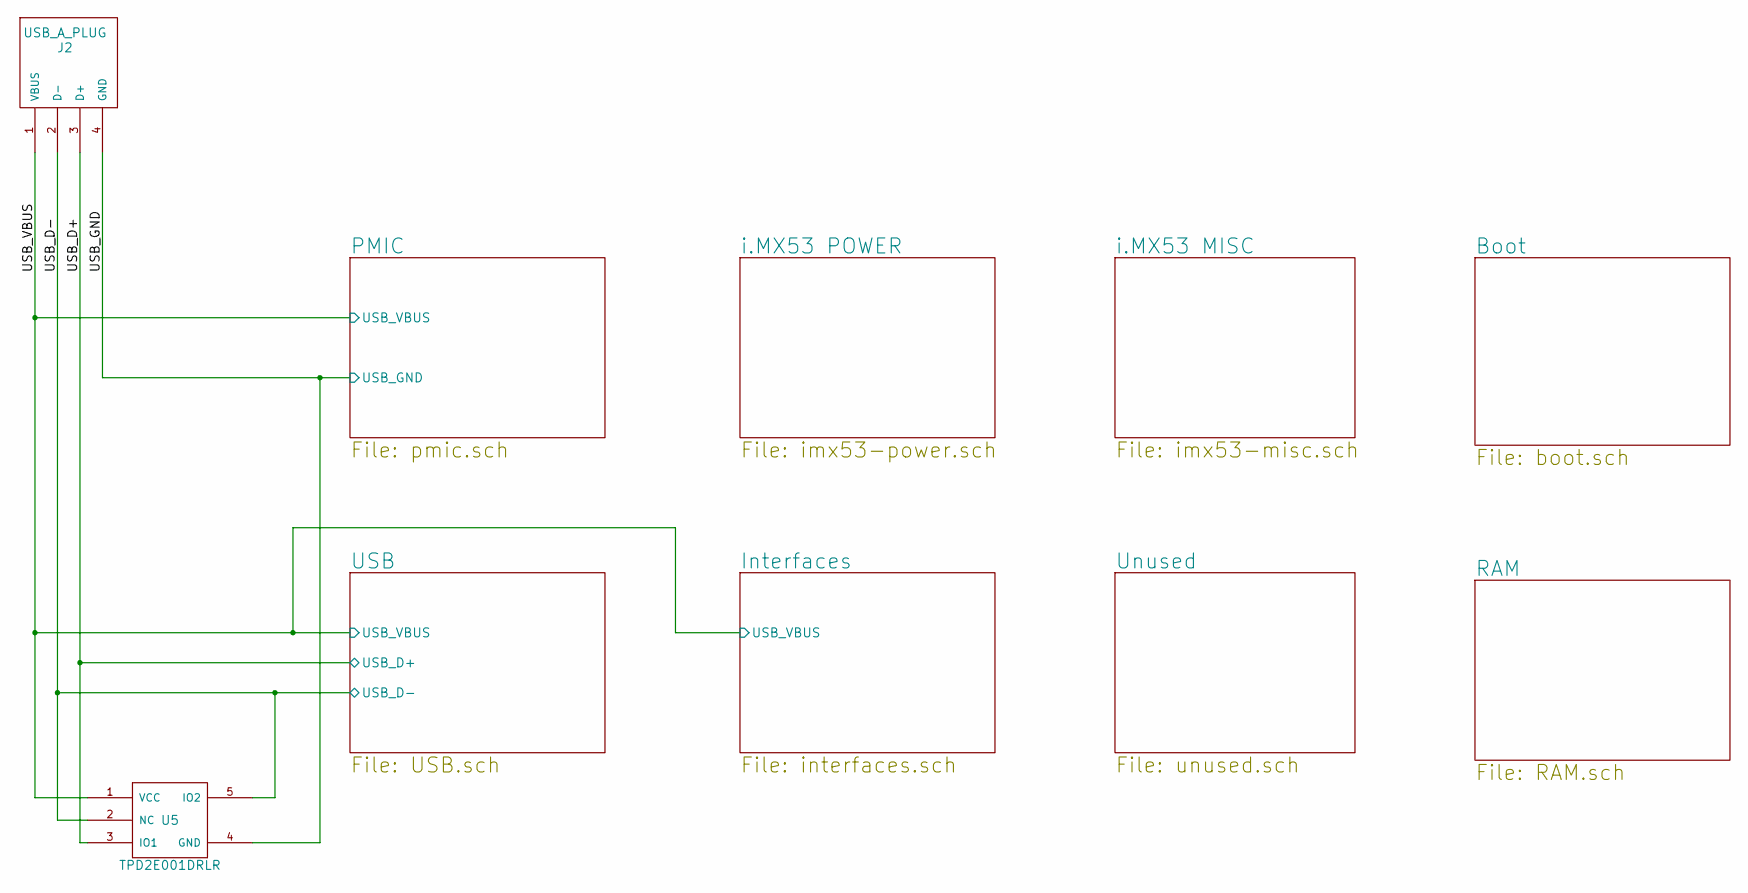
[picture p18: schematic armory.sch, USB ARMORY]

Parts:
J2: USB_A_PLUG; usb-PCB
U5: TPD2E001DRLR; R-PDSO-N5; Mfg PN TPD2E001DRLR

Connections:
/Interfaces/USB_VBUS: J2.1 (VBUS), U5.1 (VCC); also elsewhere on the board
/USB/USB_D+: J2.3 (D+), U5.3 (IO1); also elsewhere on the board
/USB/USB_D-: J2.2 (D-), U5.2 (NC), U5.5 (IO2); also elsewhere on the board
GND: J2.4 (GND), U5.4 (GND); also elsewhere on the board

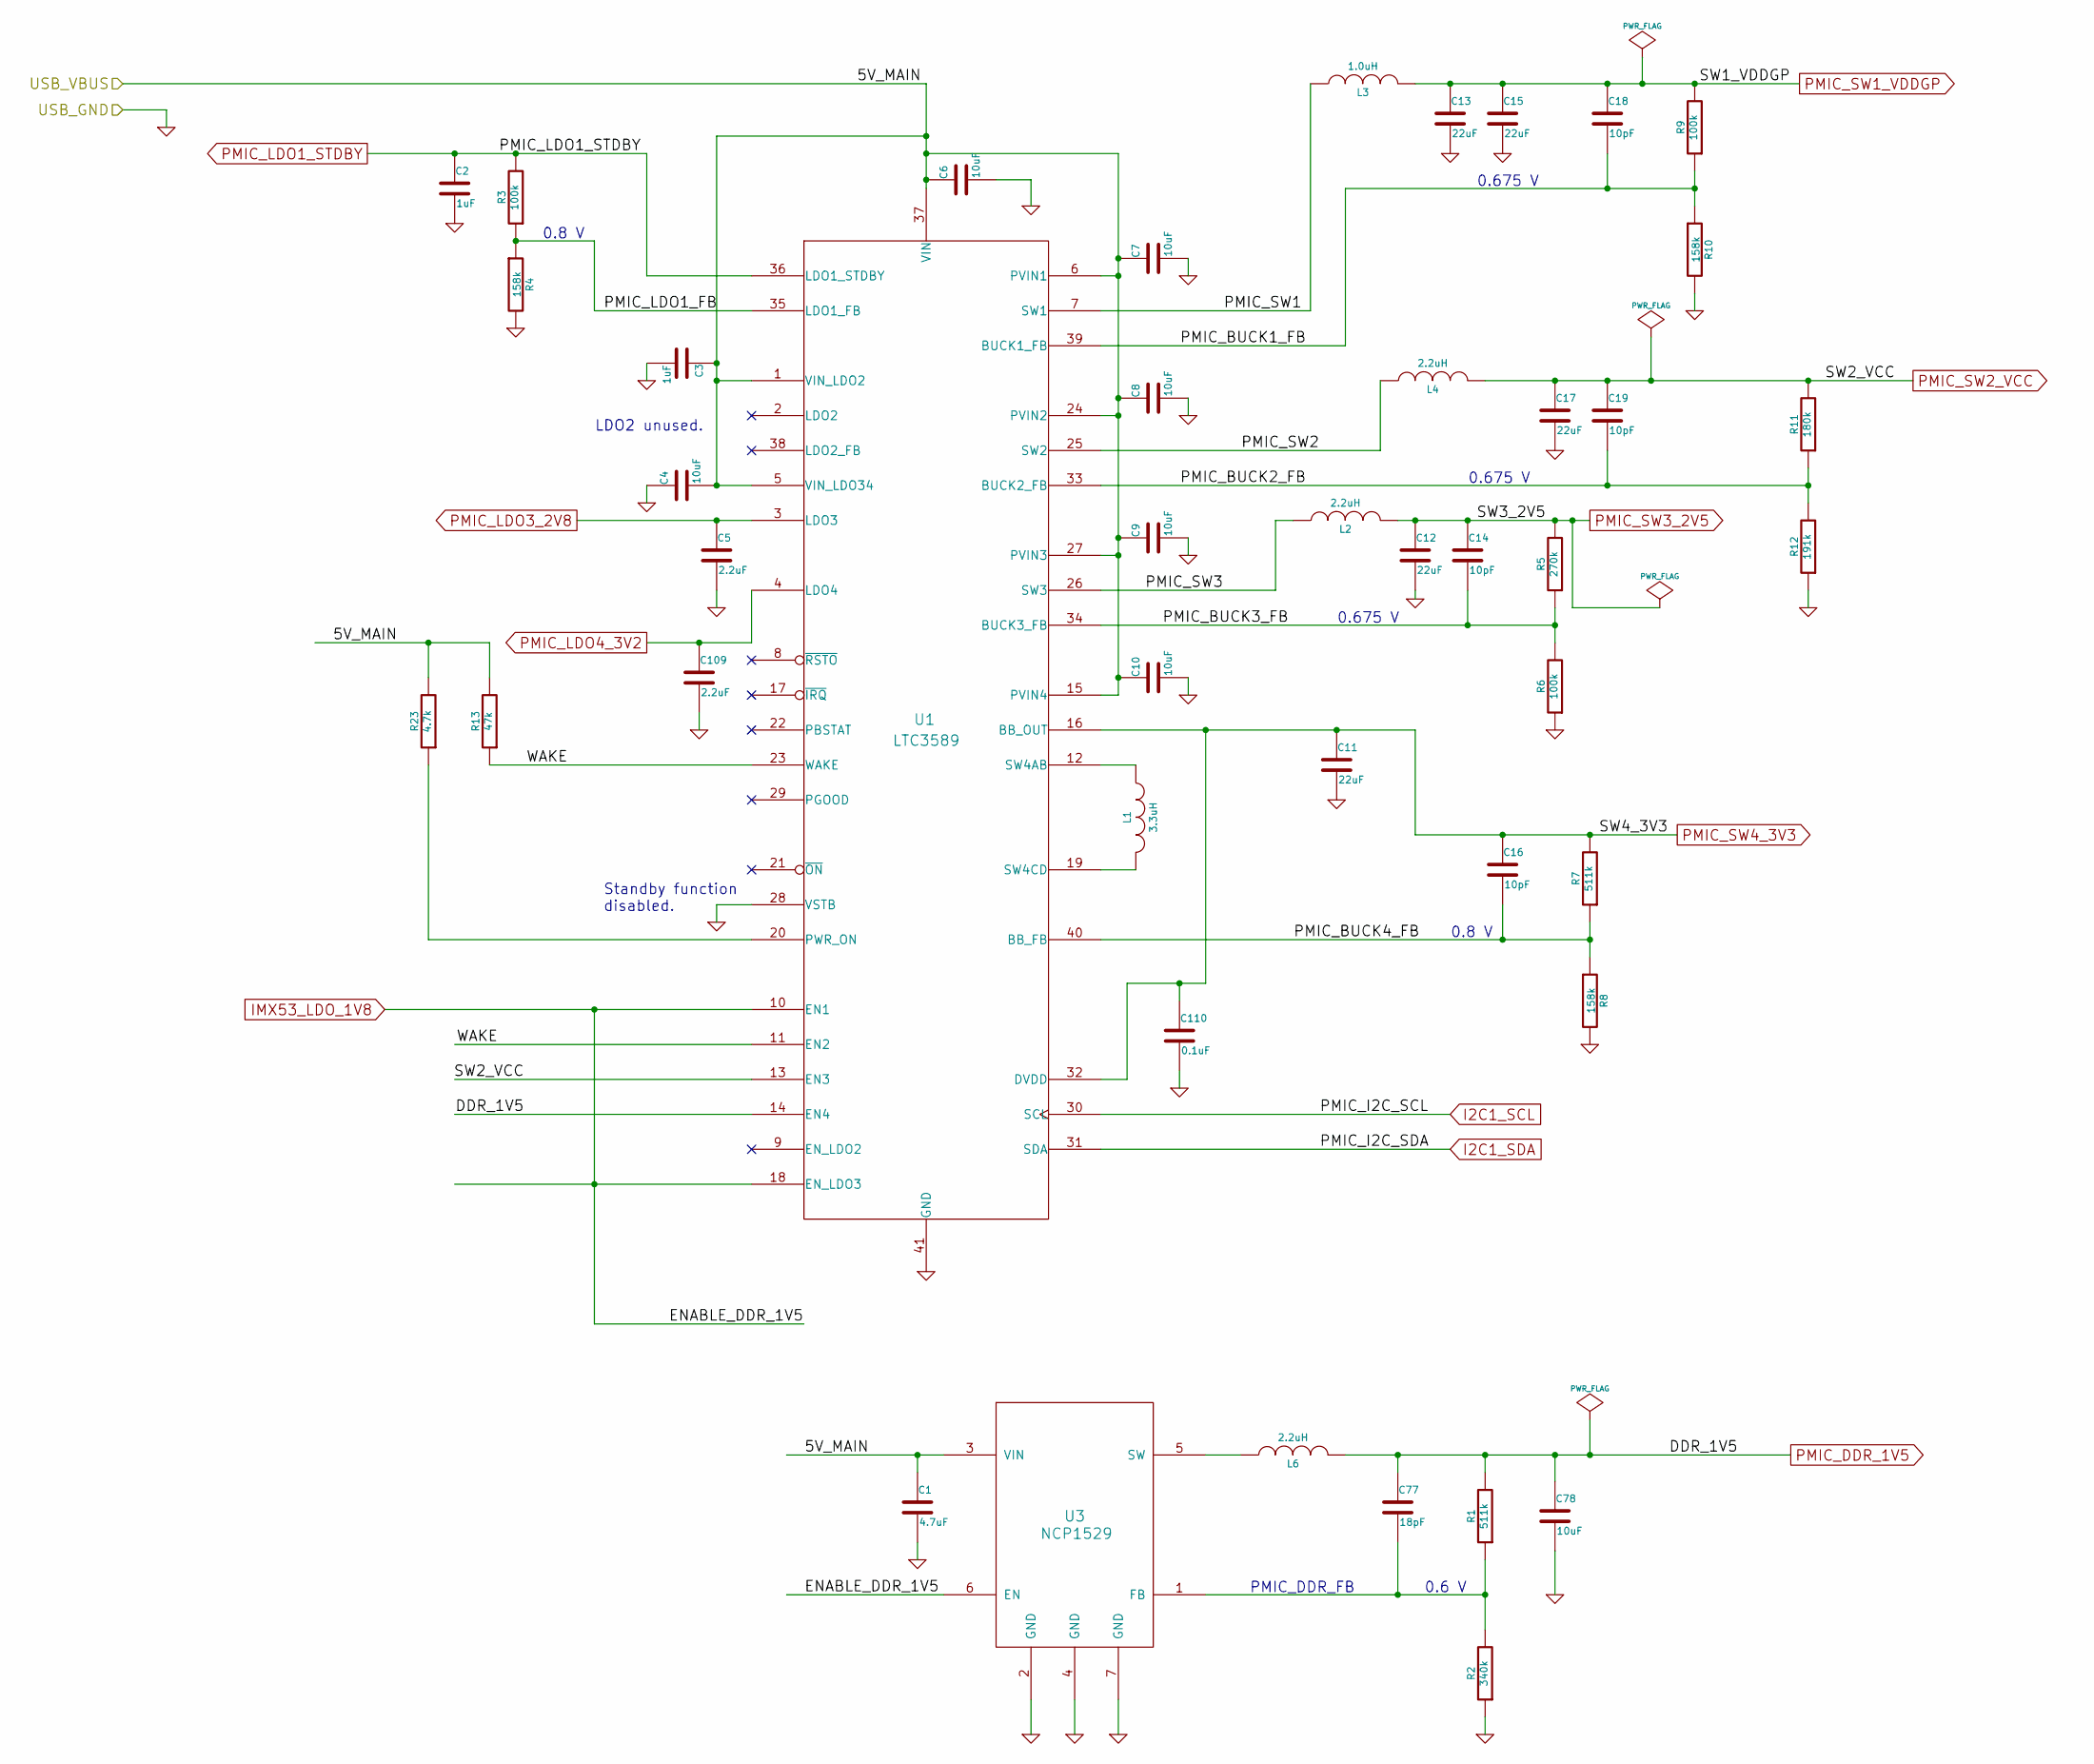
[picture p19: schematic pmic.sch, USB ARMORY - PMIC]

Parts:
C1: 4.7uF; SM0603; Mfg PN CGB3B1X5R1A475K055AC
C2, C3: 1uF; SM0201; Mfg PN C0603X5R0J105M030BC
C4, C6, C7, C8, C9, C10, C78: 10uF; SM0603; Mfg PN C1608X5R1A106K080AC
C5, C109: 2.2uF; SM0402; Mfg PN C1005X5R0J225K050BC
C11, C12, C13, C15, C17: 22uF; SM0603; Mfg PN C1608X5R0J226M080AC
C14, C16, C18, C19: 10pF; SM0402; Mfg PN 04025U100JAT2A
C77: 18pF; SM0201; Mfg PN C0603C0G1H180J030BA
C110: 0.1uF; SM0201; Mfg PN C0603X5R0J104K030BC
L1: 3.3uH; VLS252012ET; Mfg PN VLS252012ET-3R3M
L2, L4, L6: 2.2uH; VLS252012ET; Mfg PN VLS252012ET-2R2M
L3: 1.0uH; VLS252012ET; Mfg PN VLS252012ET-1R0N
R1, R7: 511k; SM0201; Mfg PN CRCW0201511KFNED
R2: 340k; SM0201; Mfg PN CRCW0201340KFNED
R3, R6, R9: 100k; SM0201; Mfg PN CRCW0201100KFNED
R4, R8, R10: 158k; SM0201; Mfg PN CRCW0201158KFNED
R5: 270k; SM0201; Mfg PN CRCW0201270KFNED
R11: 180k; SM0201; Mfg PN CRCW0201180KFNED
R12: 191k; SM0201; Mfg PN CRCW0201191KFNED
R13: 47k; SM0201; Mfg PN CRCW020147K0FNED
R23: 4.7k; SM0201; Mfg PN CRCW02014K70FNED
U1: LTC3589; ltc3589-QFN40; Mfg PN LTC3589EUJ-2#PBF
U3: NCP1529; Mfg PN NCP1529MUTBG

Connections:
/Interfaces/USB_VBUS: C1.1, C3.1, C4.2, C6.1, C7.1, C8.1, C9.1, C10.1, R13.2, R23.2, U1.1 (VIN_LDO2), U1.5 (VIN_LDO34), U1.6 (PVIN1), U1.15 (PVIN4), U1.24 (PVIN2), U1.27 (PVIN3), U1.37 (VIN), U3.3 (VIN); also elsewhere on the board
/PMIC/PMIC_BUCK1_FB: C18.2, R9.1, R10.1, U1.39 (BUCK1_FB)
/PMIC/PMIC_BUCK2_FB: C19.2, R11.1, R12.2, U1.33 (BUCK2_FB)
/PMIC/PMIC_BUCK3_FB: C14.2, R5.1, R6.2, U1.34 (BUCK3_FB)
/PMIC/PMIC_BUCK4_FB: C16.2, R7.1, R8.1, U1.40 (BB_FB)
/PMIC/PMIC_LDO1_FB: R3.1, R4.1, U1.35 (LDO1_FB)
/PMIC/PMIC_SW1: L3.1, U1.7 (SW1)
/PMIC/PMIC_SW2: L4.1, U1.25 (SW2)
/PMIC/PMIC_SW3: L2.1, U1.26 (SW3)
/PMIC/WAKE: R13.1, U1.11 (EN2), U1.23 (WAKE)
GND: C1.2, C2.2, C3.2, C4.1, C5.2, C6.2, C7.2, C8.2, C9.2, C10.2, C11.2, C12.2, C13.2, C15.2, C17.2, C78.2, C109.2, C110.2, R2.1, R4.2, R6.1, R8.2, R10.2, R12.1, U1.28 (VSTB), U1.41 (GND), U3.2 (GND), U3.4 (GND), U3.7 (GND); also elsewhere on the board
I2C1_SCL: U1.30 (SCL); also elsewhere on the board
I2C1_SDA: U1.31 (SDA); also elsewhere on the board
IMX53_LDO_1V8: U1.10 (EN1), U1.18 (EN_LDO3), U3.6 (EN); also elsewhere on the board
unnamed: C77.2, R1.1, R2.2, U3.1 (FB)
unnamed: L1.1, U1.12 (SW4AB)
unnamed: L1.2, U1.19 (SW4CD)
unnamed: L6.1, U3.5 (SW)
unnamed: R23.1, U1.20 (PWR_ON)
PMIC_DDR_1V5: C77.1, C78.1, L6.2, R1.2, U1.14 (EN4); also elsewhere on the board
PMIC_LDO1_STDBY: C2.1, R3.2, U1.36 (LDO1_STDBY); also elsewhere on the board
PMIC_LDO3_2V8: C5.1, U1.3 (LDO3); also elsewhere on the board
PMIC_LDO4_3V2: C109.1, U1.4 (LDO4); also elsewhere on the board
PMIC_SW1_VDDGP: C13.1, C15.1, C18.1, L3.2, R9.2; also elsewhere on the board
PMIC_SW2_VCC: C17.1, C19.1, L4.2, R11.2, U1.13 (EN3); also elsewhere on the board
PMIC_SW3_2V5: C12.1, C14.1, L2.2, R5.2; also elsewhere on the board
PMIC_SW4_3V3: C11.1, C16.1, C110.1, R7.2, U1.16 (BB_OUT), U1.32 (DVDD); also elsewhere on the board

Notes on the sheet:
Standby function disabled.
0.8 V
0.675 V
LDO2 unused.
0.6 V
PMIC_DDR_FB

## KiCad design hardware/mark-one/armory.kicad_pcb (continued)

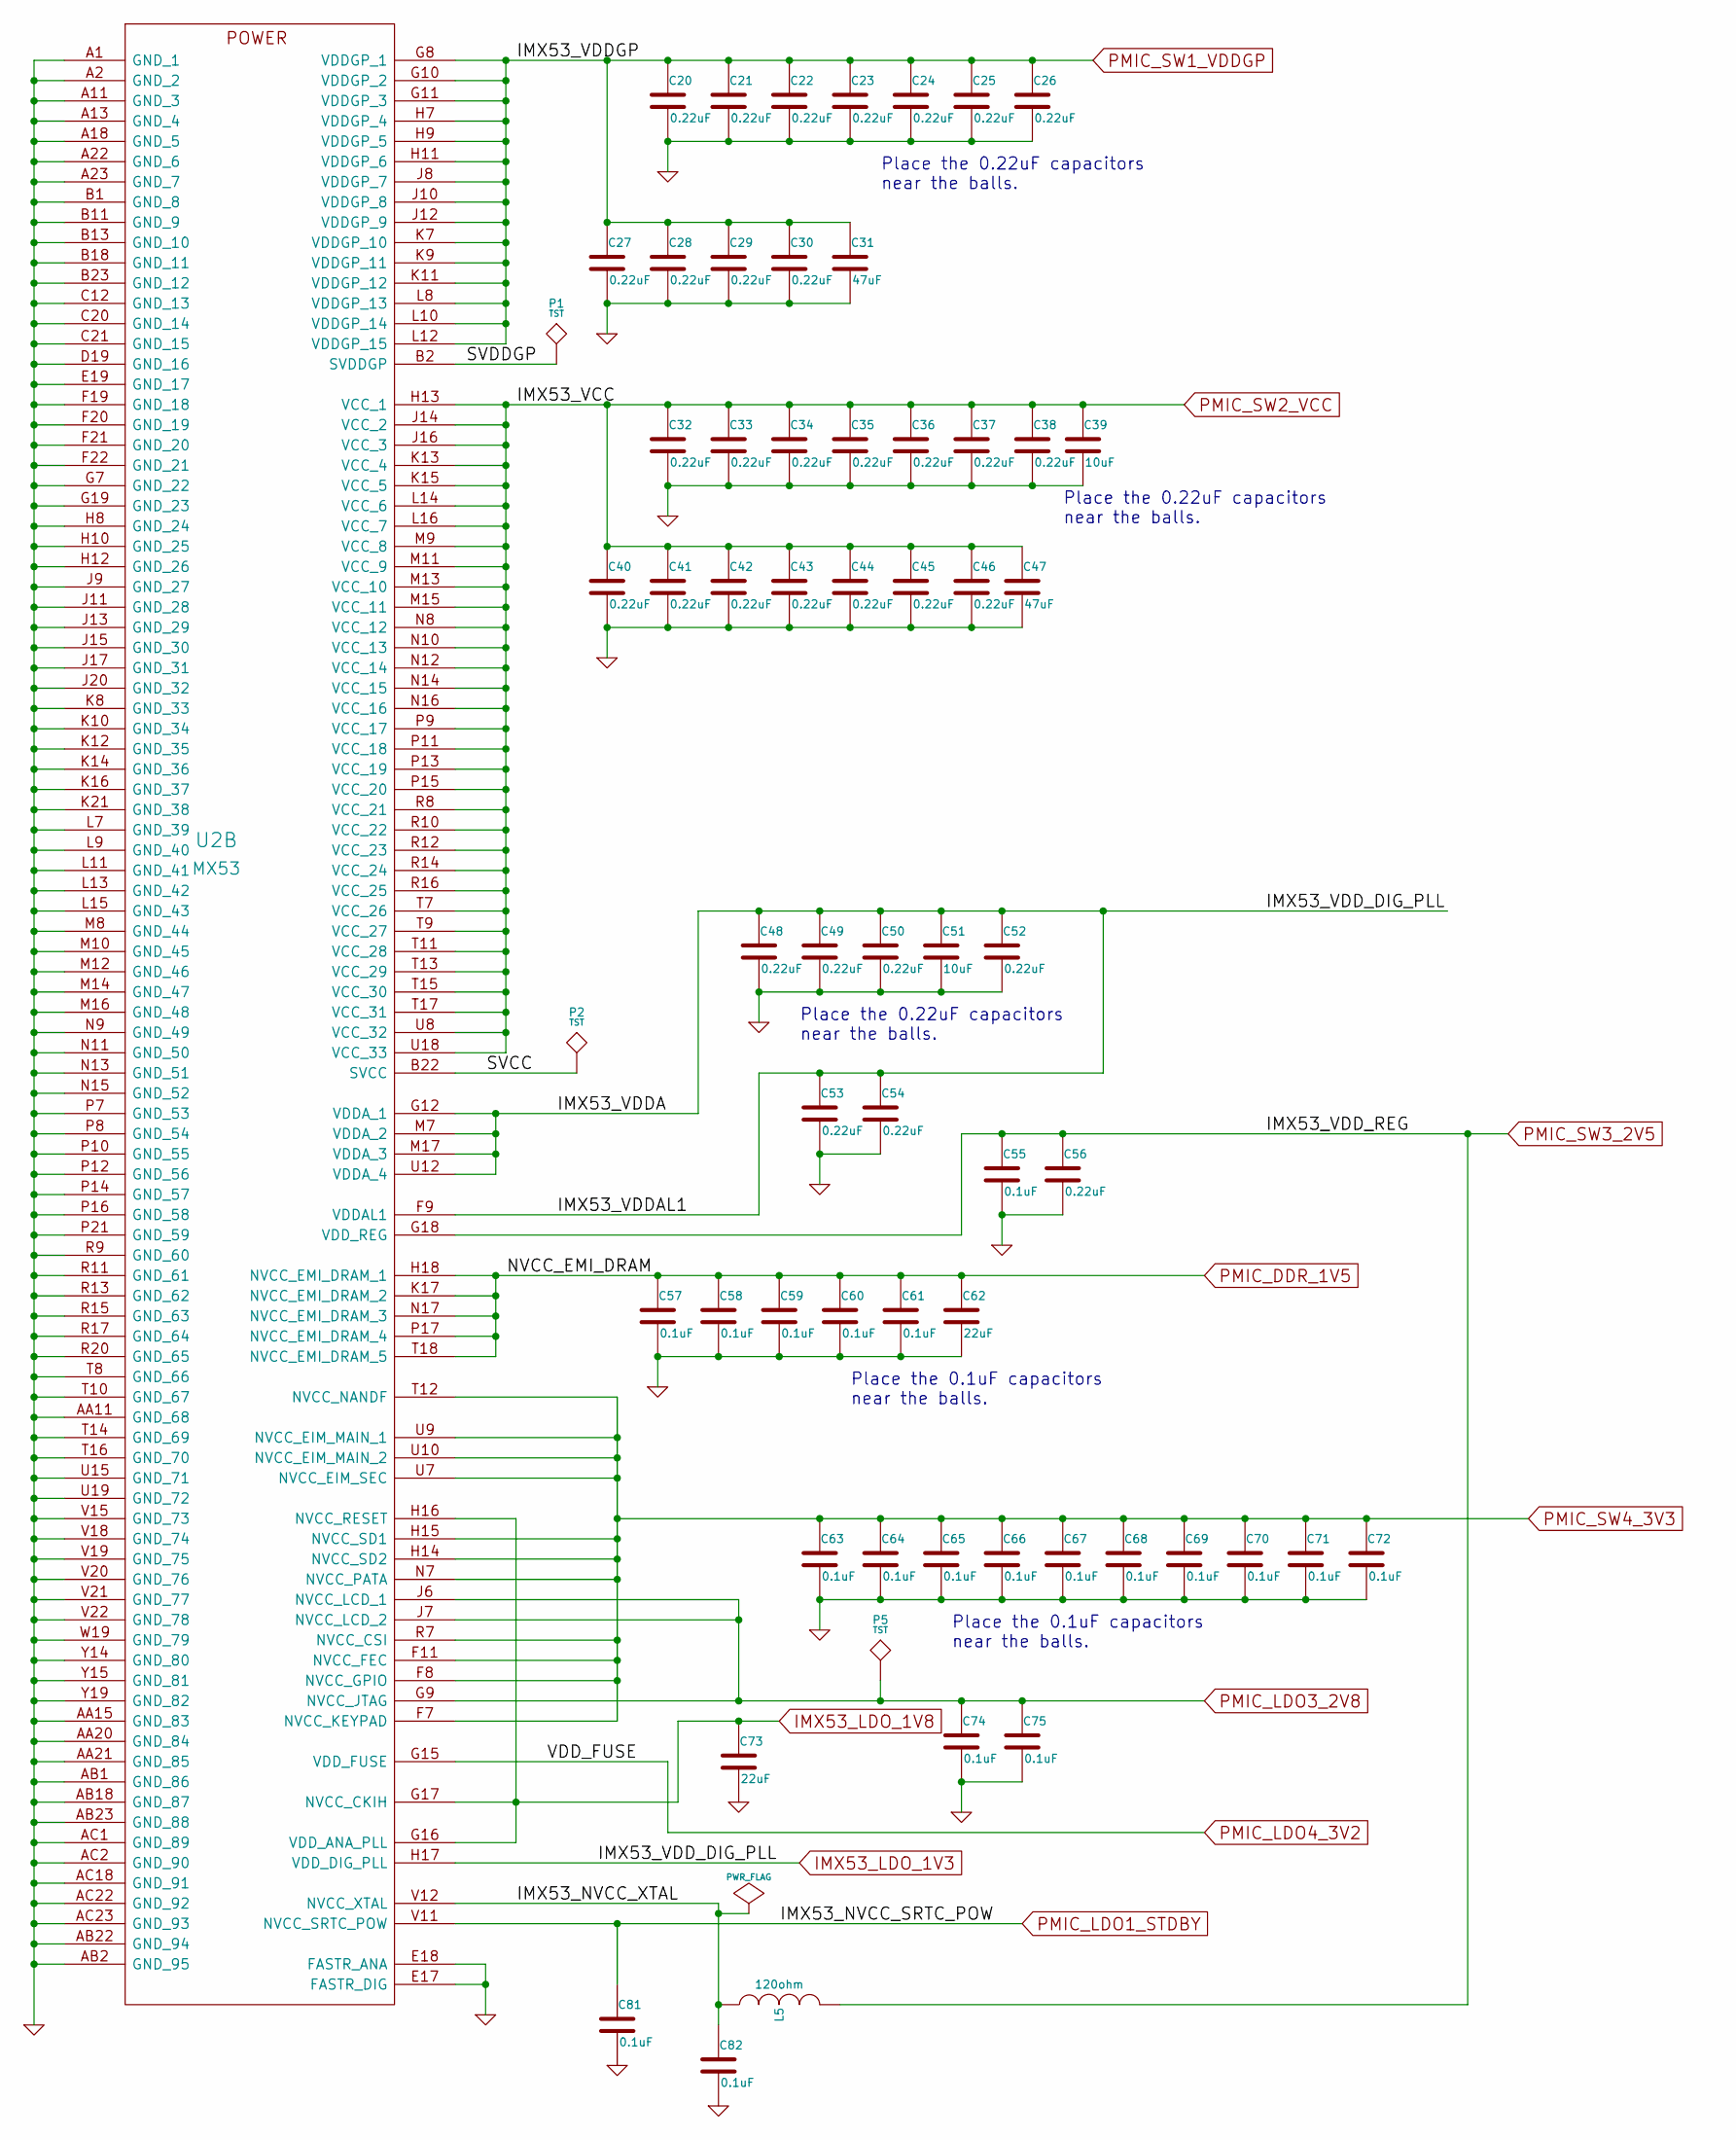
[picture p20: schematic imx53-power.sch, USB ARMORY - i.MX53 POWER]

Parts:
C20, C21, C22, C23, C24, C25, C26, C27, C28, C29, C30, C32, C33, C34, C35, C36, C37, C38, C40, C41, C42, C43, C44, C45, C46, C48, C49, C50, C52, C53, C54, C56: 0.22uF; SM0201; Mfg PN C0603X5R0J224M030BB
C31, C47: 47uF; SM0805; Mfg PN C2012X5R0J476M125AC
C39, C51: 10uF; SM0402; Mfg PN C1005X5R0J106M050BC
C55, C57, C58, C59, C60, C61, C63, C64, C65, C66, C67, C68, C69, C70, C71, C72, C74, C75, C81, C82: 0.1uF; SM0201; Mfg PN C0603X5R0J104K030BC
C62, C73: 22uF; SM0603; Mfg PN C1608X5R0J226M080AC
L5: 120ohm; SM0201; Mfg PN 742692003
P1, P2, P5: TST; TP
U2: MX53; Mfg PN MCIMX537CVV8C / MCIMX536AVV8C / MCIMX53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

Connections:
/i.MX53 POWER/IMX53_NVCC_XTAL: C82.1, L5.1, U2.V12 (NVCC_XTAL)
/i.MX53 POWER/SVCC: P2.1, U2.B22 (SVCC)
/i.MX53 POWER/SVDDGP: P1.1, U2.B2 (SVDDGP)
GND: C20.2, C21.2, C22.2, C23.2, C24.2, C25.2, C26.2, C27.2, C28.2, C29.2, C30.2, C31.2, C32.2, C33.2, C34.2, C35.2, C36.2, C37.2, C38.2, C39.2, C40.2, C41.2, C42.2, C43.2, C44.2, C45.2, C46.2, C47.2, C48.2, C49.2, C50.2, C51.2, C52.2, C53.2, C54.2, C55.2, C56.2, C57.2, C58.2, C59.2, C60.2, C61.2, C62.2, C63.2, C64.2, C65.2, C66.2, C67.2, C68.2, C69.2, C70.2, C71.2, C72.2, C73.2, C74.2, C75.2, C81.2, C82.2, U2.A1 (GND_1), U2.A2 (GND_2), U2.A11 (GND_3), U2.A13 (GND_4), U2.A18 (GND_5), U2.A22 (GND_6), U2.A23 (GND_7), U2.AA11 (GND_68), U2.AA15 (GND_83), U2.AA20 (GND_84), U2.AA21 (GND_85), U2.AB1 (GND_86), U2.AB2 (GND_95), U2.AB18 (GND_87), U2.AB22 (GND_94), U2.AB23 (GND_88), U2.AC1 (GND_89), U2.AC2 (GND_90), U2.AC18 (GND_91), U2.AC22 (GND_92), U2.AC23 (GND_93), U2.B1 (GND_8), U2.B11 (GND_9), U2.B13 (GND_10), U2.B18 (GND_11), U2.B23 (GND_12), U2.C12 (GND_13), U2.C20 (GND_14), U2.C21 (GND_15), U2.D19 (GND_16), U2.E17 (FASTR_DIG), U2.E18 (FASTR_ANA), U2.E19 (GND_17), U2.F19 (GND_18), U2.F20 (GND_19), U2.F21 (GND_20), U2.F22 (GND_21), U2.G7 (GND_22), U2.G19 (GND_23), U2.H8 (GND_24), U2.H10 (GND_25), U2.H12 (GND_26), U2.J9 (GND_27), U2.J11 (GND_28), U2.J13 (GND_29), U2.J15 (GND_30), U2.J17 (GND_31), U2.J20 (GND_32), U2.K8 (GND_33), U2.K10 (GND_34), U2.K12 (GND_35), U2.K14 (GND_36), U2.K16 (GND_37), U2.K21 (GND_38), U2.L7 (GND_39), U2.L9 (GND_40), U2.L11 (GND_41), U2.L13 (GND_42), U2.L15 (GND_43), U2.M8 (GND_44), U2.M10 (GND_45), U2.M12 (GND_46), U2.M14 (GND_47), U2.M16 (GND_48), U2.N9 (GND_49), U2.N11 (GND_50), U2.N13 (GND_51), U2.N15 (GND_52), U2.P7 (GND_53), U2.P8 (GND_54), U2.P10 (GND_55), U2.P12 (GND_56), U2.P14 (GND_57), U2.P16 (GND_58), U2.P21 (GND_59), U2.R9 (GND_60), U2.R11 (GND_61), U2.R13 (GND_62), U2.R15 (GND_63), U2.R17 (GND_64), U2.R20 (GND_65), U2.T8 (GND_66), U2.T10 (GND_67), U2.T14 (GND_69), U2.T16 (GND_70), U2.U15 (GND_71), U2.U19 (GND_72), U2.V15 (GND_73), U2.V18 (GND_74), U2.V19 (GND_75), U2.V20 (GND_76), U2.V21 (GND_77), U2.V22 (GND_78), U2.W19 (GND_79), U2.Y14 (GND_80), U2.Y15 (GND_81), U2.Y19 (GND_82); also elsewhere on the board
IMX53_LDO_1V3: C48.1, C49.1, C50.1, C51.1, C52.1, C53.1, C54.1, U2.F9 (VDDAL1), U2.G12 (VDDA_1), U2.H17 (VDD_DIG_PLL), U2.M7 (VDDA_2), U2.M17 (VDDA_3), U2.U12 (VDDA_4)
IMX53_LDO_1V8: C73.1, U2.G16 (VDD_ANA_PLL), U2.G17 (NVCC_CKIH), U2.H16 (NVCC_RESET); also elsewhere on the board
PMIC_DDR_1V5: C57.1, C58.1, C59.1, C60.1, C61.1, C62.1, U2.H18 (NVCC_EMI_DRAM_1), U2.K17 (NVCC_EMI_DRAM_2), U2.N17 (NVCC_EMI_DRAM_3), U2.P17 (NVCC_EMI_DRAM_4), U2.T18 (NVCC_EMI_DRAM_5); also elsewhere on the board
PMIC_LDO1_STDBY: C81.1, U2.V11 (NVCC_SRTC_POW); also elsewhere on the board
PMIC_LDO3_2V8: C74.1, C75.1, P5.1, U2.G9 (NVCC_JTAG), U2.J6 (NVCC_LCD_1), U2.J7 (NVCC_LCD_2); also elsewhere on the board
PMIC_LDO4_3V2: U2.G15 (VDD_FUSE); also elsewhere on the board
PMIC_SW1_VDDGP: C20.1, C21.1, C22.1, C23.1, C24.1, C25.1, C26.1, C27.1, C28.1, C29.1, C30.1, C31.1, U2.G8 (VDDGP_1), U2.G10 (VDDGP_2), U2.G11 (VDDGP_3), U2.H7 (VDDGP_4), U2.H9 (VDDGP_5), U2.H11 (VDDGP_6), U2.J8 (VDDGP_7), U2.J10 (VDDGP_8), U2.J12 (VDDGP_9), U2.K7 (VDDGP_10), U2.K9 (VDDGP_11), U2.K11 (VDDGP_12), U2.L8 (VDDGP_13), U2.L10 (VDDGP_14), U2.L12 (VDDGP_15); also elsewhere on the board
PMIC_SW2_VCC: C32.1, C33.1, C34.1, C35.1, C36.1, C37.1, C38.1, C39.1, C40.1, C41.1, C42.1, C43.1, C44.1, C45.1, C46.1, C47.1, U2.H13 (VCC_1), U2.J14 (VCC_2), U2.J16 (VCC_3), U2.K13 (VCC_4), U2.K15 (VCC_5), U2.L14 (VCC_6), U2.L16 (VCC_7), U2.M9 (VCC_8), U2.M11 (VCC_9), U2.M13 (VCC_10), U2.M15 (VCC_11), U2.N8 (VCC_12), U2.N10 (VCC_13), U2.N12 (VCC_14), U2.N14 (VCC_15), U2.N16 (VCC_16), U2.P9 (VCC_17), U2.P11 (VCC_18), U2.P13 (VCC_19), U2.P15 (VCC_20), U2.R8 (VCC_21), U2.R10 (VCC_22), U2.R12 (VCC_23), U2.R14 (VCC_24), U2.R16 (VCC_25), U2.T7 (VCC_26), U2.T9 (VCC_27), U2.T11 (VCC_28), U2.T13 (VCC_29), U2.T15 (VCC_30), U2.T17 (VCC_31), U2.U8 (VCC_32), U2.U18 (VCC_33); also elsewhere on the board
PMIC_SW3_2V5: C55.1, C56.1, L5.2, U2.G18 (VDD_REG); also elsewhere on the board
PMIC_SW4_3V3: C63.1, C64.1, C65.1, C66.1, C67.1, C68.1, C69.1, C70.1, C71.1, C72.1, U2.F7 (NVCC_KEYPAD), U2.F8 (NVCC_GPIO), U2.F11 (NVCC_FEC), U2.H14 (NVCC_SD2), U2.H15 (NVCC_SD1), U2.N7 (NVCC_PATA), U2.R7 (NVCC_CSI), U2.T12 (NVCC_NANDF), U2.U7 (NVCC_EIM_SEC), U2.U9 (NVCC_EIM_MAIN_1), U2.U10 (NVCC_EIM_MAIN_2); also elsewhere on the board

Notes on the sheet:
Place the 0.22uF capacitors near the balls.
Place the 0.1uF capacitors near the balls.

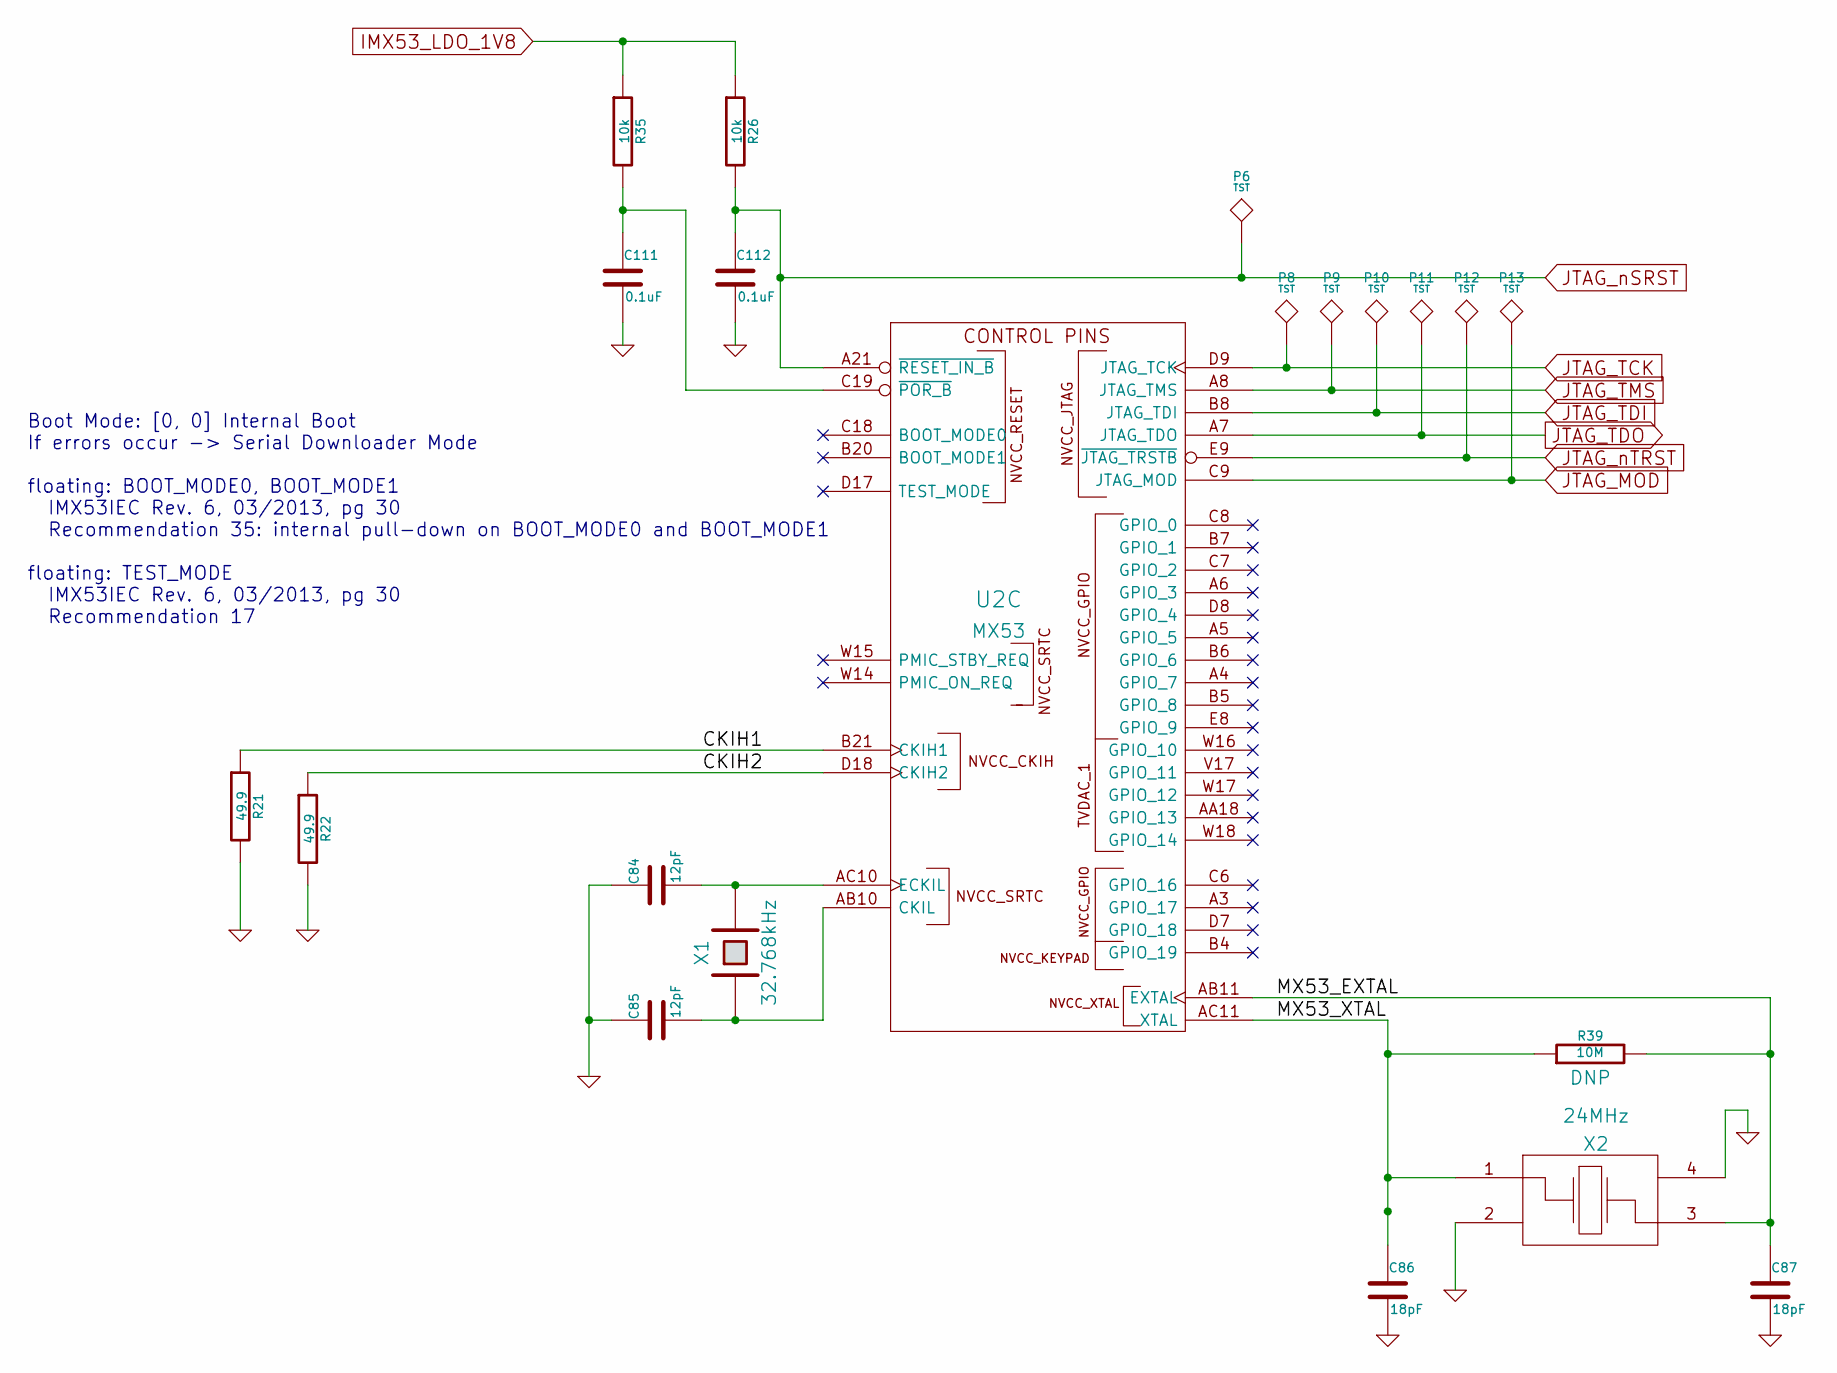
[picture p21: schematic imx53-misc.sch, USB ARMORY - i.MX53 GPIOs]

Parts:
C84, C85: 12pF; SM0201; Mfg PN C0603C0G1E120J030BA
C86, C87: 18pF; SM0201; Mfg PN C0603C0G1H180J030BA
C111, C112: 0.1uF; SM0201; Mfg PN C0603X5R0J104K030BC
P6, P8, P9, P10, P11, P12, P13: TST; TP
R21, R22: 49.9; SM0201; Mfg PN CRCW020149R9FNED
R26, R35: 10k; SM0201; Mfg PN CRCW020110K0FNED
R39: 10M; SM0201; Mfg PN CRCW020110M0FNED
U2: MX53
X1: 32.768kHz; CRYSTAL-32k-B; Mfg PN ABS07-32.768KHZ-9-T
X2: 24MHz; CRYSTAL-24M-B; Mfg PN 7M-24.000MEEQ-T

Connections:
/i.MX53 MISC/CKIH1: R21.1, U2.B21 (CKIH1)
/i.MX53 MISC/CKIH2: R22.1, U2.D18 (CKIH2)
/i.MX53 MISC/MX53_EXTAL: C87.1, R39.2, U2.AB11 (EXTAL), X2.3
/i.MX53 MISC/MX53_XTAL: C86.1, R39.1, U2.AC11 (XTAL), X2.1
GND: C84.1, C85.1, C86.2, C87.2, C111.2, C112.2, R21.2, R22.2, X2.2, X2.4; also elsewhere on the board
IMX53_LDO_1V8: R26.1, R35.1; also elsewhere on the board
JTAG_MOD: P13.1, U2.C9 (JTAG_MOD)
JTAG_TCK: P8.1, U2.D9 (JTAG_TCK)
JTAG_TDI: P10.1, U2.B8 (JTAG_TDI)
JTAG_TDO: P11.1, U2.A7 (JTAG_TDO)
JTAG_TMS: P9.1, U2.A8 (JTAG_TMS)
JTAG_nSRST: C112.1, P6.1, R26.2, U2.A21 (~RESET_IN_B)
JTAG_nTRST: P12.1, U2.E9 (~JTAG_TRSTB)
unnamed: C84.2, U2.AC10 (ECKIL), X1.2
unnamed: C85.2, U2.AB10 (CKIL), X1.1
unnamed: C111.1, R35.2, U2.C19 (~POR_B)

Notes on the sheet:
Boot Mode: [0, 0] Internal Boot If errors occur -> Serial Downloader Mode floating: BOOT_MODE0, BOOT_MODE1 IMX53IEC Rev. 6, 03/2013, pg 30 Recommendation 35: internal pull-down on BOOT_MODE0 and BOOT_MODE1 floating: TEST_MODE IMX53IEC Rev. 6, 03/2013, pg 30 Recommendation 17

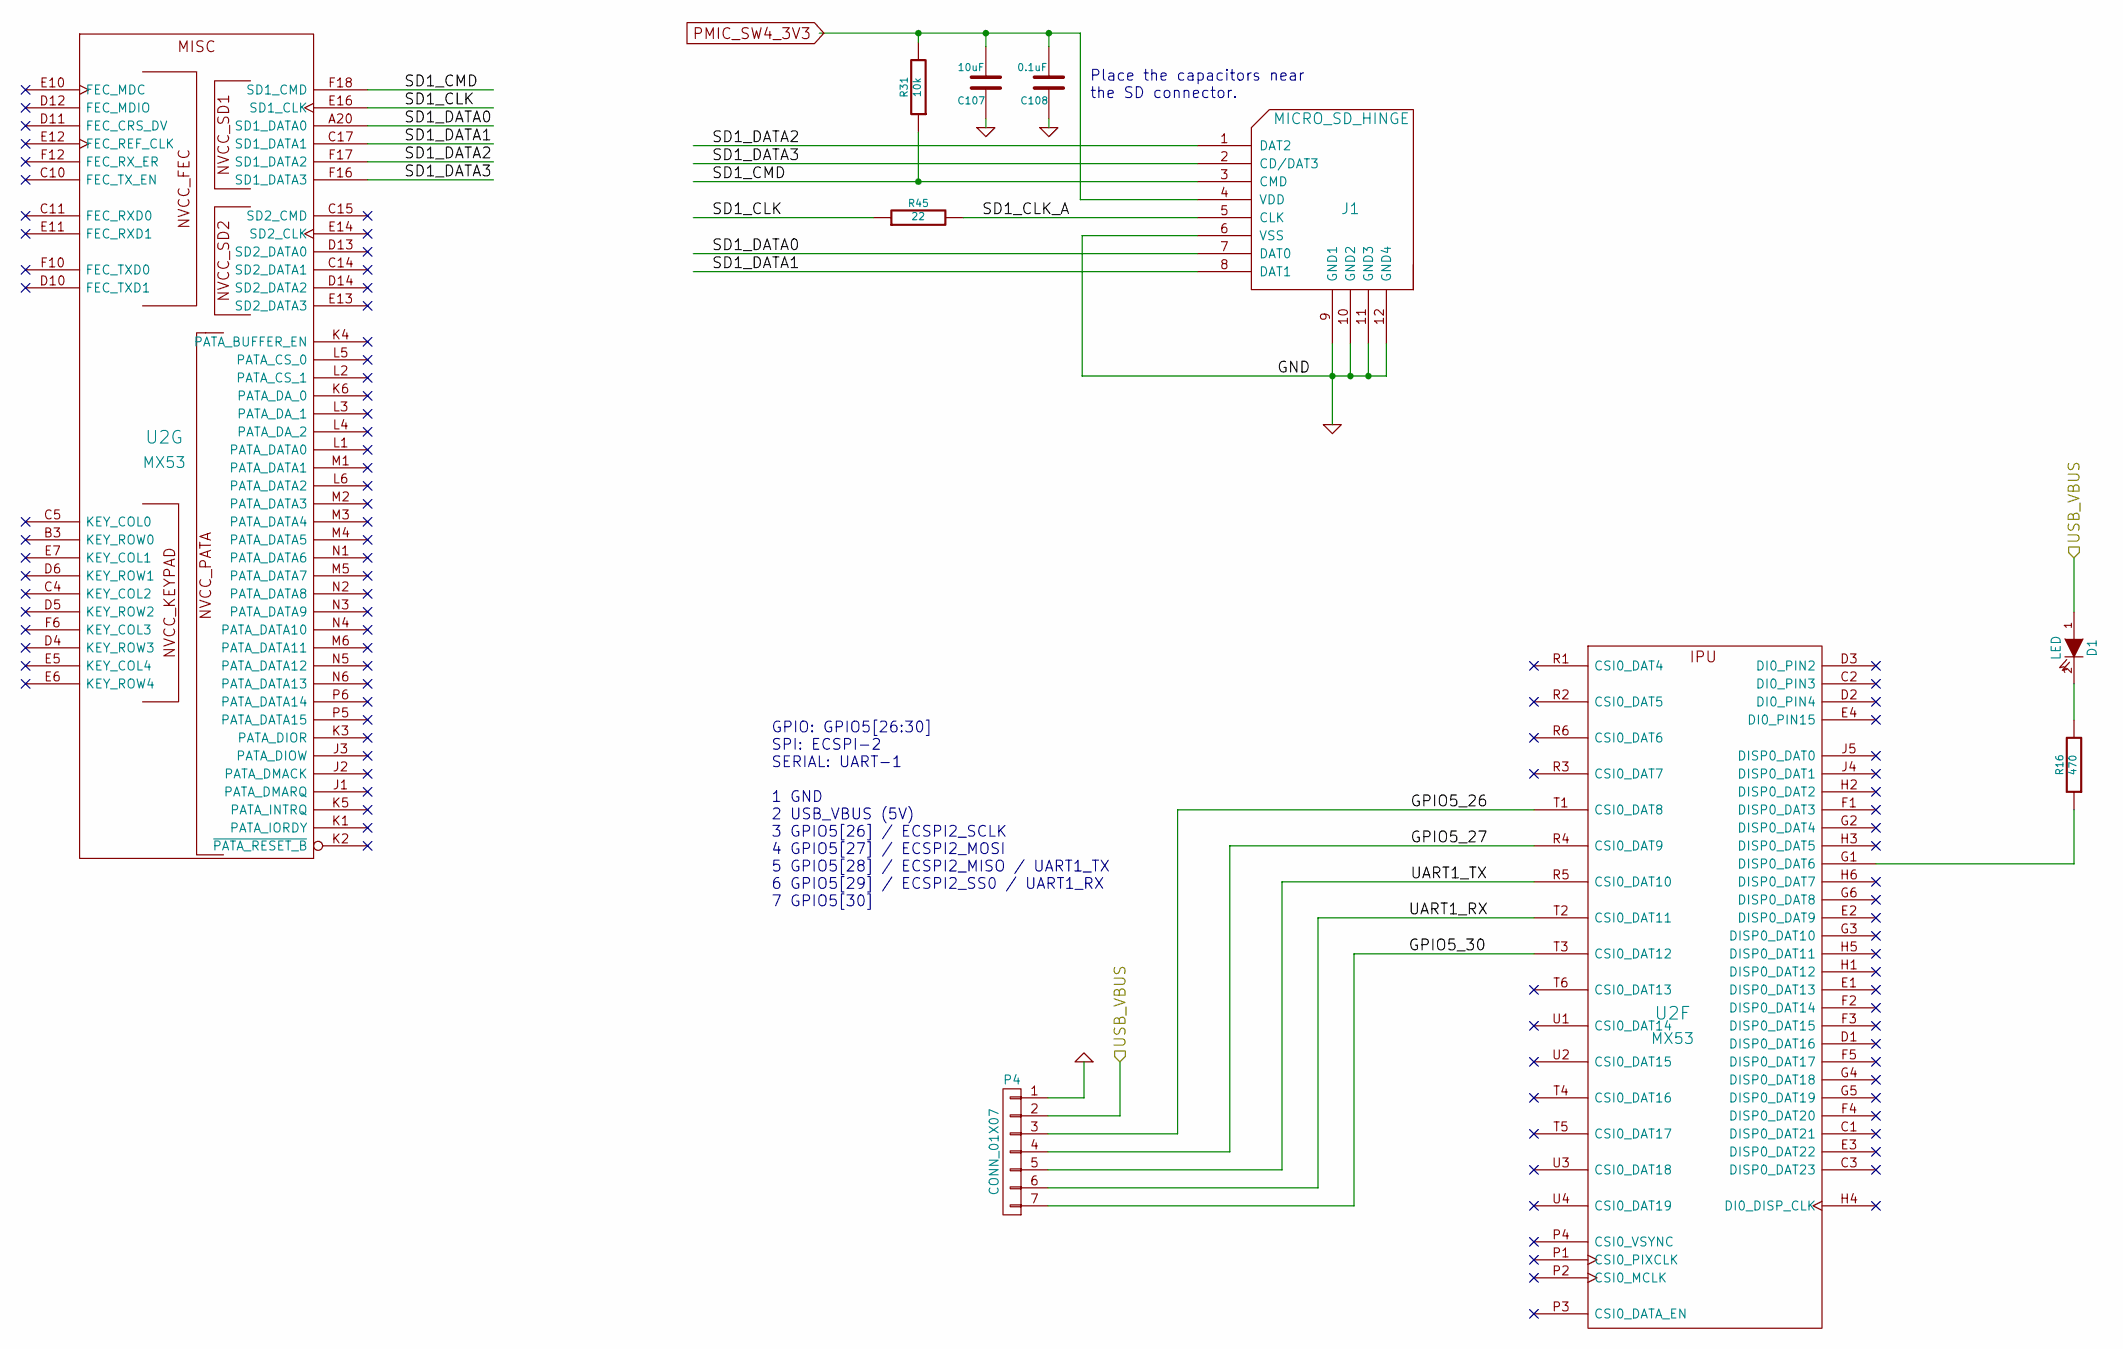
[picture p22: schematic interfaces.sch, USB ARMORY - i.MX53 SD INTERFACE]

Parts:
C107: 10uF; SM0603; Mfg PN C1608X5R1A106K080AC
C108: 0.1uF; SM0201; Mfg PN C0603X5R0J104K030BC
D1: LED; SM0603LED; Mfg PN VLMW1300-GS08
J1: MICRO_SD_HINGE; MICRO_SD_HINGE_AMP; Mfg PN 101-00303-68
P4: CONN_01X07; pinhead-1X7
R16: 470; SM0201; Mfg PN CRCW0201470RFNED
R31: 10k; SM0201; Mfg PN CRCW020110K0FNED
R45: 22; SM0201; Mfg PN CRCW020122R0FNED
U2: MX53

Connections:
/Interfaces/GPIO5_26: P4.3, U2.T1 (CSI0_DAT8)
/Interfaces/GPIO5_27: P4.4, U2.R4 (CSI0_DAT9)
/Interfaces/GPIO5_30: P4.7, U2.T3 (CSI0_DAT12)
/Interfaces/SD1_CLK: R45.1, U2.E16 (SD1_CLK)
/Interfaces/SD1_CLK_A: J1.5 (CLK), R45.2
/Interfaces/SD1_CMD: J1.3 (CMD), R31.1, U2.F18 (SD1_CMD)
/Interfaces/SD1_DATA0: J1.7 (DAT0), U2.A20 (SD1_DATA0)
/Interfaces/SD1_DATA1: J1.8 (DAT1), U2.C17 (SD1_DATA1)
/Interfaces/SD1_DATA2: J1.1 (DAT2), U2.F17 (SD1_DATA2)
/Interfaces/SD1_DATA3: J1.2 (CD/DAT3), U2.F16 (SD1_DATA3)
/Interfaces/UART1_RX: P4.6, U2.T2 (CSI0_DAT11)
/Interfaces/UART1_TX: P4.5, U2.R5 (CSI0_DAT10)
/Interfaces/USB_VBUS: D1.1 (A), P4.2; also elsewhere on the board
GND: C107.1, C108.1, J1.6 (VSS), J1.9 (GND1), J1.10 (GND2), J1.11 (GND3), J1.12 (GND4), P4.1; also elsewhere on the board
unnamed: D1.2 (K), R16.2
unnamed: R16.1, U2.G1 (DISP0_DAT6)
PMIC_SW4_3V3: C107.2, C108.2, J1.4 (VDD), R31.2; also elsewhere on the board

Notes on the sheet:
Place the capacitors near the SD connector.
GPIO: GPIO5[26:30] SPI: ECSPI-2 SERIAL: UART-1 1 GND 2 USB_VBUS (5V) 3 GPIO5[26] / ECSPI2_SCLK 4 GPIO5[27] / ECSPI2_MOSI 5 GPIO5[28] / ECSPI2_MISO / UART1_TX 6 GPIO5[29] / ECSPI2_SS0 / UART1_RX 7 GPIO5[30]

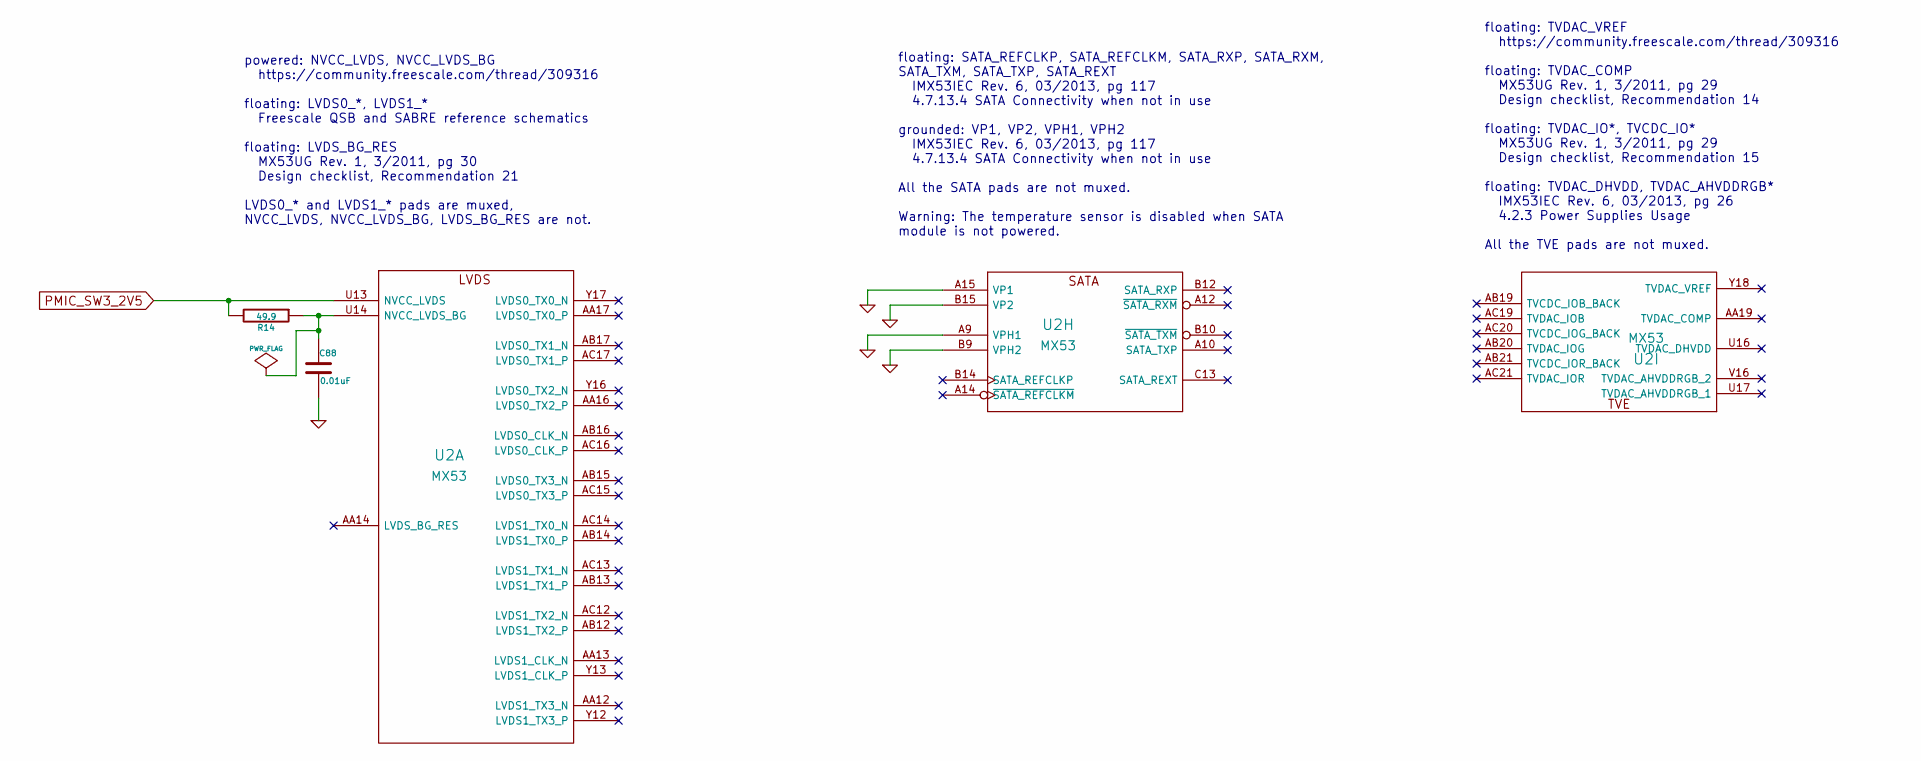
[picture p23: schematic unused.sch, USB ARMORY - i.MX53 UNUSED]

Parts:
C88: 0.01uF; SM0201; Mfg PN C0603X7R1A103K030BA
R14: 49.9; SM0201; Mfg PN CRCW020149R9FNED
U2: MX53

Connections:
GND: C88.2, U2.A9 (VPH1), U2.A15 (VP1), U2.B9 (VPH2), U2.B15 (VP2); also elsewhere on the board
unnamed: C88.1, R14.1, U2.U14 (NVCC_LVDS_BG)
PMIC_SW3_2V5: R14.2, U2.U13 (NVCC_LVDS); also elsewhere on the board

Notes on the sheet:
floating: TVDAC_VREF https://community.freescale.com/thread/309316 floating: TVDAC_COMP MX53UG Rev. 1, 3/2011, pg 29 Design checklist, Recommendation 14 floating: TVDAC_IO*, TVCDC_IO* MX53UG Rev. 1, 3/2011, pg 29 Design checklist, Recommendation 15 floating: TVDAC_DHVDD, TVDAC_AHVDDRGB* IMX53IEC Re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
powered: NVCC_LVDS, NVCC_LVDS_BG https://community.freescale.com/thread/309316 floating: LVDS0_*, LVDS1_* Freescale QSB and SABRE reference schematics floating: LVDS_BG_RES MX53UG Rev. 1, 3/2011, pg 30 Design checklist, Recommendation 21 LVDS0_* and LVDS1_* pads are muxed, NVCC_LVDS, NVCC_LVDS_BG, 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
floating: SATA_REFCLKP, SATA_REFCLKM, SATA_RXP, SATA_RXM, SATA_TXM, SATA_TXP, SATA_REXT IMX53IEC Rev. 6, 03/2013, pg 117 4.7.13.4 SATA Connectivity when not in use grounded: VP1, VP2, VPH1, VPH2 IMX53IEC Rev. 6, 03/2013, pg 117 4.7.13.4 SATA Connectivity when not in use All the SATA pads are not mu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

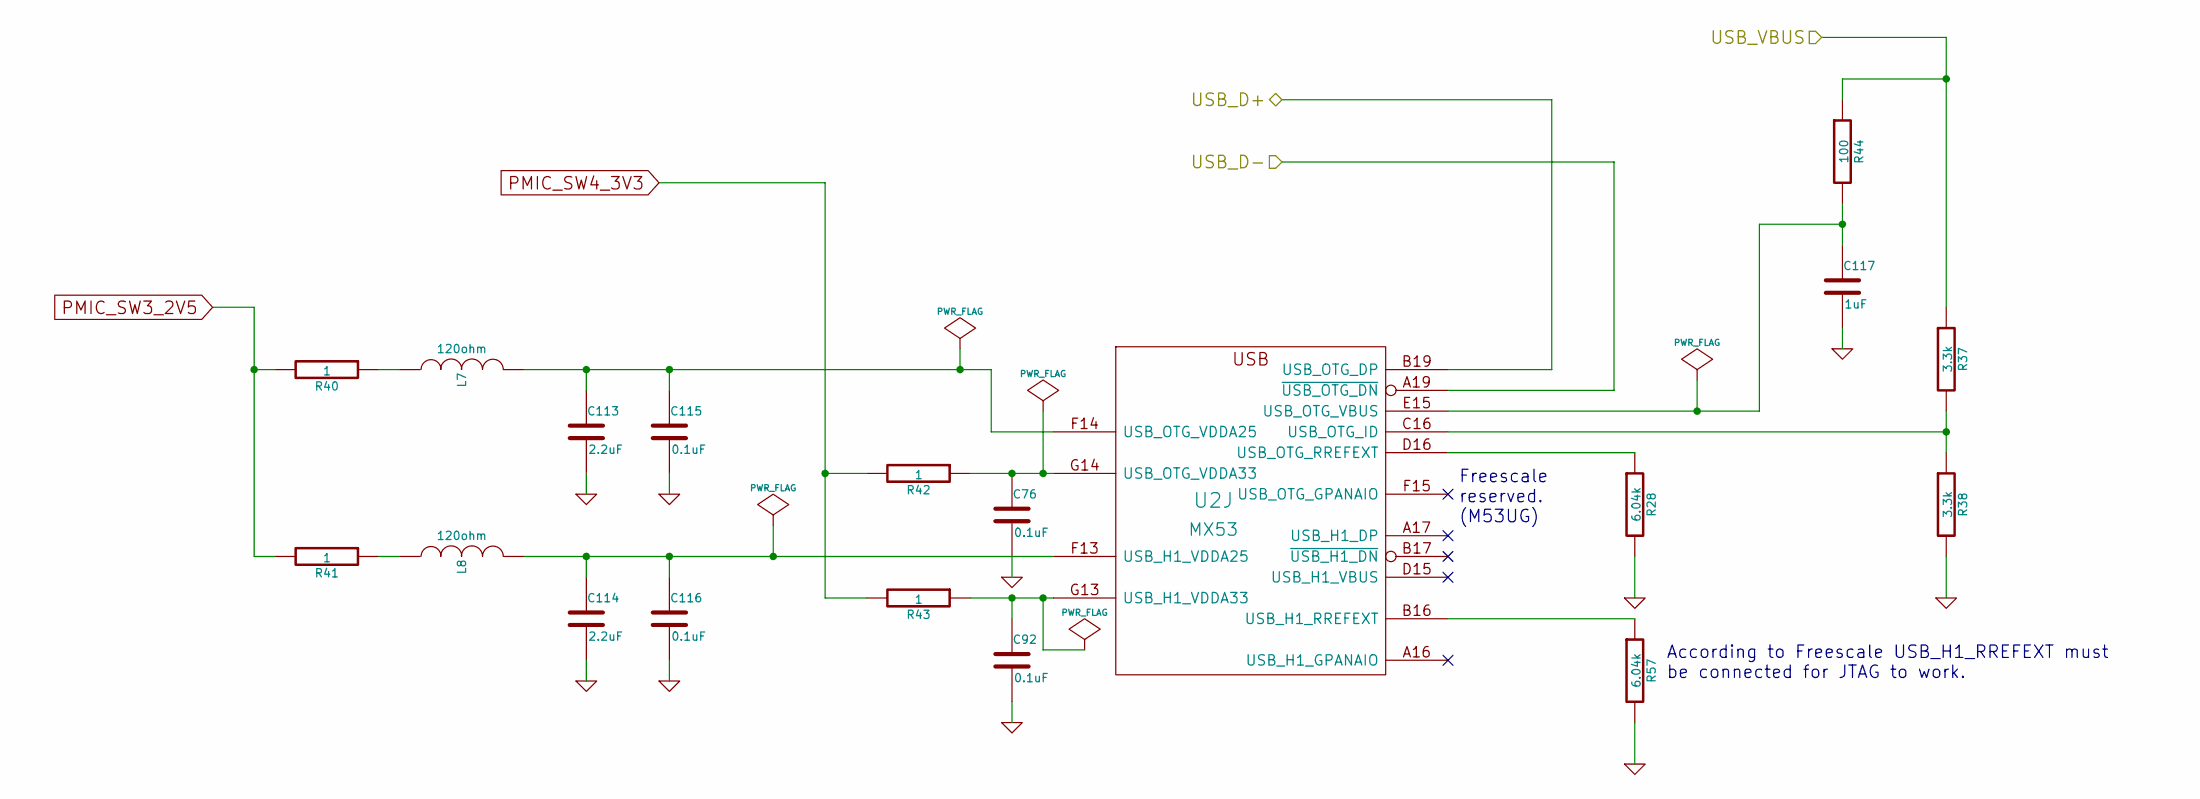
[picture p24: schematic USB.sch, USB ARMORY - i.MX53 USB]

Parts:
C76, C92, C115, C116: 0.1uF; SM0201; Mfg PN C0603X5R0J104K030BC
C113, C114: 2.2uF; SM0402; Mfg PN C1005X5R0J225K050BC
C117: 1uF; SM0201; Mfg PN C0603X5R0J105M030BC
L7, L8: 120ohm; SM0201; Mfg PN 742692003
R28, R57: 6.04k; SM0201; Mfg PN CRCW02016K04FNED
R37, R38: 3.3k; SM0201; Mfg PN CRCW02013K30FNED
R40, R41, R42, R43: 1; SM0201; Mfg PN MCRE000220
R44: 100; SM0201; Mfg PN CRCW0201100RFNED
U2: MX53

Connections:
/Interfaces/USB_VBUS: R37.1, R44.1; also elsewhere on the board
/USB/USB_D+: U2.B19 (USB_OTG_DP); also elsewhere on the board
/USB/USB_D-: U2.A19 (~USB_OTG_DN); also elsewhere on the board
GND: C76.2, C92.2, C113.2, C114.2, C115.2, C116.2, C117.2, R28.2, R38.2, R57.2; also elsewhere on the board
unnamed: C76.1, R42.1, U2.G14 (USB_OTG_VDDA33)
unnamed: C92.1, R43.1, U2.G13 (USB_H1_VDDA33)
unnamed: C113.1, C115.1, L7.2, U2.F14 (USB_OTG_VDDA25)
unnamed: C114.1, C116.1, L8.2, U2.F13 (USB_H1_VDDA25)
unnamed: C117.1, R44.2, U2.E15 (USB_OTG_VBUS)
unnamed: L7.1, R40.1
unnamed: L8.1, R41.1
unnamed: R28.1, U2.D16 (USB_OTG_RREFEXT)
unnamed: R37.2, R38.1, U2.C16 (USB_OTG_ID)
unnamed: R57.1, U2.B16 (USB_H1_RREFEXT)
PMIC_SW3_2V5: R40.2, R41.2; also elsewhere on the board
PMIC_SW4_3V3: R42.2, R43.2; also elsewhere on the board

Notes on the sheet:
Freescale reserved. (M53UG)
According to Freescale USB_H1_RREFEXT must be connected for JTAG to work.


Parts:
R25, R32, R33, R34: 4.7k; SM0201; Mfg PN CRCW02014K70FNED
U2: MX53

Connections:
/Boot/BT_CFG1_6: R25.1, U2.AA4 (EIM_A21)
/Boot/BT_CFG2_5: R32.1, U2.Y8 (EIM_DA0)
GND: U2.AA3 (EIM_A22), U2.AA5 (EIM_A16), U2.AA6 (EIM_LBA), U2.AA7 (EIM_DA2), U2.AA8 (EIM_DA8), U2.AB3 (EIM_A18), U2.AB5 (EIM_EB1), U2.AB6 (EIM_DA4), U2.AB7 (EIM_DA10), U2.AC3 (EIM_EB0), U2.AC4 (EIM_DA1), U2.AC5 (EIM_DA7), U2.V7 (EIM_A17), U2.V9 (EIM_DA5), U2.W7 (EIM_A19), U2.W9 (EIM_DA3), U2.W10 (EIM_DA9), U2.Y6 (EIM_A20), U2.Y9 (EIM_DA6); also elsewhere on the board
I2C1_SCL: R33.1, U2.V3 (EIM_D21); also elsewhere on the board
I2C1_SDA: R34.1, U2.AA1 (EIM_D28); also elsewhere on the board
PMIC_SW4_3V3: R25.2, R32.2, R33.2, R34.2; also elsewhere on the board

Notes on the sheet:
References: - i.MX53 Multimedia Applications Processor Reference Manual, Rev 2.1, 6/2012, pg 479 - i.MX53 Applications Processors for Industrial Products, Rev. 6, pg 142 BOOT_CFG1[7:6] = 01 - Boot from ESDHC interfaces BOOT_CFG1[5] = 0 - SD/eSD BOOT_CFG1[4] = 0 - Fast Boot Support: Normal Boot BOOT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

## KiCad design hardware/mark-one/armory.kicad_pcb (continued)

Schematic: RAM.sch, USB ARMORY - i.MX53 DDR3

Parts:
C89, C90, C91, C93, C94, C96, C97, C98, C100, C101, C102, C104: 0.1uF; SM0201; Mfg PN C0603X5R0J104K030BC
C95, C99, C103: 0.01uF; SM0201; Mfg PN C0603X7R1A103K030BA
C105, C106: 10uF; SM0603; Mfg PN C1608X5R1A106K080AC
P3: TST; TP
R15, R24: 470; SM0201; Mfg PN CRCW0201470RFNED
R27, R29: 240; SM0201; Mfg PN CRCW0201240RFNED
R30: 100; SM0603; Mfg PN CRCW0603100RFKEA
U2: MX53
U4: MT41K256M16HA; micron-96-fbga-ha; Mfg PN MT41K256M16HA-107

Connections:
/RAM/DDR_VREF: C89.1, C90.2, C91.1, C93.1, P3.1, R15.1, R24.2, U2.L17 (DDR_VREF), U4.H1 (VREFDQ), U4.M8 (VREFCA)
/RAM/DDR_ZQ: R29.2, U4.L8 (ZQ)
/RAM/DRAM_A0: U2.M19 (DRAM_A0), U4.N3 (A0)
/RAM/DRAM_A1: U2.L21 (DRAM_A1), U4.P7 (A1)
/RAM/DRAM_A2: U2.M20 (DRAM_A2), U4.P3 (A2)
/RAM/DRAM_A3: U2.N20 (DRAM_A3), U4.N2 (A3)
/RAM/DRAM_A4: U2.K20 (DRAM_A4), U4.P8 (A4)
/RAM/DRAM_A5: U2.N21 (DRAM_A5), U4.P2 (A5)
/RAM/DRAM_A6: U2.M22 (DRAM_A6), U4.R8 (A6)
/RAM/DRAM_A7: U2.N22 (DRAM_A7), U4.R2 (A7)
/RAM/DRAM_A8: U2.N23 (DRAM_A8), U4.T8 (A8)
/RAM/DRAM_A9: U2.M21 (DRAM_A9), U4.R3 (A9)
/RAM/DRAM_A10: U2.K19 (DRAM_A10), U4.L7 (A10/AP)
/RAM/DRAM_A11: U2.L22 (DRAM_A11), U4.R7 (A11)
/RAM/DRAM_A12: U2.L20 (DRAM_A12), U4.N7 (A12/~BC)
/RAM/DRAM_A13: U2.L23 (DRAM_A13), U4.T3 (A13)
/RAM/DRAM_A14: U2.N18 (DRAM_A14), U4.T7 (A14)
/RAM/DRAM_CALIBRATION: R27.2, U2.M23 (DRAM_CALIBRATION)
/RAM/DRAM_CAS: U2.L18 (DRAM_CAS), U4.K3 (~CAS)
/RAM/DRAM_CS0: U2.K18 (DRAM_CS0), U4.L2 (~CS)
/RAM/DRAM_D0: U2.H20 (DRAM_D0), U4.E3 (DQ0)
/RAM/DRAM_D1: U2.G21 (DRAM_D1), U4.F7 (DQ1)
/RAM/DRAM_D2: U2.J21 (DRAM_D2), U4.F2 (DQ2)
/RAM/DRAM_D3: U2.G20 (DRAM_D3), U4.F8 (DQ3)
/RAM/DRAM_D4: U2.J23 (DRAM_D4), U4.H3 (DQ4)
/RAM/DRAM_D5: U2.G23 (DRAM_D5), U4.H8 (DQ5)
/RAM/DRAM_D6: U2.J22 (DRAM_D6), U4.G2 (DQ6)
/RAM/DRAM_D7: U2.G22 (DRAM_D7), U4.H7 (DQ7)
/RAM/DRAM_D8: U2.E21 (DRAM_D8), U4.D7 (DQ8)
/RAM/DRAM_D9: U2.D21 (DRAM_D9), U4.C3 (DQ9)
/RAM/DRAM_D10: U2.E22 (DRAM_D10), U4.C8 (DQ10)
/RAM/DRAM_D11: U2.D20 (DRAM_D11), U4.C2 (DQ11)
/RAM/DRAM_D12: U2.E23 (DRAM_D12), U4.A7 (DQ12)
/RAM/DRAM_D13: U2.C23 (DRAM_D13), U4.A2 (DQ13)
/RAM/DRAM_D14: U2.F23 (DRAM_D14), U4.B8 (DQ14)
/RAM/DRAM_D15: U2.C22 (DRAM_D15), U4.A3 (DQ15)
/RAM/DRAM_DQM0: U2.H21 (DRAM_DQM0), U4.E7 (LDM)
/RAM/DRAM_DQM1: U2.E20 (DRAM_DQM1), U4.D3 (UDM)
/RAM/DRAM_RAS: U2.J19 (DRAM_RAS), U4.J3 (~RAS)
/RAM/DRAM_RESET: U2.P18 (DRAM_RESET), U4.T2 (~RESET)
/RAM/DRAM_SDBA0: U2.R19 (DRAM_SDBA0), U4.M2 (BA0)
/RAM/DRAM_SDBA1: U2.P20 (DRAM_SDBA1), U4.N8 (BA1)
/RAM/DRAM_SDBA2: U2.N19 (DRAM_SDBA2), U4.M3 (BA2)
/RAM/DRAM_SDCKE0: U2.H19 (DRAM_SDCKE0), U4.K9 (CKE)
/RAM/DRAM_SDCLK_0: R30.1, U2.K23 (DRAM_SDCLK_0), U4.J7 (CK)
/RAM/DRAM_SDCLK_0_B: R30.2, U2.K22 (~DRAM_SDCLK_0_B), U4.K7 (~CK)
/RAM/DRAM_SDODT0: U2.J18 (DRAM_SDODT0), U4.K1 (ODT)
/RAM/DRAM_SDQS0: U2.H23 (DRAM_SDQS0), U4.F3 (LDQS)
/RAM/DRAM_SDQS0_B: U2.H22 (~DRAM_SDQS0_B), U4.G3 (~LDQS)
/RAM/DRAM_SDQS1: U2.D23 (DRAM_SDQS1), U4.C7 (UDQS)
/RAM/DRAM_SDQS1_B: U2.D22 (~DRAM_SDQS1_B), U4.B7 (~UDQS)
/RAM/DRAM_WE: U2.L19 (DRAM_SDWE), U4.L3 (~WE)
GND: C89.2, C91.2, C93.2, C94.2, C95.2, C96.2, C97.2, C98.2, C99.2, C100.2, C101.2, C102.2, C103.2, C104.2, C105.2, C106.2, R24.1, R27.1, R29.1, U4.A9 (VSS1), U4.B1 (VSSQ1), U4.B3 (VSS2), U4.B9 (VSSQ2), U4.D1 (VSSQ3), U4.D8 (VSSQ4), U4.E1 (VSS3), U4.E2 (VSSQ5), U4.E8 (VSSQ6), U4.F9 (VSSQ7), U4.G1 (VSSQ8), U4.G8 (VSS4), U4.G9 (VSSQ9), U4.J2 (VSS5), U4.J8 (VSS6), U4.M9 (VSS8), U4.P1 (VSS9), U4.P9 (VSS10), U4.T1 (VSS11), U4.T9 (VSS12); also elsewhere on the board
PMIC_DDR_1V5: C90.1, C94.1, C95.1, C96.1, C97.1, C98.1, C99.1, C100.1, C101.1, C102.1, C103.1, C104.1, C105.1, C106.1, R15.2, U4.A1 (VDDQ1), U4.A8 (VDDQ2), U4.B2 (VDD1), U4.C1 (VDDQ3), U4.C9 (VDDQ4), U4.D2 (VDDQ5), U4.D9 (VDD2), U4.E9 (VDDQ6), U4.F1 (VDDQ7), U4.G7 (VDD3), U4.H2 (VDDQ8), U4.H9 (VDDQ9), U4.K2 (VDD4), U4.K8 (VDD5), U4.N1 (VDD6), U4.N9 (VDD7), U4.R1 (VDD8), U4.R9 (VDD9); also elsewhere on the board

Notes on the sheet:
Place near the VDD balls.
Place near the VDDQ balls.


Board: 8 copper layers, 65.6 x 19.6 mm, 186 parts (0 on the bottom side), 126 nets.

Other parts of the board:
Ref**: Val**; LOGO_SMALL

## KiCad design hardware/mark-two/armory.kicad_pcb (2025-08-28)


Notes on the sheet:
microSD
DDR3L RAM 512MB/1GB
eMMC
Secure elements
Bluetooth module
Boot configuration
GPIOs and I2C
i.MX6UL power
USB 2.0 Type-C interfaces
Crystals and UARTs
ESD AND OVERVOLTAGE PROTECTIONS Type-C VBUS overvoltage (20V) protections: - All ICs behind ON semiconductor FPF2286 OVP, that can withstand DC inputs up to 28V. Type-C short-to-VBUS protections: - USB1 CC/VBUS: unprotected, TUSB320 can withstand only DC inputs from 0 to 6V. - USB2 CC1/CC2/VBUS: FU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
PMIC
Description
Power tree
COVER PAGE
REVISIONS (see https://github.com/usbarmory/usbarmory/wiki/Errata-(Mk-II)) - beta (2019-06-25): - First public release. - gamma (2021-02-18): - connect XL1 and XL2 of U11 to GND. - Invert UART1 RTS/CTS lines connected to BLE module. - Invert UART2 RTS/CTS lines connected to USB-C receptacle. - Move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


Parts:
C28, C29: 16pF; SM0201; Rating 25V/1%; Mfg PN CBR02C160F3GAC
C30, C31: 18pF; SM0201; Rating 50V/5%; Mfg PN GRM0335C1H180JA01D
C33: 0.22uF; SM0201; Rating 6.3V/20%; Mfg PN GRM033R60J224ME15D
R3, R26: 10K; SM0201; Rating 50mW/1%; Mfg PN CRCW020110K0JNED
R5: 2.2M; SM0201; Rating 50mW/5%; Mfg PN RC0201JR-072M2L
TP1, TP2, TP3, TP4, TP5, TP6, TP7, TP10, TP11: TestPoint; TP
U2: MX6UL-VM; SOT1534-2; Mfg PN MCIMX6Z0DVM09AB
Y1: 24MHz; TSX-3225; Mfg PN TSX-3225 24.0000MF15X-AC3
Y2: 32.768kHz; CM7V-T1A; Mfg PN CM7V-T1A-32.768kHz-12.5pF-20PPM-TA-QC

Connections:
/Crystals/JTAG_MOD: R26.1, TP7.1, U2.P15 (JTAG_MOD)
/Crystals/JTAG_TCK: TP2.1, U2.M14 (JTAG_TCK)
/Crystals/JTAG_TDI: TP4.1, U2.N16 (JTAG_TDI)
/Crystals/JTAG_TDO: TP5.1, U2.N15 (JTAG_TDO)
/Crystals/JTAG_TMS: TP3.1, U2.P14 (JTAG_TMS)
/Crystals/JTAG_nSRST: TP1.1, U2.P8 (~POR)
/Crystals/JTAG_nTRST: TP6.1, U2.N14 (~JTAG_TRST)
/Crystals/RTC_XTALI: C30.1, U2.T11 (RTC_XTALI), Y2.1
/Crystals/RTC_XTALO: C31.1, U2.U11 (RTC_XTALO), Y2.2
/Crystals/XTALI: C28.1, R5.1, U2.T16 (XTALI), Y1.3
/Crystals/XTALO: C29.1, U2.T17 (XTALO), Y1.1
BT_SWITCH_1: U2.G14 (~UART3_RTS); also elsewhere on the board
BT_SWITCH_2: U2.H15 (~UART3_CTS); also elsewhere on the board
BT_UART_CTS: U2.K15 (~UART1_CTS); also elsewhere on the board
BT_UART_DSR: U2.H17 (UART3_TX_DATA); also elsewhere on the board
BT_UART_DTR: U2.H16 (UART3_RX_DATA); also elsewhere on the board
BT_UART_RX: U2.K16 (UART1_RX_DATA); also elsewhere on the board
BT_UART_TX: U2.K14 (UART1_TX_DATA); also elsewhere on the board
DCDC_3V3: C33.1, TP11.1, U2.H13 (NVCC_UART); also elsewhere on the board
GND: C28.2, C29.2, C30.2, C31.2, C33.2, R5.2, R26.2, TP10.1, U2.N7 (TEST_MODE), U2.T10 (BOOT_MODE0), Y1.2, Y1.4; also elsewhere on the board
LDO2_3V3: R3.1; also elsewhere on the board
unnamed: R3.2, U2.U10 (BOOT_MODE1)
SD1_CD_B: U2.J14 (~UART1_RTS); also elsewhere on the board
UART2_CTS: U2.J15 (~UART2_CTS); also elsewhere on the board
UART2_RTS: U2.H14 (~UART2_RTS); also elsewhere on the board
UART2_RX: U2.J16 (UART2_RX_DATA); also elsewhere on the board
UART2_TX: U2.J17 (UART2_TX_DATA); also elsewhere on the board
UART4_RX: U2.G16 (UART4_RX_DATA); also elsewhere on the board
UART4_TX: U2.G17 (UART4_TX_DATA); also elsewhere on the board
UART5_RX: U2.G13 (UART5_RX_DATA); also elsewhere on the board
UART5_TX: U2.F17 (UART5_TX_DATA); also elsewhere on the board

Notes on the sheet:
BOOT_MODE[1:0] Internal Boot If errors occur -> Serial Downloader Mode BOOT_MODE0 tied to GND and BOOT_MODE1 tied to VDD_SNVS_IN [1] pg 9
TEST_MODE: GND [1] pg 15 says floating. [2] pg 18 says directly to GND.
[1] Hardware Development Guide for the i.MX 6UltraLite Application Processor, Rev. 3, 09/2018
SNVS_TAMPERx: floating Recomended to leave floting for SNVS_IN power reduction. https://community.nxp.com/thread/439496 [1] pg 20 [2] pg 126 [3] pg 12
[2] i.MX 6UltraLite Applications Processors for Consumer Products, Rev. 2.2, 05/2017
Bluetooth interface
GPIO1_IO24 [ALT5]
GPIO1_IO25 [ALT5]
GPIO1_IO26 [ALT5]
GPIO1_IO27 [ALT5]
UART1_TX [ALT0]
UART1_CTS_B [ALT0]
ONOFF: floating [1] pg 15
[3] i.MX 6UltraLite Power Consumption Measurement, Rev. 2, 05/2016
UART1_RX [ALT0]
USDHC1_CD_B [ALT2]
ULZ pad name: I2C2_SDA -> ECSPI2_SDI [ALT8] / I2C2_SDA [ALT2] / GPIO1_IO31 [ALT5]
ULZ pad name: I2C2_SCL -> ECSPI2_SDO [ALT8] / I2C2_SCL [ALT2] / GPIO1_IO30 [ALT5]
UART4_TX [ALT0] / ECSPI2_SCLK [ALT8] / I2C1_SCL [ALT2] / GPIO1_IO28 [ALT5]
ULZ: UART2_CTS_B [ALT0] / GPIO1_IO22 [ALT5]
ULZ: UART2_RTS_B [ALT0] / GPIO1_IO23 [ALT5]
ULZ: UART2_RX [ALT0] / GPIO1_IO21 [ALT5]
Type-C Debug Mode interface
UART5_RX [ALT0] / ECSPI2_SDI [ALT8] / I2C2_SDA [ALT2] / GPIO1_IO31 [ALT5]
UART5_TX [ALT0] / ECSPI2_SDO [ALT8] / I2C2_SCL [ALT2] / GPIO1_IO30 [ALT5]
UART4_RX [ALT0] / ECSPI2_CS0 [ALT8] / I2C1_SDA [ALT2] / GPIO1_IO29 [ALT5]
UART2_RTS_B [ALT0] / ECSPI3_SDI [ALT8] / FLEXCAN2_RX [ALT2] / GPIO1_IO23 [ALT5]
UART2_CTS_B [ALT0] / ECSPI3_SDO [ALT8] / FLEXCAN2_TX [ALT2] / GPIO1_IO22 [ALT5]
UART2_RX [ALT0] / ECSPI3_SCLK [ALT8] / I2C4_SDA [ALT2] / GPIO1_IO21 [ALT5]
UART2_TX [ALT0] / ECSPI3_CS0 [ALT8] / I2C4_SCL [ALT2] / GPIO1_IO20 [ALT5]
ULZ: UART2_TX [ALT0] / GPIO1_IO20 [ALT5]
Chosen recomended crystal P/N: https://www.nxp.com/docs/en/engineering-bulletin/EB830.pdf


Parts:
C34: 0.22uF; SM0201; Rating 6.3V/20%; Mfg PN GRM033R60J224ME15D
C35, C39, C41, C43, C44: 0.1uF; SM0201; Rating 10V/20%; Mfg PN GRM033R61A104ME15D
C36: 4.7uF; SM0402; Rating 10V/20%; Mfg PN ZRB15XR61A475ME01D
C45: 10uF; SM0402; Rating 10V/20%; Mfg PN CL05A106MP8NUB8
R6, R7, R8, R9, R10, R11, R12, R13, R14, R15: 10K; SM0201; Rating 50mW/1%; Mfg PN CRCW020110K0JNED
R16: 22R; SM0201; Rating 50mW/1%; Mfg PN CRCW020122R0JNED
U2: MX6UL-VM; SOT1534-2; Mfg PN MCIMX6Z0DVM09AB
U3: EMMC16G; FBGA-153; Mfg PN EMMC16G-TB29-PZ90

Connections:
/eMMC/SD2_CLK: R16.1, U3.M6 (CLK)
/eMMC/SD2_CLK_R: R16.2, U2.D8 (~NAND_RE)
/eMMC/SD2_CMD: R7.2, U2.C8 (~NAND_WE), U3.M5 (CMD)
/eMMC/SD2_DATA0: R15.2, U2.D7 (NAND_DATA00), U3.A3 (DAT0)
/eMMC/SD2_DATA1: R14.2, U2.B7 (NAND_DATA01), U3.A4 (DAT1)
/eMMC/SD2_DATA2: R13.2, U2.A7 (NAND_DATA02), U3.A5 (DAT2)
/eMMC/SD2_DATA3: R12.2, U2.D6 (NAND_DATA03), U3.A1 (NC1), U3.B2 (DAT3)
/eMMC/SD2_DATA4: R11.2, U2.C6 (NAND_DATA04), U3.A2 (NC2), U3.B3 (DAT4)
/eMMC/SD2_DATA5: R10.2, U2.B6 (NAND_DATA05), U3.B4 (DAT5), U3.C3 (NC21), U3.D1 (NC31), U3.D2 (NC32)
/eMMC/SD2_DATA6: R9.2, U2.A6 (NAND_DATA06), U3.B5 (DAT6), U3.C5 (NC22)
/eMMC/SD2_DATA7: R8.2, U2.A5 (NAND_DATA07), U3.B6 (DAT7), U3.C7 (NC23)
/eMMC/SD2_RESET_B: R6.2, U2.B4 (NAND_ALE), U3.K5 (~RST)
/eMMC/VDDI: C35.1, C36.1, U3.C1 (NC20), U3.C2 (VDDI)
DCDC_3V3: C39.1, C41.1, C43.1, C44.1, C45.1, U3.E6 (VCC1), U3.F5 (VCC2), U3.J10 (VCC3), U3.K9 (VCC4); also elsewhere on the board
EMMC_1V8: C34.1, R6.1, R7.1, R8.1, R9.1, R10.1, R11.1, R12.1, R13.1, R14.1, R15.1, U2.E7 (NVCC_NAND), U3.C6 (VCCQ1), U3.M4 (VCCQ2), U3.N3 (NC101), U3.N4 (VCCQ3), U3.P3 (VCCQ4), U3.P5 (VCCQ5); also elsewhere on the board
GND: C34.2, C35.2, C36.2, C39.2, C41.2, C43.2, C44.2, C45.2, U3.A6 (VSS1), U3.C4 (VSSQ1), U3.D4 (NC34), U3.E7 (VSS2), U3.G5 (VSS3), U3.H10 (VSS4), U3.J5 (VSS5), U3.K8 (VSS6), U3.N1 (NC100), U3.N2 (VSSQ2), U3.N5 (VSSQ3), U3.P4 (VSSQ4), U3.P6 (VSSQ5); also elsewhere on the board

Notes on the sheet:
Dummy connections of some lines to NC balls connected to ease PCB routing.
DS unconnected: eMMC 5.0 specific


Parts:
C38: 1uF; SM0201; Rating 10V/20%; Mfg PN GRM033R61A105ME15D
C40: 0.1uF; SM0201; Rating 10V/20%; Mfg PN GRM033R61A104ME15D
C46, C47, C48: 0.22uF; SM0201; Rating 6.3V/20%; Mfg PN GRM033R60J224ME15D
D1: WHITE; SM0603_LED; Rating 5mA/2.85V; Mfg PN LW Q38E-Q1OO-3K6L-1
D2: BLUE; SM0603_LED; Rating 5mA/2.85V; Mfg PN LB Q39G-L2OO-35-1
R17, R18: 4.7K; SM0201; Rating 50mW/1%; Mfg PN CRCW02014K70JNED
R19: 1K8; SM0201; Rating 50mW/1%; Mfg PN ERJ-1GNF1801C
R20: 680R; SM0201; Rating 50mW/1%; Mfg PN ERJ-1GNF6800C
U2: MX6UL-VM; SOT1534-2; Mfg PN MCIMX6Z0DVM09AB

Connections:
BT_RESET_B: U2.M15 (GPIO1_IO09); also elsewhere on the board
BT_SWDCLK: U2.M16 (GPIO1_IO04); also elsewhere on the board
BT_SWDIO: U2.K17 (GPIO1_IO06); also elsewhere on the board
BT_UART_RTS: U2.L16 (GPIO1_IO07); also elsewhere on the board
DCDC_3V3: C46.1, C47.1, C48.1, R17.1, R18.1, U2.F4 (NVCC_CSI), U2.F13 (NVCC_ENET), U2.J13 (NVCC_GPIO); also elsewhere on the board
GND: C38.2, C40.2, C46.2, C47.2, C48.2; also elsewhere on the board
I2C1_SCL: R17.2, U2.L14 (GPIO1_IO02); also elsewhere on the board
I2C1_SDA: R18.2, U2.L17 (GPIO1_IO03); also elsewhere on the board
LDO2_3V3: C38.1, C40.1, D1.2 (A), D2.2 (A), U2.L13 (VDDA_ADC_3P3), U2.M13 (ADC_VREFH); also elsewhere on the board
unnamed: D1.1 (K), R19.1
unnamed: D2.1 (K), R20.1
unnamed: R19.2, U2.E4 (CSI_DATA00)
unnamed: R20.2, U2.E3 (CSI_DATA01)
PMIC_WDI: U2.F15 (ENET1_TX_EN); also elsewhere on the board
SE050_ENA: U2.A16 (ENET2_TX_DATA1); also elsewhere on the board
USB1_INT_B: U2.K13 (GPIO1_IO00); also elsewhere on the board
USB2_ID: U2.M17 (GPIO1_IO05); also elsewhere on the board
USB2_INT_B: U2.L15 (GPIO1_IO01); also elsewhere on the board

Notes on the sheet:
[1] Hardware Development Guide for the i.MX 6UltraLite Application Processor, Rev. 3, 09/2018
ADC_VREFH: tied to VDDA_ADC_3P3 [1] pg 18
VDDA_ADC_3P3 must be powered even if the ADC is not used. [1] pg 18
I2C1_SCL [ALT0]
I2C1_SDA [ALT0]
GPIO1_IO9 [ALT5]
GPIO1_IO6 [ALT5]
GPIO1_IO4 [ALT5]
I2C1 ADDRESSES (8bit address / 7 bit address) 0x10 / 0x08: PMIC (400 kHz) 0xC0 / 0x60: Microchip SECURE ELEMENT ATECC608A (1 MHz) 0x90 / 0x48: NXP SECURE ELEMENT SE050 (1.7 MHz) 0xC2 / 0x61: TUSB320 USB1 (Type-C plug) (400 kHz) 0x62 / 0x31: FUSB303 USB2 (Type-C receptacle) (400 kHz)
GPIO1_IO0 [ALT5]
GPIO1_IO1 [ALT5]
ANATOP_OTG2_ID [ALT2]
UART1_RTS_B [ALT8]
ENET1_TX_EN (ULZ: KPP_COL2) -> WDOG2_WDOG_RST_B_DEB [ALT8]
CSI_DATA00 (ULZ: SD2_DATA0) -> GPIO4_IO21 [ALT5]
CSI_DATA01 (ULZ: SD2_DATA1) -> GPIO4_IO22 [ALT5]
ULZ: VDD_HIGH_IN

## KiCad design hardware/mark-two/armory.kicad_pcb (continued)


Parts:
C6: 0.1uF; SM0201; Rating 35V/10%; Mfg PN GRM033R61A104ME15D
C7, C19, C52, C108, C109: 0.1uF; SM0201; Rating 10V/20%; Mfg PN GRM033R61A104ME15D
C49, C50: 1uF; SM0201; Rating 10V/20%; Mfg PN GRM033R61A105ME15D
C51, C54, C110, C111: 4.7uF; SM0603; Rating 35V/10%; Mfg PN GRM188R6YA475KE15D
C53: 10uF; SM0402; Rating 10V/20%; Mfg PN CL05A106MP8NUB8
D3, D4: NSR20F30NXT5G; DSN2; Rating 30V/2.0A/480mV@2A; Mfg PN NSR20F30NXT5G
J2: USBC-PLUG_24_PIN; WURTH_632712000112; Mfg PN 632712000112
J3: USBC-RECEPTACLE; MOLEX_105450-0101; Mfg PN 105450-0101
R21, R23, R24, R25, R28, R57, R58: 10K; SM0201; Rating 50mW/1%; Mfg PN CRCW020110K0JNED
R32, R33: 100K; SM0201; Rating 50mW/1%; Mfg PN CRCW0201100KJNED
R34: 1M; SM0201; Rating 50mW/1%; Mfg PN CRCW02011M00FKED
R59: 33K; SM0201; Rating 50mW/1%; Mfg PN CRCW020133K0FKED
U2: MX6UL-VM; SOT1534-2; Mfg PN MCIMX6Z0DVM09AB
U5: FPF2286UCX; WLCSP-6; Mfg PN FPF2286UCX
U6, U7: TPD4E05U06; DQA-USON-10; Mfg PN TPD4E05U06DQAR
U8: NX5P3090; SOT1390-5; Mfg PN NX5P3090UKZ
U9: FUSB303; RWB-QFN-12; Mfg PN FUSB303TMX
U14: TUSB320; RWB-QFN-12; Mfg PN TUSB320IRWBR
U15, U16: TPD1E10B06; X1SON-2; Mfg PN TPD1E10B06DPYR
U17: SN74LVC1G04; X2SON-4; Mfg PN SN74LVC1G04DPWR
U18: FSA1208; MLP-20; Mfg PN FSA1208BQX
U19: TPD8E003; WSON-8; Mfg PN TPD8E003DQDR

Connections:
/USB/DEBUG_B: U9.3 (PORT/DEBUG_N), U18.20 (~OE)
/USB/TYPEC_A2: J3.A2 (TX1+), U18.2 (A1), U19.6 (IO6)
/USB/TYPEC_A3: J3.A3 (TX1-), U18.3 (A2), U19.5 (IO5)
/USB/TYPEC_A10: J3.A10 (RX2-), U18.6 (A5), U19.1 (IO1)
/USB/TYPEC_A11: J3.A11 (RX2+), U18.7 (A6), U19.2 (IO2)
/USB/TYPEC_B2: J3.B2 (TX2+), U18.9 (A8), U19.4 (IO4)
/USB/TYPEC_B3: J3.B3 (TX2-), U18.8 (A7), U19.3 (IO3)
/USB/TYPEC_B10: J3.B10 (RX1-), U18.5 (A4), U19.7 (IO7)
/USB/TYPEC_B11: J3.B11 (RX1+), U18.4 (A3), U19.8 (IO8)
/USB/USB1_CC: J2.A5 (CC), U6.4 (D2+), U6.7 (NC), U14.1 (CC1)
/USB/USB1_DN: J2.A7 (D-), U2.T15 (USB_OTG1_DN), U6.1 (D1+), U6.10 (NC)
/USB/USB1_DP: J2.A6 (D+), U2.U15 (USB_OTG1_DP), U6.2 (D1-), U6.9 (NC)
/USB/USB1_VBUS: C111.1, D3.2 (A), J2.A4 (VBUS), J2.A9 (VBUS), J2.B4 (VBUS), J2.B9 (VBUS), R33.1, R34.1, U15.1
/USB/USB2_CC1: J3.A5 (CC1), U7.1 (D1+), U7.10 (NC), U9.1 (CC1)
/USB/USB2_CC2: J3.B5 (CC2), U7.2 (D1-), U7.9 (NC), U9.2 (CC2)
/USB/USB2_DN: J3.A7 (D-), J3.B7 (D-), U2.T13 (USB_OTG2_DN), U7.5 (D2-), U7.6 (NC)
/USB/USB2_DP: J3.A6 (D+), J3.B6 (D+), U2.U13 (USB_OTG2_DP), U7.4 (D2+), U7.7 (NC)
/USB/USB2_VBUS: C51.1, C110.1, D4.2 (A), J3.A4 (VBUS), J3.A9 (VBUS), J3.B4 (VBUS), J3.B9 (VBUS), R32.1, U8.C2 (VBUS1), U8.D1 (VBUS2), U8.D2 (VBUS3), U9.4 (VBUS_DET), U16.1
/USB/USB_SW_EN: R21.1, U8.A1 (EN), U17.4 (Y)
/USB/USB_VBUS: C6.1, D3.1 (K), D4.1 (K), U5.A2 (IN), U5.B2 (IN)
/USB/VDD_USB_CAP: C52.1, C53.1, U2.R12 (VDD_USB_CAP)
DCDC_3V3: C19.1, C108.1, C109.1, R23.1, R24.1, R25.1, R28.1, R57.1, R58.1, U9.12 (VDD), U14.12 (VDD), U17.5 (VCC), U18.1 (VCC); also elsewhere on the board
GND: C6.2, C7.2, C19.2, C49.2, C50.2, C51.2, C52.2, C53.2, C54.2, C108.2, C109.2, C110.2, C111.2, J2.A1 (GND), J2.A12 (GND), J2.B1 (GND), J2.B12 (GND), J2.S, J3.A1 (GND), J3.A12 (GND), J3.B1 (GND), J3.B12 (GND), J3.S (SHIELD), R21.2, R32.2, R33.2, R59.2, U5.C1 (GND), U5.C2 (OVLO), U6.3 (GND), U6.8 (GND), U7.3 (GND), U7.8 (GND), U8.B3 (GND1), U8.C3 (GND2), U8.D3 (GND3), U9.10 (GND), U9.11 (EN_N), U14.3 (PORT), U14.10 (GND), U14.11 (EN_N), U15.2, U16.2, U17.3 (GND), U18.10 (GND), U18.21 (GND), U19.GND; also elsewhere on the board
I2C1_SCL: U9.8 (SCL/OUT2), U14.8 (SCL/OUT2); also elsewhere on the board
I2C1_SDA: U9.7 (SDA/OUT1), U14.7 (SDA/OUT1); also elsewhere on the board
unnamed: R23.2, U9.5 (ADDR/ORIENT)
unnamed: R25.2, U8.A2 (~FAULT)
unnamed: R28.2, U14.5 (ADDR)
unnamed: R34.2, U14.4 (VBUS_DET)
unnamed: R59.1, U8.A3 (ILIM)
UART2_CTS: U18.17 (B3); also elsewhere on the board
UART2_RTS: U18.16 (B4); also elsewhere on the board
UART2_RX: U18.18 (B2); also elsewhere on the board
UART2_TX: U18.19 (B1); also elsewhere on the board
UART4_RX: U18.13 (B7); also elsewhere on the board
UART4_TX: U18.14 (B6); also elsewhere on the board
UART5_RX: U18.12 (B8); also elsewhere on the board
UART5_TX: U18.15 (B5); also elsewhere on the board
USB1_INT_B: R57.2, U14.6 (INT_N/OUT3); also elsewhere on the board
USB2_ID: R24.2, U9.9 (ID), U17.2 (A); also elsewhere on the board
USB2_INT_B: R58.2, U9.6 (INT_N/OUT3); also elsewhere on the board
VSYS_5V: C7.1, C49.1, C50.1, C54.1, U2.T12 (USB_OTG1_VBUS), U2.U12 (USB_OTG2_VBUS), U5.A1 (OUT), U5.B1 (OUT), U8.B1 (VINT1), U8.B2 (VINT3), U8.C1 (VINT2); also elsewhere on the board

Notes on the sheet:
ADDR tied to VDD: 0x62 I2C address selected. PORT floating: DRP mode selected.
ADDR pulled-up: 0xC2 I2C address selected. PORT tied to GND: UFP mode selected.
FUSB303 and TUSB320 devices are used to support the USB Type-C Current feature, defined in section 4.6.2.1 [1]. This is not related to the USB Power Delivery feature, here not implemented. The Source can advertise to the Sink the amount of current it can supply: - Default (500 mA for USB 2.0 or 900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
USB 2.0 Type-C plug
USB 2.0 Type-C receptacle
R_ILIM = 33 kOhm to GND -> 1.5A
Type-C plug ESD protection
Type-C receptacle ESD protection
Type-C plug port controller
Type-C receptacle port controller
Type-C receptacle power switch
Type-C debug mode switch
OVP Voltage = 6.8V
5V, 500mA -> R=35mOhm V_drop(3A) = 100mV
USB2_ID = 0 -> SOURCE USB2_ID = 1 -> SINK
Over voltage protection
i.MX6UL USB interface
R32 and R33 required to keep USB2_VBUS and USB1_VBUS low from 2.2V to 0.4V


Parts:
C55: 0.22uF; SM0201; Rating 6.3V/20%; Mfg PN GRM033R60J224ME15D
R27, R47, R48: 10K; SM0201; Rating 50mW/1%; Mfg PN CRCW020110K0JNED
SW1: CAS-220TA; CAS-220-A; Mfg PN CAS-220TA
U2: MX6UL-VM; SOT1534-2; Mfg PN MCIMX6Z0DVM09AB

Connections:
/Boot/BT_CFG1[0]: U2.B9 (LCD_DATA00)
/Boot/BT_CFG1[1]: U2.A9 (LCD_DATA01)
/Boot/BT_CFG1[2]: U2.E10 (LCD_DATA02)
/Boot/BT_CFG1[3]: U2.D10 (LCD_DATA03)
/Boot/BT_CFG1[4]: U2.C10 (LCD_DATA04)
/Boot/BT_CFG1[5]: R48.1, U2.A12 (LCD_DATA14), U2.B10 (LCD_DATA05), U2.D12 (LCD_DATA11)
/Boot/BT_CFG1[6]: R47.1, U2.A10 (LCD_DATA06)
/Boot/BT_CFG1[7]: U2.D11 (LCD_DATA07)
/Boot/BT_CFG2[0]: U2.B11 (LCD_DATA08)
/Boot/BT_CFG2[1]: U2.A11 (LCD_DATA09)
/Boot/BT_CFG2[2]: U2.E12 (LCD_DATA10)
/Boot/BT_CFG2[4]: U2.C12 (LCD_DATA12)
/Boot/BT_CFG2[5]: R27.1, U2.B12 (LCD_DATA13)
/Boot/BT_CFG2[7]: U2.D13 (LCD_DATA15)
/Boot/BT_CFG4[0]: U2.C13 (LCD_DATA16)
/Boot/BT_CFG4[1]: U2.B13 (LCD_DATA17)
/Boot/BT_CFG4[2]: U2.A13 (LCD_DATA18)
/Boot/BT_CFG4[3]: U2.D14 (LCD_DATA19)
/Boot/BT_CFG4[4]: U2.C14 (LCD_DATA20)
/Boot/BT_CFG4[5]: U2.B14 (LCD_DATA21)
/Boot/BT_CFG4[6]: U2.A14 (LCD_DATA22)
/Boot/BT_CFG4[7]: U2.B16 (LCD_DATA23)
DCDC_3V3: C55.1, R47.2, SW1.3 (C), SW1.4 (A), U2.E13 (NVCC_LCD); also elsewhere on the board
GND: C55.2, SW1.1 (A), SW1.6 (C); also elsewhere on the board
unnamed: R27.2, SW1.5 (B)
unnamed: R48.2, SW1.2 (B)

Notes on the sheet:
Boot from eMMC BOOT_CFG1[7:6] = 01 - Boot from uSDHC interfaces BOOT_CFG1[5] = 1 - Boot from eMMC BOOT_CFG1[4] = 0 - Fast boot support: Regular BOOT_CFG1[3] = 0 - SD/MMC Speed: High BOOT_CFG1[2] = 0 - Fast Boot Acknowledge Disable: Boot Ack Enabled BOOT_CFG1[1] = 0 - SD Power Cycle Enable: No power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
BOOT_CFG4[7:0] = 00000000
SWITCH: TOP BOTTOM BOOT_CFG1[5] 1 0 BOOT_CFG2[6] 1 0 BOOT_CFG2[5] 0 1 BOOT_CFG2[3] 1 0 BOOT FROM: eMMC SD
BOOT_CFG2[7:0] = 0??0?000
BOOT_CFG1[7:0] = 01?00000
Not required to pull-down as at boot all LCD_DATA pins are pulled down with 100K. (pg 96 [1])
[1] i.MX 6UltraLite Applications Processors for Consumer Products, Rev. 2.2, 05/2017
Boot from microSD BOOT_CFG1[7:6] = 01 - Boot from uSDHC interfaces BOOT_CFG1[5] = 0 - Boot from SD BOOT_CFG1[4] = 0 - Fast boot support: Regular BOOT_CFG1[3:2] = 00 - SD/SDXC Speed: Normal/SDR12 BOOT_CFG1[1] = 0 - SD Power Cycle Enable: No power cycle BOOT_CFG1[0] = 0 - SD Loopback Clock Source Sel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
Default position: TOP (2->3 and 5->6).
DPDT switch


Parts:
C57, C77: 22uF; SM0402; Rating 6.3V/20%; Mfg PN CL05A226MQ5N6J8
C59, C60, C63, C66, C67, C68, C69, C70, C71, C73, C74, C75, C78, C79, C80, C81, C82, C83, C84: 0.22uF; SM0201; Rating 6.3V/20%; Mfg PN GRM033R60J224ME15D
R31, R50: 10K; SM0201; Rating 50mW/1%; Mfg PN CRCW020110K0JNED
R51, R53: 240R; SM0201; Rating 50mW/1%; Mfg PN CRCW0201240RFNED
R52: 470R; SM0201; Rating 50mW/5%; Mfg PN CRCW0201470RJNED
U2: MX6UL-VM; SOT1534-2; Mfg PN MCIMX6Z0DVM09AB
U10: MT41K256M16; MICRON-FBGA-96; Mfg PN MT41K256M16TW-107:P

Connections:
/DDR/DDR_ZQ: R53.1, U10.L8 (ZQ)
/DDR/DRAM_A0: U2.L5 (DRAM_ADDR00), U10.N3 (A0)
/DDR/DRAM_A1: U2.H2 (DRAM_ADDR01), U10.P7 (A1)
/DDR/DRAM_A2: U2.K1 (DRAM_ADDR02), U10.P3 (A2)
/DDR/DRAM_A3: U2.M2 (DRAM_ADDR03), U10.N2 (A3)
/DDR/DRAM_A4: U2.K4 (DRAM_ADDR04), U10.P8 (A4)
/DDR/DRAM_A5: U2.L1 (DRAM_ADDR05), U10.P2 (A5)
/DDR/DRAM_A6: U2.G2 (DRAM_ADDR06), U10.R8 (A6)
/DDR/DRAM_A7: U2.H4 (DRAM_ADDR07), U10.R2 (A7)
/DDR/DRAM_A8: U2.J4 (DRAM_ADDR08), U10.T8 (A8)
/DDR/DRAM_A9: U2.L2 (DRAM_ADDR09), U10.R3 (A9)
/DDR/DRAM_A10: U2.M4 (DRAM_ADDR10), U10.L7 (A10/AP)
/DDR/DRAM_A11: U2.K3 (DRAM_ADDR11), U10.R7 (A11)
/DDR/DRAM_A12: U2.L4 (DRAM_ADDR12), U10.N7 (A12/~BC)
/DDR/DRAM_A13: U2.H3 (DRAM_ADDR13), U10.T3 (A13)
/DDR/DRAM_A14: U2.G1 (DRAM_ADDR14), U10.T7 (A14)
/DDR/DRAM_A15: U2.K5 (DRAM_ADDR15), U10.M7 (NC_M7_/_A15)
/DDR/DRAM_CAS_B: U2.J2 (~DRAM_CAS), U10.K3 (~CAS)
/DDR/DRAM_CS0_B: U2.N2 (~DRAM_CS0), U10.L2 (~CS)
/DDR/DRAM_D0: U2.T4 (DRAM_DATA00), U10.E3 (DQ0)
/DDR/DRAM_D1: U2.U6 (DRAM_DATA01), U10.G2 (DQ6)
/DDR/DRAM_D2: U2.T6 (DRAM_DATA02), U10.F8 (DQ3)
/DDR/DRAM_D3: U2.U7 (DRAM_DATA03), U10.H3 (DQ4)
/DDR/DRAM_D4: U2.U8 (DRAM_DATA04), U10.H8 (DQ5)
/DDR/DRAM_D5: U2.T8 (DRAM_DATA05), U10.H7 (DQ7)
/DDR/DRAM_D6: U2.T5 (DRAM_DATA06), U10.F2 (DQ2)
/DDR/DRAM_D7: U2.U4 (DRAM_DATA07), U10.F7 (DQ1)
/DDR/DRAM_D8: U2.U2 (DRAM_DATA08), U10.D7 (DQ8)
/DDR/DRAM_D9: U2.U3 (DRAM_DATA09), U10.A7 (DQ12)
/DDR/DRAM_D10: U2.U5 (DRAM_DATA10), U10.B8 (DQ14)
/DDR/DRAM_D11: U2.R4 (DRAM_DATA11), U10.A2 (DQ13)
/DDR/DRAM_D12: U2.P5 (DRAM_DATA12), U10.A3 (DQ15)
/DDR/DRAM_D13: U2.P3 (DRAM_DATA13), U10.C8 (DQ10)
/DDR/DRAM_D14: U2.R2 (DRAM_DATA14), U10.C2 (DQ11)
/DDR/DRAM_D15: U2.R1 (DRAM_DATA15), U10.C3 (DQ9)
/DDR/DRAM_DQM0: U2.T7 (DRAM_DQM0), U10.E7 (LDM)
/DDR/DRAM_DQM1: U2.T3 (DRAM_DQM1), U10.D3 (UDM)
/DDR/DRAM_RAS_B: U2.M5 (~DRAM_RAS), U10.J3 (~RAS)
/DDR/DRAM_RESET_B: R50.1, U2.G4 (DRAM_RESET), U10.T2 (~RESET)
/DDR/DRAM_SDBA0: U2.M1 (DRAM_SDBA0), U10.M2 (BA0)
/DDR/DRAM_SDBA1: U2.H1 (DRAM_SDBA1), U10.N8 (BA1)
/DDR/DRAM_SDBA2: U2.K2 (DRAM_SDBA2), U10.M3 (BA2)
/DDR/DRAM_SDCKE0: R31.1, U2.M3 (DRAM_SDCKE0), U10.K9 (CKE)
/DDR/DRAM_SDCLK0_N: R52.1, U2.P2 (DRAM_SDCLK0_N), U10.K7 (~CK)
/DDR/DRAM_SDCLK0_P: R52.2, U2.P1 (DRAM_SDCLK0_P), U10.J7 (CK)
/DDR/DRAM_SDODT0: U2.N1 (DRAM_ODT0), U10.K1 (ODT)
/DDR/DRAM_SDQS0_N: U2.P7 (DRAM_SDQS0_N), U10.G3 (~LDQS)
/DDR/DRAM_SDQS0_P: U2.P6 (DRAM_SDQS0_P), U10.F3 (LDQS)
/DDR/DRAM_SDQS1_N: U2.T2 (DRAM_SDQS1_N), U10.B7 (~UDQS)
/DDR/DRAM_SDQS1_P: U2.T1 (DRAM_SDQS1_P), U10.C7 (UDQS)
/DDR/DRAM_WE_B: U2.J1 (~DRAM_SDWE), U10.L3 (~WE)
/DDR/DRAM_ZQPAD: R51.1, U2.N4 (DRAM_ZQPAD)
DDR_1V35: C57.1, C59.1, C60.1, C63.1, C67.1, C68.1, C69.1, C70.1, C71.1, C73.1, C74.1, C75.1, C77.1, C78.1, C79.1, C81.1, C82.1, U2.G6 (NVCC_DRAM1), U2.H6 (NVCC_DRAM2), U2.J6 (NVCC_DRAM3), U2.K6 (NVCC_DRAM4), U2.L6 (NVCC_DRAM5), U2.M6 (NVCC_DRAM6), U10.A1 (VDDQ1), U10.A8 (VDDQ2), U10.B2 (VDD1), U10.C1 (VDDQ3), U10.C9 (VDDQ4), U10.D2 (VDDQ5), U10.D9 (VDD2), U10.E9 (VDDQ6), U10.F1 (VDDQ7), U10.G7 (VDD3), U10.H2 (VDDQ8), U10.H9 (VDDQ9), U10.K2 (VDD4), U10.K8 (VDD5), U10.N1 (VDD6), U10.N9 (VDD7), U10.R1 (VDD8), U10.R9 (VDD9); also elsewhere on the board
DDR_VREF: C66.1, C83.1, C84.1, U2.P4 (DRAM_VREF), U10.H1 (VREFDQ), U10.M8 (VREFCA); also elsewhere on the board
GND: C57.2, C59.2, C60.2, C63.2, C66.2, C67.2, C68.2, C69.2, C70.2, C71.2, C73.2, C74.2, C75.2, C77.2, C78.2, C79.2, C80.2, C81.2, C82.2, C83.2, C84.2, R31.2, R50.2, R51.2, R53.2, U10.A9 (VSS1), U10.B1 (VSSQ1), U10.B3 (VSS2), U10.B9 (VSSQ2), U10.D1 (VSSQ3), U10.D8 (VSSQ4), U10.E1 (VSS3), U10.E2 (VSSQ5), U10.E8 (VSSQ6), U10.F9 (VSSQ7), U10.G1 (VSSQ8), U10.G8 (VSS4), U10.G9 (VSSQ9), U10.J2 (VSS5), U10.J8 (VSS6), U10.M1 (VSS7), U10.M9 (VSS8), U10.P1 (VSS9), U10.P9 (VSS10), U10.T1 (VSS11), U10.T9 (VSS12); also elsewhere on the board
VDD_HIGH_CAP: C80.1, U2.N6 (NVCC_DRAM_2P5); also elsewhere on the board

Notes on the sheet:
Used for 8Gb.
512MB: Micron MT41K256M16TW 1GB: Micron MT41K512M16HA
[1] Hardware Development Guide for the i.MX 6UltraLite Application Processor, Rev. 3, 09/2018
Differentials pairs have impedence 100 Ohm. [1] pg 23 But all the imx6UL reference designs use a 470 Ohm.

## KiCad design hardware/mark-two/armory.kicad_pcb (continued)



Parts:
C85, C88: 4.7uF; SM0402; Rating 10V/20%; Mfg PN ZRB15XR61A475ME01D
C86, C89, C90, C91, C92, C93, C94, C95, C96, C99, C100, C101: 0.22uF; SM0201; Rating 6.3V/20%; Mfg PN GRM033R60J224ME15D
C87, C98, C103: 22uF; SM0402; Rating 6.3V/20%; Mfg PN CL05A226MQ5N6J8
C97, C102: 10uF; SM0402; Rating 10V/20%; Mfg PN CL05A106MP8NUB8
U2: MX6UL-VM; SOT1534-2; Mfg PN MCIMX6Z0DVM09AB

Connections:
/Power/NVCC_PLL_OUT: C95.1, C97.1, U2.P13 (NVCC_PLL)
/Power/VDD_ARM_CAP: C99.1, C101.1, C103.1, U2.G9 (VDD_ARM_CAP1), U2.G10 (VDD_ARM_CAP2), U2.G11 (VDD_ARM_CAP3), U2.H11 (VDD_ARM_CAP4)
/Power/VDD_SNVS_CAP: C93.1, U2.N12 (VDD_SNVS_CAP)
/Power/VDD_SOC_CAP: C92.1, C94.1, C96.1, C98.1, U2.G8 (VDD_SOC_CAP1), U2.H8 (VDD_SOC_CAP2), U2.J8 (VDD_SOC_CAP3), U2.J11 (VDD_SOC_CAP4), U2.K8 (VDD_SOC_CAP5), U2.K11 (VDD_SOC_CAP6), U2.L8 (VDD_SOC_CAP7), U2.L9 (VDD_SOC_CAP8), U2.L10 (VDD_SOC_CAP9), U2.L11 (VDD_SOC_CAP10)
GND: C85.2, C86.2, C87.2, C88.2, C89.2, C90.2, C91.2, C92.2, C93.2, C94.2, C95.2, C96.2, C97.2, C98.2, C99.2, C100.2, C101.2, C102.2, C103.2, U2.A1 (VSS1), U2.A17 (VSS2), U2.C3 (VSS3), U2.C7 (VSS4), U2.C11 (VSS5), U2.C15 (VSS6), U2.E8 (VSS7), U2.E11 (VSS8), U2.F6 (VSS9), U2.F7 (VSS10), U2.F8 (VSS11), U2.F9 (VSS12), U2.F10 (VSS13), U2.F11 (VSS14), U2.F12 (VSS15), U2.G3 (VSS16), U2.G5 (VSS17), U2.G7 (VSS18), U2.G12 (VSS19), U2.G15 (VSS20), U2.H7 (VSS21), U2.H12 (VSS22), U2.J5 (VSS23), U2.J7 (VSS24), U2.J12 (VSS25), U2.K7 (VSS26), U2.K12 (VSS27), U2.L3 (VSS28), U2.L7 (VSS29), U2.L12 (VSS30), U2.M7 (VSS31), U2.M8 (VSS32), U2.M9 (VSS33), U2.M10 (VSS34), U2.M11 (VSS35), U2.M12 (NGND_KEL0), U2.N3 (VSS36), U2.N5 (VSS37), U2.R3 (VSS38), U2.R5 (VSS39), U2.R7 (VSS40), U2.R11 (VSS41), U2.R16 (VSS42), U2.R17 (VSS43), U2.T14 (VSS44), U2.U1 (VSS45), U2.U14 (VSS46), U2.U17 (VSS47); also elsewhere on the board
LDO2_3V3: C85.1, C86.1, C91.1, U2.N13 (VDD_HIGH_IN), U2.P12 (VDD_SNVS_IN); also elsewhere on the board
VDD_ARM_SOC_IN: C87.1, C88.1, C89.1, C90.1, U2.H9 (VDD_SOC_IN1), U2.H10 (VDD_SOC_IN2), U2.J9 (VDD_SOC_IN3), U2.J10 (VDD_SOC_IN4), U2.K9 (VDD_SOC_IN5), U2.K10 (VDD_SOC_IN6); also elsewhere on the board
VDD_HIGH_CAP: C100.1, C102.1, U2.R14 (VDD_HIGH_CAP1), U2.R15 (VDD_HIGH_CAP2); also elsewhere on the board

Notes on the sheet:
[1] Hardware Development Guide for the i.MX 6UltraLite Application Processor, Rev. 3, 09/2018
VDD_SNVS_IN tied to VDD_HIGH_IN if battery not used. [1] pg 28

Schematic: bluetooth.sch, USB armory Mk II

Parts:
C104: 0.1uF; SM0201; Rating 10V/20%; Mfg PN GRM033R61A104ME15D
TP8, TP9: TestPoint; TP
U11: ANNA-B112; Mfg PN ANNA-B112-01B

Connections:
/Bluetooth/ANT_INT: U11.5 (ANT_INT), U11.6 (ANT)
/Bluetooth/ANT_PCB: U11.1 (ANT_PCB)
BT_RESET_B: U11.12 (~RESET); also elsewhere on the board
BT_SWDCLK: U11.39 (SWD_CLK); also elsewhere on the board
BT_SWDIO: U11.40 (SWD_IO); also elsewhere on the board
BT_SWITCH_1: U11.30 (GREEN/SWITCH_1); also elsewhere on the board
BT_SWITCH_2: U11.38 (SWITCH_2); also elsewhere on the board
BT_UART_CTS: U11.35 (UART_CTS); also elsewhere on the board
BT_UART_DSR: U11.26 (UART_DSR); also elsewhere on the board
BT_UART_DTR: U11.25 (UART_DTR); also elsewhere on the board
BT_UART_RTS: U11.34 (UART_RTS); also elsewhere on the board
BT_UART_RX: TP9.1, U11.19 (UART_TXD); also elsewhere on the board
BT_UART_TX: TP8.1, U11.20 (UART_RXD); also elsewhere on the board
DCDC_3V3: C104.1, U11.9 (VCC); also elsewhere on the board
GND: C104.2, U11.4 (GND), U11.7 (GND), U11.8 (GND), U11.10 (GND), U11.11 (GND), U11.17 (XL1), U11.18 (XL2), U11.32 (GND), U11.33 (GND), U11.41 (GND), U11.42 (GND), U11.43 (GND), U11.44 (GND), U11.46 (GND), U11.47 (GND), U11.48 (GND), U11.49 (GND), U11.50 (GND), U11.51 (GND), U11.52 (GND); also elsewhere on the board

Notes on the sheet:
When using internal oscillator XL1 and XL2 should be connected to ground ([1] pg 11).
Use internal antenna.
[1] ANNA-B112 - System Integration Manual (UBX-18009821-R07)
There is no strict requirement of adding bypass capacitance to the supply net close to the module. But depending on the layout of the supply net and other consumers on the same net, bypass capacitors might still be beneficial. [1] pg 40
NFC_1 and NFC_2: floating Not found any reference, but should be safe as they are also GPIO.
Integrated antenna module placed - in the corner of the PCB: ANT_PCB -> GND pattern ANT_GND_x -> NC - on the side of the PCB: ANT_PCB -> NC ANT_GND_x -> GND [1] pg 14
RESET_N: 13 kOhm internal pull-up. [2] pg 28
[2] ANNA-B112 - Data Sheet (UBX-18011707-R04)
It has been witnessed that the ANNA-B112 can be back-powered via UART pins. To turn completelly off the module all the interfaces pins should be kept low.

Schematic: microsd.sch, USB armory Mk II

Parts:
C37: 0.22uF; SM0201; Rating 6.3V/20%; Mfg PN GRM033R60J224ME15D
C105: 10uF; SM0402; Rating 10V/20%; Mfg PN CL05A106MP8NUB8
C106: 0.1uF; SM0201; Rating 10V/20%; Mfg PN GRM033R61A104ME15D
J1: microSD slot; MOLEX_503182-1852; Mfg PN 503182-1852
R54: 22R; SM0201; Rating 50mW/1%; Mfg PN CRCW020122R0JNED
R55, R56: 10K; SM0201; Rating 50mW/1%; Mfg PN CRCW020110K0JNED
U2: MX6UL-VM; SOT1534-2; Mfg PN MCIMX6Z0DVM09AB
U12: PUSB3TB6; SOT1358-1; Mfg PN PUSB3TB6AZ
U20, U21: TPD1E10B06; X1SON-2; Mfg PN TPD1E10B06DPYR

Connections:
/microSD/SD1_CLK: J1.5 (CLK), R54.1, U12.2 (CH2)
/microSD/SD1_CLK_R: R54.2, U2.C1 (SD1_CLK)
/microSD/SD1_CMD: J1.3 (CMD), R55.2, U2.C2 (SD1_CMD), U12.6 (CH5)
/microSD/SD1_DATA0: J1.7 (DAT0), R56.2, U2.B3 (SD1_DATA0), U12.7 (CH6)
/microSD/SD1_DATA1: J1.8 (DAT1), U2.B2 (SD1_DATA1), U12.1 (CH1)
/microSD/SD1_DATA2: J1.1 (DATA2), U2.B1 (SD1_DATA2), U12.5 (CH4)
/microSD/SD1_DATA3: J1.2 (CD/DAT3), U2.A2 (SD1_DATA3), U12.3 (CH3)
DCDC_3V3: C105.1, C106.1, J1.4 (VDD), U21.1; also elsewhere on the board
GND: C37.2, C105.2, C106.2, J1.6 (VSS), J1.DT (DETECT), J1.P1 (SHIELD), J1.P2 (SHIELD), J1.P3 (SHIELD), J1.P4 (SHIELD), J1.P5 (SHIELD), U12.4 (GND), U20.2, U21.2; also elsewhere on the board
SD1_CD_B: J1.SW (SWITCH), U20.1; also elsewhere on the board
SD_3V3_1V8: C37.1, R55.1, R56.1, U2.C4 (NVCC_SD1); also elsewhere on the board

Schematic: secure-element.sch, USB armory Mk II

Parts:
C5, C107: 0.1uF; SM0201; Rating 10V/20%; Mfg PN GRM033R61A104ME15D
R29: 10K; SM0201; Rating 50mW/1%; Mfg PN CRCW020110K0JNED
U4: SE050; SOT1969-1; Mfg PN SE050C1HQ1/Z01SCZ
U13: ATECC608B-DNP; UDFN-8; Mfg PN ATECC608B-MAHDA

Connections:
DCDC_3V3: C5.1, C107.1, R29.1, U4.12 (VIN), U13.8 (VCC); also elsewhere on the board
GND: C5.2, C107.2, U4.1 (ISO_14443_LB), U4.14 (ISO_7816_RST_N), U4.17 (ISO_14443_LA), U4.19 (VSS), U4.21 (Thermal), U13.4 (GND), U13.T (THERMAL); also elsewhere on the board
I2C1_SCL: U4.10 (I2C_SCL), U13.6 (SCL); also elsewhere on the board
I2C1_SDA: U4.9 (I2C_SDA), U13.5 (SDA); also elsewhere on the board
unnamed: U4.15 (VOUT), U4.18 (VCC)
SE050_ENA: R29.2, U4.11 (ENA); also elsewhere on the board

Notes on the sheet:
Optional, not mounted on retail units.

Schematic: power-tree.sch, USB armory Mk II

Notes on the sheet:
USB1_VBUS
USB2_VBUS
USB_VBUS
i.MX6ULZ
NVCC_ENET
VDD_SOC_IN
VDD_HIGH_IN
VDD_SNVS_IN
USB_OTG1_VBUS
VDDA_ADC_3P3
NVCC_GPIO
NVCC_CSI
NVCC_NAND
NVCC_SD1
NVCC_LCD
NVCC_UART
USB_OTG2_VBUS
NVCC_DRAM
NVCC_DRAM_2P5
Type-C port controller
VIN
FUSB303 - RCPT
TUSB320 - PLUG
Bluetooth module
u-blox ANNA-B112
Type-C debug switch
FSA1208
push-push slot
microSD
4GB/8GB/16GB eMMC
eMMC
DDR3L 512 MB / 1 GB
DDR
Microchip ATECC608A
Secure Element 1
Logic inverter
SN74LVC1G04
Type-C power switch
NX5P3090
A10

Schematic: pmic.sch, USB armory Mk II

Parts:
C1, C2, C3, C23: 4.7uF; SM0402; Rating 10V/20%; Mfg PN ZRB15XR61A475ME01D
C4, C8, C9, C10, C14, C15, C25: 1uF; SM0201; Rating 10V/20%; Mfg PN GRM033R61A105ME15D
C11, C12: 0.1uF; SM0201; Rating 10V/20%; Mfg PN GRM033R61A104ME15D
C13: 2.2uF; SM0402; Rating 25V/20%; Mfg PN GRM155R61E225ME15D
C16: 47uF; SM0603; Rating 6.3V/20%; Mfg PN GRM188R60J476ME15D
C17, C18, C20, C21, C22, C24, C26, C32: 10uF; SM0402; Rating 10V/20%; Mfg PN CL05A106MP8NUB8
C27: 0.47uF; SM0201; Rating 6.3V/20%; Mfg PN GRM033R60J474ME90D
L1, L2, L3: 1uH; SM0603; Rating 1.7A/20%/128mOhm; Mfg PN DFE18SAN1R0MG0L
R1, R2, R22: 100K; SM0201; Rating 50mW/1%; Mfg PN CRCW0201100KJNED
U1: MC34PF1510A6EP; SOT1369-4; Mfg PN MC34PF1510A6EP

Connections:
/PMIC/LICELL: C12.1, U1.31 (LICELL)
/PMIC/VCORE: C14.1, U1.24 (VCORE)
/PMIC/VDIG: C15.1, U1.23 (VDIG)
/PMIC/VSNVS_3V: C27.1, R1.1, R22.1, U1.30 (VSNVS)
/PMIC/VSYS: C1.1, C2.1, C3.1, C4.1, C8.1, C9.1, C16.1, R2.1, U1.11 (VLDO3IN), U1.14 (SW3IN), U1.17 (SW2IN), U1.20 (VLDO2IN), U1.26 (SW1IN), U1.28 (VLDO1IN), U1.35 (VSYS1), U1.36 (VSYS2)
DCDC_3V3: C11.1, C24.1, C26.1, L3.2, U1.4 (VDDIO), U1.15 (SW3FB); also elsewhere on the board
DDR_1V35: C10.1, C20.1, C22.1, L2.2, U1.16 (SW2FB), U1.22 (VINREFDDR); also elsewhere on the board
DDR_VREF: C25.1, U1.21 (VREFDDR); also elsewhere on the board
EMMC_1V8: C32.1, U1.29 (VLDO1); also elsewhere on the board
GND: C1.2, C2.2, C3.2, C4.2, C8.2, C9.2, C10.2, C11.2, C12.2, C13.2, C14.2, C15.2, C16.2, C17.2, C18.2, C20.2, C21.2, C22.2, C23.2, C24.2, C25.2, C26.2, C27.2, C32.2, U1.5 (VDDOTP), U1.7 (STANDBY), U1.32 (GND), U1.40 (GND), U1.41 (EP); also elsewhere on the board
I2C1_SCL: U1.3 (SCL); also elsewhere on the board
I2C1_SDA: U1.2 (SDA); also elsewhere on the board
LDO2_3V3: C21.1, U1.19 (VLDO2); also elsewhere on the board
unnamed: L1.1, U1.25 (SW1LX)
unnamed: L2.1, U1.18 (SW2LX)
unnamed: L3.1, U1.13 (SW3LX)
unnamed: R1.2, U1.6 (PWRON)
unnamed: R2.2, U1.8 (ONKEY)
PMIC_WDI: R22.2, U1.1 (WDI); also elsewhere on the board
SD_3V3_1V8: C23.1, U1.12 (VLDO3); also elsewhere on the board
VDD_ARM_SOC_IN: C17.1, C18.1, L1.2, U1.27 (SW1FB); also elsewhere on the board
VSYS_5V: C13.1, U1.37 (VIN); also elsewhere on the board

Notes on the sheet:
[1] PF1510 - Power management integrated circuit (PMIC) for low power application processors Rev 1.0, 23 May 2018
EPAD: Tie to the inner and external ground planes through vias to allow effective thermal dissipation. [1] pg 8
400 mA
300 mA
1 A
10 mA
Power rails
ULL/ULZ: NXP MC34PF1510A6EP UL: NXP MC32PF1510A3EP


Board: 6 copper layers, 55.6 x 19.6 mm, 195 parts (0 on the bottom side), 172 nets.

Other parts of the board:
FSC_LOGO_NO_TEXT_SMALL: G***; FSC_LOGO_NO_TEXT_SMALL
FSC_LOGO_NO_TEXT_SMALL#2: G***; FSC_LOGO_NO_TEXT_SMALL
Ref**: Val**; IP_LOGO_NO_TEXT_SMALL
Ref**#2: Val**; IP_LOGO_NO_TEXT_SMALL

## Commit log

2014-10-03 initial public release of alpha prototype
    [RAM.sch, USB.sch, armory.kicad_pcb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]
2014-11-13 add reference linux kernel configuration
    [RAM.sch, USB.sch, armory.kicad_pcb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]
2014-12-14 new kernel config
    Added .dts file required for the NOUSBH board
    Added kernel config for linux 3.18.0 with my local changes
    - enable SECCOMP
    - enable initrd support
    - switch IO scheduler to "noop"
    - change default root device to /dev/mmcblk0p1
    - enable more powersave drivers
    - enable FUSE support
    - enable msdosfs
    - enable ntfs
    - enable squashfs
    - enable reboot on panic/oops/hung task
    - enable SAHARAv4
    - filter access to /dev/mem
    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
2015-01-09 enable NAT/masquerading and common wifi dongle drivers
2015-01-09 Add devicetree source file
2015-01-09 Add heartbeat led support
2015-01-15 Mk I design
    [RAM.sch, USB.sch, armory.kicad_pcb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]
2015-02-21 re-licensing to CERN OHL v1.2
    [RAM.sch, USB.sch, armory.kicad_pcb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]
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2015-03-25 Split out common device-tree content into an include file.
2015-04-08 Update 3.19 kernel config
    Add frequency scaling driver and XTS crypto block mode
2015-04-09 Update frequency scaling operating points
    The USB armory MkI mounts a i.MX534 for which the maximum
    suggested frequency is 800MHz.
2015-04-24 Update device tree files
    Move the otg section from include file to
    peripheral device tree file.
2015-04-24 Remove nousb device tree file
    Delete device tree file needed for nousbh1 beta USB armories.
2015-04-24 Fix device tree includes
2015-04-27 Fix device tree include file
2015-04-27 Add gpio device tree file
2015-05-05 Add JTAG adapter schematic
    [jtag-breakout.sch]
2015-06-11 technical diagram for enclosure
2015-07-15 remove obsolete alpha rev., add lib cache to mark-one (https://forum.kicad.info/t/disruptive-change-coming-to-schematics/727)
    [RAM.sch, USB.sch, armory.kicad_pcb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]
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2015-10-22 Add verified boot support
    U-Boot patch and devicetree files to enable verified boot
    on USB armory.
2015-11-27 Add device tree for SPI
2015-11-27 Update spi device tree
2015-11-30 Remove spidev from device tree
2015-12-04 Add device tree for I2C
2015-12-04 Update kernel 4.3 config
    Adds i2c char device module.
2016-02-09 Update kernel config
    Add some wifi adapter drivers.
2016-03-14 print key type before password prompt
2016-04-13 add CA certificates so that INTERLOCK Signal plugin can send attachments
2016-06-21 devicetree: Remove sahara node
    sahara node is already included in imx53.dtsi.
2016-06-21 devicetree: explicitly set IOMUX values
    Do not relay on bootloader values (e.g. using 0x80000000 settings).
2016-06-21 devicetree: remove vpu node
    VPU is already enabled in imx53.dtsi.
2016-06-28 Update kernel config
    Add stack protector and DMA contiguous access support.
2016-06-28 Re-licensing dts files
    Use GPL/X11 dual licence for devicetree files.
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2016-07-01 add mxc-scc2 driver in buildroot image and fix invalid date reset format
2016-10-12 buildroot fixes: ensure LED is turned on last at shutdown, tidy overlay structure
2016-11-16 set default LED timeout if not specified
2016-12-13 Update devicetree files
    Add dts files for kernel 4.9. Move old dts files to dts-4.8 directory.
2017-02-15 PaX/Grsecurity 4.9 for USBArmory: (#38)
    PaX/Grsecurity 4.9 with BBR enabled for the case of tor-router usage.
2018-07-10 copyright change
    [RAM.sch, USB.sch, armory.kicad_pcb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]
2018-10-30 Fix buildroot devicetree URLs
2018-11-01 Add devicetree with CAAM for i.MX6UL PICO board
2018-11-01 Add INTERLOCK buildroot target for i.MX6UL PICO board
2018-11-01 Bump U-Boot in INTERLOCK buildroot for i.MX6UL PICO
2018-11-01 Add README for INTERLOCK i.MX6UL PICO board
2018-11-01 Add i.MX6UL PICO secure boot support
2018-11-02 imx6ul-pico: add patch for disabling U-Boot CLI
2019-01-30 Update buildroot kernel version and dependencies, apply the following overlay changes:
    - align initial system date to current year
    - move entropy wait before initial partition creation
2019-03-19 Fix i2c, spi and gpio devicetree
    iomux pinctrl configuration should be placed in module structure instead
    of the 'iomux' one. This behaviour seems to have changed in recent
    kernels.
2019-03-20 Fix I2C, GPIO and SPI devicetree files
    Remove container node from iomuxc nodes.
2019-03-20 Add pinctrl-names attribute to devicetree files
2019-04-01 move mark-one specific design files in own directory
    [jtag-breakout.sch]
2019-04-03 Set SION bit for i2c pads
2019-05-08 link mark-one pcb SVGs
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2019-06-06 Update usbarmory mark-two devicetree
    Add support for bluetooth GPIOs (switches, reset, etc.)
2019-06-06 Fix DDR calibration values
2019-06-10 Disable over current detection for i.MX6UL
2019-06-10 i.MX6UL and i.MX6ULL device tree files update
    - enable hardware flow control on bluetooth uart
    - set plug USB port to peripheral mode
    - tidying
2019-06-12 remove imx6ul pico configuration and replace it with mark-two specific one
2019-06-14 USB armory mark-two debug accessory
    [accessory.kicad_pcb, accessory.sch, debug.sch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]
2019-06-20 comment FUSB303 i2c enable lines in u-boot patches
2019-06-27 Do not reloacate fdt initrd images
    Required to boot Linux on boards with 1GB RAM.
2019-06-27 Add U-Boot patches for boards with 1GB RAM
2019-07-22 Add distro_bootcmd support for both mmc devices
2019-07-23 Fix patch for upstream to support disabled console
    A revert of commit 80a48dd47e3bf3ede676fae5a630cb6c80de3e69
    is required to make the build successful, otherwise the following
    error is returned at the final linking stage:
    ...
    LDS u-boot.lds
    LD u-boot
    u-boot contains unexpected relocations: R_ARM_NONE
    R_ARM_RELATIVE
    make: *** [Makefile:1775: checkarmreloc] Error 1
2019-08-01 Fix IOMUX configuration for UART1
2019-08-02 Fix IOMUX configuration for UART1 in U-Boot patch
2019-08-27 Remove GPIO 9 from sd regulator.
2019-09-25 Fix U-Boot mmc initialization
    Move iomux initialization for eMMC and microSD back to
    board file as the initialization via dts file appears buggy.
2019-11-07 USB armory Mk II project files + tidying
    [accessory.kicad_pcb, armory.sch, bluetooth.sch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]
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2020-03-18 add devicetree file for linux 5.4
2020-04-02 Limit distro_bootcmd to scan a single boot device
    Regardless of the boot device, the distro_bootcmd scans both,
    microSD and eMMC, for boot scripts presence.
    A situation can arise where the U-Boot is booted from one device,
    and the Linux boot scripts are read from the other, preventing
    a complete boot from the expected device.
2020-04-02 Remove not required device tree blocks
2020-04-10 Add Mk II JTAG schematics
    [jtag-breakout.sch]
2020-04-24 Add DCD file for i.MX6ULZ 512MB
    [imx6ulz-512mb.cfg]
2020-04-24 DCD vaild for i.MX6 UltraLight and ULL as well
    [imx6ul-512mb.cfg]
2020-05-25 Add uSD and eMMC configuration to DCD
    [imx6ul-512mb.cfg]
2020-06-11 Use imx6ull in devicetree instead imx6ulz
    This fix frequency scaling issues on kernels 5.4.x
2020-06-15 Fix verification boot for U-Boot 2020.04
    Remove the 'signature' devicetree block form imx6ul-usbarmory.dts
    as it goes in conflict with the one specified in usbarmory.its.
2020-06-22 Fix bluetooth module pin SWDIO IOMUX configuration
2020-07-30 add missing device_type information on memory nodes
2020-09-17 Fix IOMUX configuration for LEDs
2021-03-04 update devicetree
    Remove hardware flow control for bluetooth serial port
    due to errata [1].
    [1] https://github.com/f-secure-foundry/usbarmory/wiki/Errata-(Mk-II)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
2021-03-10 align imx6ul devicetree to kernel 5.10
2021-06-14 add USB armory Mk II rev. γ
    [armory.sch, bluetooth.sch, boot.sch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]
2021-06-14 add USB armory Mk II rev. γ STEP file
2021-09-20 links update
    [RAM.sch, USB.sch, armory.kicad_pcb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]
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2021-11-23 Revert "Compile RNGB driver as module"
    This reverts commit 99c710d7c7e7e14902887094457c5fd03dc011d2.
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2021-11-26 add errata
    [accessory.kicad_pcb]
2022-03-16 rename organization
    [RAM.sch, USB.sch, armory.kicad_pcb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]
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2023-11-10 Fix comments
    [usb.kicad_sch]
2025-08-28 license/copyright update
    [RAM.sch, USB.sch, accessory.kicad_pcb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]

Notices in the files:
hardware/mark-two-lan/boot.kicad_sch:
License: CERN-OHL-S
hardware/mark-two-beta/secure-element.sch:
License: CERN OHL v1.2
